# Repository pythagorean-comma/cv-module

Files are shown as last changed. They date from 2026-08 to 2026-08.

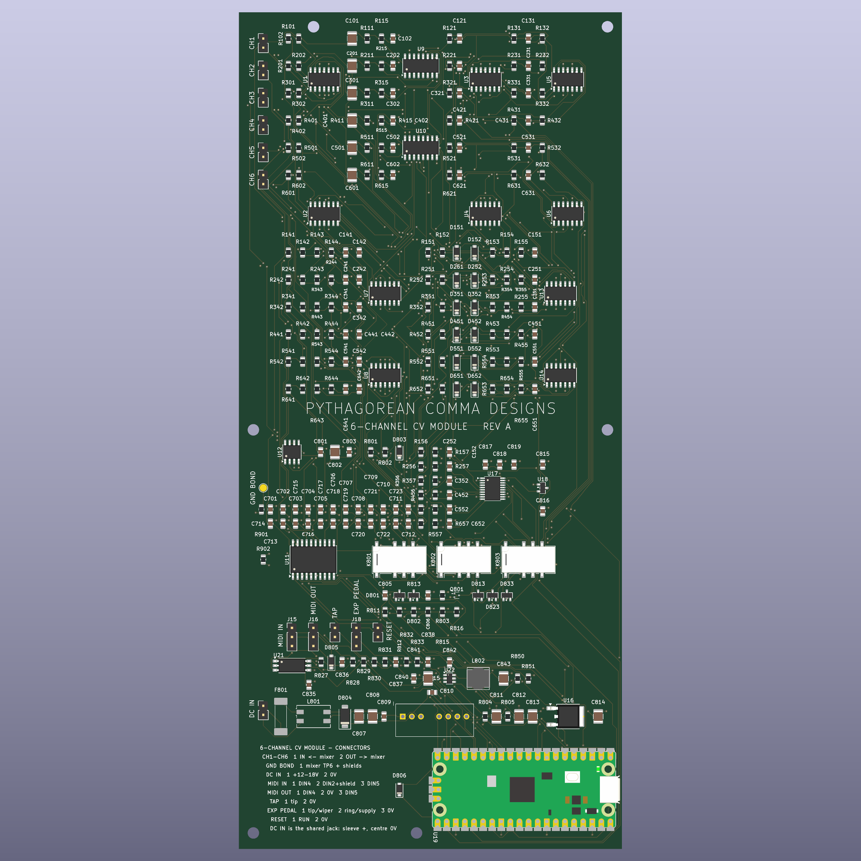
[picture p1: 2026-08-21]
docs/cv-module-top.png

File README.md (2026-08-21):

# cv-module

Per-string CV generation for a six-string guitar effects box: six analogue VCAs
(SSI2164) set per-string levels, and the audio never enters the digital domain.

The module hangs off the six `RV{n}01` level-control positions of
[`summing-mixer`](../summing-mixer), replacing its per-channel trimmers. That
board is **fabricated**, so this repo consumes its interface at a pinned commit
and never writes to it — see [`contract/PINNED.md`](contract/PINNED.md).

```
6 x Nu capsule -> Nexus-GK -> summing-mixer ---- RV{n}01 socket ---- [this]
                                    ^                                  |
                                    +------------ SIN{n} --------------+
```

## Status

Green end to end. `verify.py` passes, `test_verify.py` catches all 112 planted
faults, DRC is at zero, no net is unrouted, and the fabrication package is
written.

| | |
|---|---|
| netlist | 290 parts, 185 nets, 825 pin connections |
| schematic | 0 merges, 0 breaks, 0 stranded pins; ERC clean, `ERC_ALLOWED` empty |
| board | 106.9 × 233.5 mm, 4 layers. 5114 segments, 1142 vias, one track width (0.2 mm), one via size (0.7/0.3), no signal copper on either reference plane |
| routing | every millimetre by KiCadRoutingTools via `krt.py` |
| section 5 constraints | checked mechanically; see `docs/constraints.md` |
| fixings | six, derived from `placement.mounting_deflection()`, each in a plane void |
| silkscreen | title block, connector legend generated from the netlist, 274 designators |
| fabrication package | `fab/` — 9 gerbers, drill, job file, CPL, `ORDER.md` |
| deferred blocks | none. `design.DEFERRED` and `design.UNSPECIFIED` are both empty |

Documents to look at: the [schematic](docs/cv-module-schematic.pdf), the
[layout](docs/cv-module-layout.pdf) one page per copper layer, and a
[render](docs/cv-module-top.png).

**Caveats worth knowing before ordering.** One capacitor is genuinely short on DC
bias — `C840` gives 1.65 µF at 12 V against TI's "2.2 µF or higher" and wants a
higher-voltage part in the same 1210 land. Three Murata lines have no bias curve
here and are reported unchecked. And no check in this repo opens a datasheet: the
netlist comparison is pad number against pin number, so a wrong package passes
everything — see [`footprint-audit.md`](docs/footprint-audit.md), which caught
three.

## Run it

Nothing to install. Stdlib only, following the mixer's own rule that "there is
no `requirements.txt` because there is nothing to install". KiCad 10 is not
optional: `verify.py` runs `kicad-cli` twice, `gen_pcb.py` needs its bundled
Python for `pcbnew`, and `gen_plots.py` plots the schematic, layout and render.

```bash
./build.sh
```

Regenerates the netlist, schematic, project, BOM, generated docs, plots and the
fabrication package, then verifies the board on disk. It never writes the board.
It checks for KiCad first and stops if it is missing; it does not check for
KiCadRoutingTools, because `krt.py` is not one of its stages.

### The three things that do write the board

None of these is in `build.sh`:

```bash
python3 gen_pcb.py --discard-routing   # place, pour and stitch, from nothing
python3 krt.py                         # route it; --commit keeps the result
python3 returns.py                     # add ground stitches; --commit writes
```

`gen_pcb.py` destroys all signal copper. It writes a fresh board with the
footprints placed and the planes poured and nothing else — use it to start again
from nothing, never to make a change. It refuses without `--discard-routing`.

`krt.py` writes a candidate, `out/cv-module-krt.kicad_pcb`; only `--commit`
touches the tracked board. Scope decides what it destroys: `--nets "ENVA*"`
re-lays those six and leaves the rest alone, a bare `python3 krt.py` re-lays
every net.

`returns.py` only adds ground stitches, so it cannot destroy anything. Re-run it
after any re-route. `mounts.py` and `silk.py` are the same shape.

**To move a netlist change onto the routed board**, use KiCad's **Tools → Update
PCB from Schematic** against `out/cv-module.kicad_sch`, which `build.sh`
regenerates. That is the only sync path.

### Toolchain notes

`krt.py` is the one thing here that is not stdlib-only, and it is a subprocess
for that reason — the tool needs numpy, scipy and shapely. Give it an interpreter
of its own, `~/code/KiCadRoutingTools/krt-venv` or `$KRT_PYTHON`; it refuses with
instructions if it cannot find one. See
[`routing-tool.md`](docs/routing-tool.md#installing-the-tools-dependencies).

`gen_pcb.py` re-runs itself under KiCad's bundled interpreter, because `pcbnew`
is a SWIG extension that exists nowhere else, then re-runs `gen_project.py` —
`SaveBoard()` rewrites the project file with KiCad's defaults and takes every
design rule with it.

`contract/socket.py` finds the mixer at `$SUMMING_MIXER`, then
`../summing-mixer`, then `~/code/summing-mixer`. **Keep the two as siblings,
never nested** — and never run `git` from a directory containing both.

## What this repo takes from the mixer, and what it does not

The mixer is a fabricated hardware interface this module references. Referencing
an interface does not mean importing another project's Python:

| | |
|---|---|
| **the interface** — `design.py`, `source.py`, `fab/mechanical-*.json` | read at the pinned commit through `contract/socket.py`, with `git show`. Never copied |
| **the KiCad plumbing** — `sexp` `kisch` `symlib` `kicad` `kisim` | copied into [`toolchain/`](toolchain/PROVENANCE.md). Ours, and modifiable |

The mixer's root is never on `sys.path`. `delta.py` expresses this module's
effect as a delta against the mixer's *own* model, which only works while that
model is the mixer's and not a fork of it.

## What is where

`CLAUDE.md` carries the working rules and the full repo layout. In short:
`design.py` holds the values, derivations and netlist; `verify.py` checks them
against KiCad's own export and `test_verify.py` proves those checks can fail;
`constraints.py` and `delta.py` ask whether the constraints have mechanisms and
what this module costs the existing design; `placement.py`, `krt.py`,
`returns.py`, `mounts.py` and `silk.py` are the board. `docs/` is what a person
reads; `out/` is what another tool reads; `fab/` is what a fabricator is given.

## Open

1. **`MEASURED["noise_floor"]`** — a meter on the mixer's mono output, and the
   only one of the three measurements that can be taken before this board
   exists. It is the most load-bearing unknown here: across its declared range
   the module costs **0.01 dB or 0.79 dB quiescent, 0.08 dB or 3.13 dB while the
   lead feature runs**. It also gates a component value — below 81 µV, `R_IN`
   should move from 12k1 to 7.5 kΩ. [`bench.md`](docs/bench.md).

2. **`MEASURED["mcu_dcdc_efficiency"]` and `["pico_smps_efficiency"]`** — two
   ammeters after fabrication. Confirmations rather than gates: floors of 53 %
   and 45 % against declared ranges starting at 75 and 86. Note that the board
   has no provision for the first — `VA_RAW` has no series element at U22's VIN,
   so that measurement needs a lifted pin or a fitted 0 Ω link. The second is
   free: `D806` is already in series with `VSYS`.

3. **The order form.** `fab/ORDER.md` lists what is not derivable from anything
   here: surface finish, mask and silkscreen colour, electrical test,
   panelisation, IPC class, quantity.

4. **Fiducials and test pads** — not fitted. Three fiducials are derived and
   costed; the test-point case is that no analogue rail and not `MAGND` itself
   has any probe point on the board.

5. **The south-east corner** is 57 mm from its nearest fixing and carries the
   USB socket. Grow the board, move the module, or accept it — all three are
   decisions, so `placement.mounting_reach()` reports the distance rather than
   taking one.

6. **Review the copper.** 844 router vias against an earlier seed's 595 is 33 %
   more perforations of both reference planes for 9.8 % less track. No check
   grades that trade. The recommendation is about scope: re-route a region, not
   the board.

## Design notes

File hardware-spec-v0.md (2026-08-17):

# Hardware spec v0 — per-string CV module

**Purpose:** seed document for a schematic/PCB spike. This is not a design
discussion — the discussion is in the other five files. This is the extracted,
buildable specification, with every value either stated or explicitly marked as
*compute*, and every unknown explicitly marked as *BLOCKED* or *TBD*.

Read `00-current-state.md` for why any of these choices are what they are.

---

## 0. Scope of the spike

**In scope:** the CV generation module — controller, CV chain, envelope sensing,
coarse pad relays, fail-safe. One board.

**Out of scope:** the existing summing mixer (already fabricated), the VCA board
if it ends up separate, the enclosure, the UI panel.

**Deliverable of the spike:** a netlist whose connectivity is machine-checked, all
component values derived rather than guessed, a PCB floorplan with a defensible
ground strategy, and a written list of everything that had to be assumed.

---

## 1. BLOCKED — must be resolved before drawing

Three items. Two of them only Tim can answer.

### 1.1 The module's supply — RESOLVED, see `supply-decision.md`

> **DECIDED.** One shared DC inlet → an **isolated DC-DC at ≥300 kHz** → ±12 V for
> a small audio domain plus +5 V / +3V3 for everything else.
>
> Three reasons, the third decisive:
> 1. **The negative rail only needs ~44 mA**, not ~100 mA — CV and envelopes are
     >    unipolar and run single-supply. Enforce that domain split on the schematic.
> 2. **The mixer already runs a 45 kHz charge pump.** A VCA is a multiplier, so two
     >    supply ripples intermodulate into the audio band. Rule:
     >    **|f_module − 45 kHz| > 20 kHz**, target ≥300 kHz. *Do not use an ICL7660S /
     >    TC1044S with the boost pin — that sets exactly 45 kHz.*
> 3. **Sharing a DC inlet non-isolated creates a second ground bond**, breaking the
     >    "exactly one bond" rule. Isolation preserves it by construction.
>
> Still to look up: the mixer's actual rail voltages and DC input range, from
> `design.py` alongside `NEGATIVE_RAIL_DROP` / `output_swing()` / `clipping_peak()`.

<details>
<summary>Original text, kept for the record</summary>

### 1.1 The module's bipolar supply — genuinely undecided

The SSI2164 needs **±4 V to ±18 V** [S]. The parent doc forbids the module drawing
anything from `VREG`, `V+` or `V−` (*"Every mA on V− costs 65 mV of rail"*). So the
module needs its own bipolar rail, roughly **60–80 mA** with the op-amps — and
nothing in any document decides where it comes from.

| Option | Cost |
|---|---|
| Separate mains inlet, linear ±15 V | Quietest. Second inlet, transformer, board area, heat |
| Single DC inlet + low-noise charge pump for the negative rail | One inlet. A switching aggressor, though at low current |
| Single DC inlet + DC-DC | Smallest. The exact thing the enclosure argument exists to avoid |

**This changes board area, connector count, thermal design and the entire
grounding plan. Decide it before drawing anything.**

</details>

### 1.2 The interface contract with the existing boards

Needed from the existing repo, which I have never seen:

- `RV{n}01` / `CHANNEL_POT_FP = CONN_FP[3]` — connector part, pitch, gender, and
  the exact pin order for `PIN{n}` / `SIN{n}` / `AGND`
- `fab/mechanical-*.json` — board outline, mounting holes, keep-outs
- `DC_BLOCK_VALUE` and the actual `RIN` value, so the 10 kΩ load and the 31.8 Hz
  corner can be checked rather than assumed
- `MEASURED["noise_floor"]` — if it has been measured since

### 1.3 CV architecture — pick one, they are different boards

**Recommendation: PWM.** Fewer parts, no chip-select question, and the filter it
needs is mandatory anyway. But it is a decision, not a default.

| | PWM | DAC |
|---|---|---|
| Parts | 6 MCU PWM pins → 74AHC541 → filter | SPI → DAC → filter |
| CS/framing | none | 8 CS pulses (DAC8568) or one (6× AD5683R chain) |
| Simultaneous update | no (≤33 µs skew, acceptable) | LDAC |
| Extra BOM | 74AHC541 ~£0.30 | DAC ~£10 |

---

### 1.4 The VCA element is no longer settled — but does not block the spike

`element-revisit.md` reopens SSI2164 vs THAT2180 vs **THAT4301**. Summary:

- The control-law argument that originally won it for the SSI2164 is **cancelled by
  the divider ratio** the deep dive later added.
- **Crosstalk is the binding constraint on the lead feature**, and the SSI2164 puts
  four channels on one die. The THAT parts are one channel per package.
- **THAT4301** contains a VCA *and* an RMS detector with a matched 6.5 mV/dB law
  *and* three op-amps — collapsing the analogue compressor (feature 12) and the
  buffer/I–V/servo trio into the same package. Six packages total, against ~7 or
  ~11 for the alternatives.

**This does not block drawing.** All three are current-in/current-out Blackmer-class
parts with identical surrounding topology. Draw with the SSI2164, keep the footprint
choice isolated, and note the variants. Phase 1.5 becomes a three-way bench-off.

**But check the mixer's rail voltages first** — the THAT4301 needs ±7 to ±15 V and
is out below that.

---

## 2. Look up before committing values (does not block topology)

**SSI2164 control-port structure.** Our working figures — *"current-summing node,
nominally 10 kΩ, internal 10:1 divider, −33 mV/dB"* — came from a research pass,
not from a first-hand read. Before fixing any resistor value, confirm from the
datasheet: the actual VC input structure, the recommended summing arrangement, the
input impedance, and the standard **+3300 ppm/°C tempco resistor** practice for the
control divider. Twenty minutes, and it sets half the passive values on the board.

---

## 3. Block diagram

```
  ┌─ from existing mixer, ×6 ────────────────────────────────────────────────┐
  │  PIN{n} ──[ 10k to AGND ]──[ buffer ]──┬──[ pad relays ]──[ SSI2164 ]──► │
  │                                         │                      ▲          │
  │                                         │                   VC{n}         │
  │                        envelope tap ────┘                      │          │
  │  ◄── SIN{n} ──[ DC servo ]──[ I–V ]────────────────────────────┘          │
  └──────────────────────────────────────────────────────────────────────────┘
                    │                                              ▲
              6× rectifier                                  6× CV filter
                    │                                              ▲
              external SPI ADC ──────┐              ┌── 74AHC541 (Vcc = VREF)
                                     ▼              ▲
                                ┌─ RP2040 ─┐   6× PWM
                                │  USB MIDI │
                                │  DIN MIDI │
                                │  tap / exp│
                                └───────────┘
                                     │
                        AC-coupled charge pump ──► bypass relay
```

---

## 4. Block specifications

### 4.1 Channel front end (×6)

| Net / part | Value | Note |
|---|---|---|
| Load to AGND | **10 kΩ** | Replicates the pot. Keeps `DC_BLOCK_VALUE`'s 31.8 Hz corner. **Verify against the real `RIN`** |
| Buffer | JFET or low-noise op-amp, unity gain | Decouples the socket contract from the VCA operating point. Also the envelope tap point |
| Envelope tap | **1 MΩ** series | ≤0.1 dB loading; shifts the corner ~1 % [D] |
| Coarse pad | 0 / −6 / −12 / −18 dB, 2-bit | Latching relays. Keeps the VCA near unity where its noise costs least |
| VCA | **SSI2164**, 2 packages — **but see `element-revisit.md`; this is now a bench decision** | R_IN 30 kΩ after the buffer (datasheet noise condition), R_OUT *compute* |
| I–V + servo | op-amp, servo corner ~1 Hz | `SIN{n}` must be **zero DC by construction** |

### 4.2 CV chain (×6) — the part that most affects the sound

Control noise is **multiplied** into audible AM at **dg/g = −3.48 per volt** [D].
This block matters more than the controller.

| | Spec |
|---|---|
| Filter | **2-pole, 200–400 Hz**, inverting multiple-feedback |
| | The MFB stage does three jobs: anti-AM filter, offset injection (second input resistor from VREF), and buffering the source from the 2164's control node. Use one stage, not three |
| Filter resistors | **≤22 kΩ** so their Johnson noise (19 nV/√Hz) stays ~13 dB under the source |
| Op-amp | OPA1644 (quad JFET, 3.3 nV/√Hz) or OPA4192 |
| Scaling | Source at 0–5 V through **~15 kΩ** into the 10 kΩ control node → ×0.4 → 2 V span and **−8 dB on all source-referred noise** [D]. *Compute exactly once §2 is resolved* |
| Reference | **MAX6126A25 with the 0.1 µF NR cap** (35 nV/√Hz) or ADR4525C/D. Shared by CV source, ADC and the '541 |
| Polarity | Positive CV **attenuates**. Unipolar 0→+V only ever attenuates — no negative rail needed for CV, and code-near-zero is both loudest and quietest |

If PWM: **12-bit, 30.5 kHz carrier** at 125 MHz → 128 µV ripple after the filter =
**0.0039 dB**, step 0.015 dB/LSB [D]. Phase-stagger the six slices so the buffer
transients don't hit the reference together. Local 1 µF + 100 nF at the '541.

### 4.3 Controller

**RP2040.** On-chip LDO, production to 2041, 16 PWM outputs, PIO if the CV
architecture changes to SPI later. Not a module — bare chip plus QSPI flash and a
crystal, so the power architecture is ours.

Control frame rate **8 kHz** (not 32 kHz — the CV filter kills the aggressor
argument; 125 µs grid is 0.12 % of a sixteenth note [D]).

Needs: USB device (MIDI), DIN MIDI in/out, tap footswitch, expression pedal in,
12 GPIO for relay drive, SPI for the ADC.

### 4.4 Envelope sensing

Six precision rectifiers → RC → **external SPI ADC placed in the analogue
section**, so only SCLK/MOSI/MISO/CS cross the analogue–digital boundary rather
than six analogue traces crossing into the digital region.

Parts: **ADS131M08** (8 simultaneous channels, one CS per read) or **MCP3564**
(SCAN mode into a FIFO). 1–2 kHz sampling is sufficient. **Detect pre-gain**, off
the buffer — post-gain makes it a feedback loop that latches shut.

### 4.5 Relay drive and fail-safe

**Coarse pad:** 12 coils (six 2-bit pads). **2× TPIC6B595** shift registers — same
"one SPI burst plus a latch pulse" discipline as everything else.

> **Highest-probability field failure in the design.** These are *level* drivers.
> Dual-coil latching relays need a 3–10 ms pulse and must then be de-energised, and
> a shift register will hold a coil energised until it burns. **Drive the register's
> OE from a one-shot (74LVC1G123)** so maximum coil-on time is set by an RC,
> independent of register contents. One 6-pin part.

**Fail-safe, two stages:**

1. MCU emits ~10 kHz on a GPIO → two-diode charge pump → MOSFET → bypass relay.
   **Any** stuck state — high, low, hi-Z, crashed, halted clock — collapses the pump
   and drops to bypass. Covers the failure a watchdog IC cannot see: firmware alive,
   CV engine wedged.
2. If the CV source is a DAC8568: supervisor reset → **CLR pin, clear-code register
   set to full scale** = maximum attenuation = hardware mute in ~1 µs, long before a
   relay can transfer (~5 ms).

> **Power-on hazard:** a DAC's POR to zero scale = 0 V = **unity gain = fail-loud**.
> The bypass relay must be de-energised (bypassed) at power-up and stay so until
> firmware has written CVs and kicked the watchdog. Same applies to PWM outputs
> idling low. **Design the power-up sequence explicitly.**

---

## 5. Constraints that must not be violated

From the parent doc, and they are load-bearing:

1. **The module draws nothing from `VREG`, `V+` or `V−`.**
2. **Exactly one bond** between module audio ground and board AGND. Six separate
   returns to six pin-3s, **not commoned in the module**.
3. `SIN{n}` carries **zero DC by construction**.
4. `PIN{n}` sees ~5–10 kΩ, or the 31.8 Hz corner moves.
5. Audio as individually-shielded twisted triads, shields grounded at the
   main-board end only.

---

## 6. Do not invent

If a value or part is not in this document and cannot be *derived* from it, stop
and flag it rather than choosing plausibly. Specifically do not invent: the
connector part or pinout (§1.2), the supply topology (§1.1), the SSI2164 control
port structure (§2), `RIN`, or `DC_BLOCK_VALUE`.

---

## 7. Verification expectations

The parent project's culture is that constraints live somewhere a script can see
them. Match it:

- A `verify.py` that checks the netlist against §5 — one AGND bond, no module load
  on `VREG`/`V±`, six separate returns, 10 kΩ presented at each `PIN{n}`
- Every computed value emitted with its derivation, not just its result
- A BOM with a source and a price per line
- An explicit `ASSUMPTIONS.md` listing everything that had to be guessed

---

## 8. Known-unknowns that do NOT block the spike

These affect whether it sounds good, not whether it can be drawn. Note them and
carry on:

- SSI2164 channel-to-channel crosstalk (target ≤−54 dB per pair)
- SSI2164 control-port voltage-noise density (unspecified)
- Whether the 74AHC-powered-from-a-reference topology is sound (no vendor app note)
- Whether a 250 Hz CV filter is fast enough for the gate feel

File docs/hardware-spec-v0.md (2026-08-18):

# Hardware spec v0 — per-string CV module

**Purpose:** seed document for a schematic/PCB spike. This is not a design
discussion. This is the extracted, buildable specification, with every value
either stated or explicitly marked as *compute*, and every unknown explicitly
marked as *BLOCKED* or *TBD*.

Read [`00-current-state.md`](00-current-state.md) for why any of these choices are
what they are.

---

## ⚠ This is v0, and the design has moved past it in places

**Kept unedited on purpose.** It is the baseline the corrections are measured
against, and rewriting a claim in place would destroy the record of what was
specified versus what was derived. So the numbered sections below say what they
said on day one, and **where a claim has been overturned the answer is somewhere
else.** This table is the index; none of it is restated here, because one copy in
one place is the rule the rest of the repo runs on.

| where | what moved | the current answer |
|---|---|---|
| §2, §4.1, §4.2, §4.5, §1.1, §1.4 | seventeen claims, checked against the SSI2164 datasheet read first-hand. Six move a component value or a part count | [`ssi2164-control-port.md` §7](ssi2164-control-port.md#7-corrections-to-hardware-spec-v0md) |
| §5.2 | *"Six separate returns to six pin-3s"* — **struck.** No mechanism: pairwise crosstalk through a single bond is 122 dB below one string against a −54 dB requirement | `CLAUDE.md`, and `design.FRONT_R` for the arithmetic |
| §5.3, §4.1 | *"zero DC by construction"* — restated. A servo is feedback, not construction, and it overstates by three orders of magnitude | `CLAUDE.md` constraint 4 |
| §5.4 | *"or the 31.8 Hz corner moves"* — corrected. 31.8 Hz is the corner at 5 kΩ, one end of the window the sentence quotes | `CLAUDE.md` constraint 3 |
| §5.5 | *"individually-shielded twisted triads"* — demoted from load-bearing to good practice on 59 dB of margin, and a triad here is a pair inside a shield | `CLAUDE.md` constraint 5 |
| §4.2 | *"MAX6126A25 … (35 nV/√Hz)"* — 35 nV/√Hz is the **2.048 V** part. The 2.5 V part is 45 | `design.VREF`, read first-hand |
| §4.1, §4.5 | *"Coarse pad … Keeps the VCA near unity where its noise costs least"* — **struck, and it is the largest deletion in the repo.** The SSI2164's noise rise belongs to R_OUT, which a pad does not move; against the control port, which reaches the same level for no parts, the pad is 0.03–3.9 dB *worse* at the cell and 0.000 dB at the system. 36 parts, 52 % of the courtyard, two thirds of the BOM | `design.pad_benefit()`, `delta.pad_system_delta()` |
| §4.4 | *"**ADS131M08** ... or **MCP3564**"* — decided, and by neither channel count nor price. The ADS131M08's external reference input stops at **1.3 V**, so its full scale at unity gain is 1.20 V against `socket.clipping_peak()`'s 1.233 — it clips 0.24 dB *below* the level it exists to measure, and its minimum gain is 1. The MCP3564 takes VREF up to AVDD, so the board's own 2.5 V reference works and `floorplan.CROSSING_RULE`'s already-written *"the ADC's own reference is VREF"* becomes true | `design.ENV_ADC` |
| §4.4 | *"only SCLK/MOSI/MISO/CS cross"* — **six, not four.** A data-ready line, and a master clock: the MCP3564 multiplexes one modulator across six channels, so its internal RC oscillator — 3.3 to 6.6 MHz, a factor of two — cannot hold 2 kHz per channel at any OSR. That is the multiplexer's bill and it is paid in conductors | `design.envelope_adc_clock()` |
| §4.4 | *"1–2 kHz sampling is sufficient"* — not a range. At 1 kHz the top string's full-wave ripple fundamental is above Nyquist and folds to −29 dB, −33 dB of it near DC. **2 kHz** | `design.envelope_sample_rate()` |
| §4.4 | *"six precision rectifiers → RC"* with no time constant, recorded here as needing a musical target — **it does not, and it is drawn.** A symmetric one-pole has no release bound: 4.7 ms falls 46× faster than the fastest musical decay. Full-wave, on the bow's account, which is 12 op-amp sections against the 6 reserved | `design.envelope_filter()`, `design.envelope()` |
| §4.5 | *"bypass relay"*, singular — **six changeover contacts, not one.** The module replaces six level pots, so bypass is six independent links back. 3 DPDT, and non-latching by mechanism: de-energised must *be* bypass | `design.BYPASS_RELAYS`, `bypass_state()` |
| §4.5 | *"Any stuck state … collapses the pump and drops to bypass"* — true, and it does **not** cover the one fail-loud path. A reference inverter failing to the rail leaves the MCU healthy and the pump up. One Schottky clamp turns +20 dB into +7.4 dB | `design.clamp_gain()`, and the correction at `fail_states()` |
| §4.5 | *"12 coils (six 2-bit pads)"* driven by *"2× TPIC6B595"* — does not close. Dual-coil latching, as §4.1 asks, is 24 coils and 3× registers. **Moot with the pad struck**, and recorded because a spec that does not close arithmetically is worth knowing about | [`ASSUMPTIONS.md`](ASSUMPTIONS.md) |
| §1.1 | *"\|f_module − 45 kHz\| > 20 kHz, target ≥300 kHz"* — **the rule is stated for the pump's fundamental and the mechanism it defends against is not.** The pump's ripple has harmonics at every n × 45 kHz, and the fitted converter's own 522–638 kHz band contains the 12th, 13th and 14th: the nearest beat is **5 kHz**. No switching frequency clears them all. What makes it safe is the isolation and the second-order size of the product | `design.supply_beat()` |
| §1.1 | *"~60–80 mA with the op-amps"*, and `supply-decision.md`'s own *"~44 mA per rail"* — the board draws **110 mA**, and the converter has to deliver **3.87 W** rather than the 3.10 that summing the rail powers gives, because V5 is made linearly from VA+ | `design.supply_requirement()`, `design.supply_fit()` |
| §4.3 | *"Needs: USB device (MIDI), DIN MIDI in/out, tap footswitch, expression pedal in, **12 GPIO for relay drive**, SPI for the ADC"* — five of six, and the sixth went with the coarse pad. What the drawn block actually needs is **19 GPIO of 30**, because the list omits the part's own periphery: two MIDI lines, the tap, the pedal and USB's VBUS sense | `design.CONTROLLER_MAP`, `controller_asks()` |
| §4.3 | *"Not a module — bare chip plus QSPI flash and a crystal, so the power architecture is ours"* — held, and the power architecture is where the block's one open question ended up: the 3.3 V rail is a switcher because two linear rails cannot carry it out of 35.4 mA of +Vout | [`controller.md`](controller.md) |
| §7 | asks `verify.py` to check "six separate returns", which is §5.2 and struck | `verify.check_shield_returns()` holds the half that has a mechanism |

**§6 has not moved and is still binding.** Nothing in the list above was invented
to replace a claim; each is either read from a datasheet or derived, with the
arithmetic in a function.

---

## 0. Scope of the spike

**In scope:** the CV generation module — controller, CV chain, envelope sensing,
coarse pad relays, fail-safe. One board.

**Out of scope:** the existing summing mixer (already fabricated), the VCA board
if it ends up separate, the enclosure, the UI panel.

**Deliverable of the spike:** a netlist whose connectivity is machine-checked, all
component values derived rather than guessed, a PCB floorplan with a defensible
ground strategy, and a written list of everything that had to be assumed.

---

## 1. BLOCKED — must be resolved before drawing

Three items. Two of them only Tim can answer.

### 1.1 The module's supply — RESOLVED, see `supply-decision.md`

> **DECIDED.** One shared DC inlet → an **isolated DC-DC at ≥300 kHz** → ±12 V for
> a small audio domain plus +5 V / +3V3 for everything else.
>
> Three reasons, the third decisive:
> 1. **The negative rail only needs ~44 mA**, not ~100 mA — CV and envelopes are
     >    unipolar and run single-supply. Enforce that domain split on the schematic.
> 2. **The mixer already runs a 45 kHz charge pump.** A VCA is a multiplier, so two
     >    supply ripples intermodulate into the audio band. Rule:
     >    **|f_module − 45 kHz| > 20 kHz**, target ≥300 kHz. *Do not use an ICL7660S /
     >    TC1044S with the boost pin — that sets exactly 45 kHz.*
> 3. **Sharing a DC inlet non-isolated creates a second ground bond**, breaking the
     >    "exactly one bond" rule. Isolation preserves it by construction.
>
> Still to look up: the mixer's actual rail voltages and DC input range, from
> `design.py` alongside `NEGATIVE_RAIL_DROP` / `output_swing()` / `clipping_peak()`.

<details>
<summary>Original text, kept for the record</summary>

### 1.1 The module's bipolar supply — genuinely undecided

The SSI2164 needs **±4 V to ±18 V** [S]. The parent doc forbids the module drawing
anything from `VREG`, `V+` or `V−` (*"Every mA on V− costs 65 mV of rail"*). So the
module needs its own bipolar rail, roughly **60–80 mA** with the op-amps — and
nothing in any document decides where it comes from.

| Option | Cost |
|---|---|
| Separate mains inlet, linear ±15 V | Quietest. Second inlet, transformer, board area, heat |
| Single DC inlet + low-noise charge pump for the negative rail | One inlet. A switching aggressor, though at low current |
| Single DC inlet + DC-DC | Smallest. The exact thing the enclosure argument exists to avoid |

**This changes board area, connector count, thermal design and the entire
grounding plan. Decide it before drawing anything.**

</details>

### 1.2 The interface contract with the existing boards

Needed from the existing repo, which I have never seen:

- `RV{n}01` / `CHANNEL_POT_FP = CONN_FP[3]` — connector part, pitch, gender, and
  the exact pin order for `PIN{n}` / `SIN{n}` / `AGND`
- `fab/mechanical-*.json` — board outline, mounting holes, keep-outs
- `DC_BLOCK_VALUE` and the actual `RIN` value, so the 10 kΩ load and the 31.8 Hz
  corner can be checked rather than assumed
- `MEASURED["noise_floor"]` — if it has been measured since

### 1.3 CV architecture — pick one, they are different boards

**Recommendation: PWM.** Fewer parts, no chip-select question, and the filter it
needs is mandatory anyway. But it is a decision, not a default.

| | PWM | DAC |
|---|---|---|
| Parts | 6 MCU PWM pins → 74AHC541 → filter | SPI → DAC → filter |
| CS/framing | none | 8 CS pulses (DAC8568) or one (6× AD5683R chain) |
| Simultaneous update | no (≤33 µs skew, acceptable) | LDAC |
| Extra BOM | 74AHC541 ~£0.30 | DAC ~£10 |

---

### 1.4 The VCA element is no longer settled — but does not block the spike

`element-revisit.md` reopens SSI2164 vs THAT2180 vs **THAT4301**. Summary:

- The control-law argument that originally won it for the SSI2164 is **cancelled by
  the divider ratio** the deep dive later added.
- **Crosstalk is the binding constraint on the lead feature**, and the SSI2164 puts
  four channels on one die. The THAT parts are one channel per package.
- **THAT4301** contains a VCA *and* an RMS detector with a matched 6.5 mV/dB law
  *and* three op-amps — collapsing the analogue compressor (feature 12) and the
  buffer/I–V/servo trio into the same package. Six packages total, against ~7 or
  ~11 for the alternatives.

**This does not block drawing.** All three are current-in/current-out Blackmer-class
parts with identical surrounding topology. Draw with the SSI2164, keep the footprint
choice isolated, and note the variants. Phase 1.5 becomes a three-way bench-off.

**But check the mixer's rail voltages first** — the THAT4301 needs ±7 to ±15 V and
is out below that.

---

## 2. Look up before committing values (does not block topology)

**SSI2164 control-port structure.** Our working figures — *"current-summing node,
nominally 10 kΩ, internal 10:1 divider, −33 mV/dB"* — came from a research pass,
not from a first-hand read. Before fixing any resistor value, confirm from the
datasheet: the actual VC input structure, the recommended summing arrangement, the
input impedance, and the standard **+3300 ppm/°C tempco resistor** practice for the
control divider. Twenty minutes, and it sets half the passive values on the board.

---

## 3. Block diagram

```
  ┌─ from existing mixer, ×6 ────────────────────────────────────────────────┐
  │  PIN{n} ──[ 10k to AGND ]──[ buffer ]──┬──[ pad relays ]──[ SSI2164 ]──► │
  │                                         │                      ▲          │
  │                                         │                   VC{n}         │
  │                        envelope tap ────┘                      │          │
  │  ◄── SIN{n} ──[ DC servo ]──[ I–V ]────────────────────────────┘          │
  └──────────────────────────────────────────────────────────────────────────┘
                    │                                              ▲
              6× rectifier                                  6× CV filter
                    │                                              ▲
              external SPI ADC ──────┐              ┌── 74AHC541 (Vcc = VREF)
                                     ▼              ▲
                                ┌─ RP2040 ─┐   6× PWM
                                │  USB MIDI │
                                │  DIN MIDI │
                                │  tap / exp│
                                └───────────┘
                                     │
                        AC-coupled charge pump ──► bypass relay
```

---

## 4. Block specifications

### 4.1 Channel front end (×6)

| Net / part | Value | Note |
|---|---|---|
| Load to AGND | **10 kΩ** | Replicates the pot. Keeps `DC_BLOCK_VALUE`'s 31.8 Hz corner. **Verify against the real `RIN`** |
| Buffer | JFET or low-noise op-amp, unity gain | Decouples the socket contract from the VCA operating point. Also the envelope tap point |
| Envelope tap | **1 MΩ** series | ≤0.1 dB loading; shifts the corner ~1 % [D] |
| Coarse pad | 0 / −6 / −12 / −18 dB, 2-bit | Latching relays. Keeps the VCA near unity where its noise costs least |
| VCA | **SSI2164**, 2 packages — **but see `element-revisit.md`; this is now a bench decision** | R_IN 30 kΩ after the buffer (datasheet noise condition), R_OUT *compute* |
| I–V + servo | op-amp, servo corner ~1 Hz | `SIN{n}` must be **zero DC by construction** |

### 4.2 CV chain (×6) — the part that most affects the sound

Control noise is **multiplied** into audible AM at **dg/g = −3.48 per volt** [D].
This block matters more than the controller.

| | Spec |
|---|---|
| Filter | **2-pole, 200–400 Hz**, inverting multiple-feedback |
| | The MFB stage does three jobs: anti-AM filter, offset injection (second input resistor from VREF), and buffering the source from the 2164's control node. Use one stage, not three |
| Filter resistors | **≤22 kΩ** so their Johnson noise (19 nV/√Hz) stays ~13 dB under the source |
| Op-amp | OPA1644 (quad JFET, 3.3 nV/√Hz) or OPA4192 |
| Scaling | Source at 0–5 V through **~15 kΩ** into the 10 kΩ control node → ×0.4 → 2 V span and **−8 dB on all source-referred noise** [D]. *Compute exactly once §2 is resolved* |
| Reference | **MAX6126A25 with the 0.1 µF NR cap** (35 nV/√Hz) or ADR4525C/D. Shared by CV source, ADC and the '541 |
| Polarity | Positive CV **attenuates**. Unipolar 0→+V only ever attenuates — no negative rail needed for CV, and code-near-zero is both loudest and quietest |

If PWM: **12-bit, 30.5 kHz carrier** at 125 MHz → 128 µV ripple after the filter =
**0.0039 dB**, step 0.015 dB/LSB [D]. Phase-stagger the six slices so the buffer
transients don't hit the reference together. Local 1 µF + 100 nF at the '541.

### 4.3 Controller

**RP2040.** On-chip LDO, production to 2041, 16 PWM outputs, PIO if the CV
architecture changes to SPI later. Not a module — bare chip plus QSPI flash and a
crystal, so the power architecture is ours.

Control frame rate **8 kHz** (not 32 kHz — the CV filter kills the aggressor
argument; 125 µs grid is 0.12 % of a sixteenth note [D]).

Needs: USB device (MIDI), DIN MIDI in/out, tap footswitch, expression pedal in,
12 GPIO for relay drive, SPI for the ADC.

### 4.4 Envelope sensing

Six precision rectifiers → RC → **external SPI ADC placed in the analogue
section**, so only SCLK/MOSI/MISO/CS cross the analogue–digital boundary rather
than six analogue traces crossing into the digital region.

Parts: **ADS131M08** (8 simultaneous channels, one CS per read) or **MCP3564**
(SCAN mode into a FIFO). 1–2 kHz sampling is sufficient. **Detect pre-gain**, off
the buffer — post-gain makes it a feedback loop that latches shut.

### 4.5 Relay drive and fail-safe

**Coarse pad:** 12 coils (six 2-bit pads). **2× TPIC6B595** shift registers — same
"one SPI burst plus a latch pulse" discipline as everything else.

> **Highest-probability field failure in the design.** These are *level* drivers.
> Dual-coil latching relays need a 3–10 ms pulse and must then be de-energised, and
> a shift register will hold a coil energised until it burns. **Drive the register's
> OE from a one-shot (74LVC1G123)** so maximum coil-on time is set by an RC,
> independent of register contents. One 6-pin part.

**Fail-safe, two stages:**

1. MCU emits ~10 kHz on a GPIO → two-diode charge pump → MOSFET → bypass relay.
   **Any** stuck state — high, low, hi-Z, crashed, halted clock — collapses the pump
   and drops to bypass. Covers the failure a watchdog IC cannot see: firmware alive,
   CV engine wedged.
2. If the CV source is a DAC8568: supervisor reset → **CLR pin, clear-code register
   set to full scale** = maximum attenuation = hardware mute in ~1 µs, long before a
   relay can transfer (~5 ms).

> **Power-on hazard:** a DAC's POR to zero scale = 0 V = **unity gain = fail-loud**.
> The bypass relay must be de-energised (bypassed) at power-up and stay so until
> firmware has written CVs and kicked the watchdog. Same applies to PWM outputs
> idling low. **Design the power-up sequence explicitly.**

---

## 5. Constraints that must not be violated

> **Four of these five have moved. See the table at the top.** One was struck for
> having no mechanism, two were restated because they overstate what is
> achievable, and one was demoted to good practice on 59 dB of margin. The
> wording below is v0's.

From the parent doc, and they are load-bearing:

1. **The module draws nothing from `VREG`, `V+` or `V−`.**
2. **Exactly one bond** between module audio ground and board AGND. Six separate
   returns to six pin-3s, **not commoned in the module**.
3. `SIN{n}` carries **zero DC by construction**.
4. `PIN{n}` sees ~5–10 kΩ, or the 31.8 Hz corner moves.
5. Audio as individually-shielded twisted triads, shields grounded at the
   main-board end only.

---

## 6. Do not invent

If a value or part is not in this document and cannot be *derived* from it, stop
and flag it rather than choosing plausibly. Specifically do not invent: the
connector part or pinout (§1.2), the supply topology (§1.1), the SSI2164 control
port structure (§2), `RIN`, or `DC_BLOCK_VALUE`.

---

## 7. Verification expectations

The parent project's culture is that constraints live somewhere a script can see
them. Match it:

- A `verify.py` that checks the netlist against §5 — one AGND bond, no module load
  on `VREG`/`V±`, six separate returns, 10 kΩ presented at each `PIN{n}`
- Every computed value emitted with its derivation, not just its result
- A BOM with a source and a price per line
- An explicit `ASSUMPTIONS.md` listing everything that had to be guessed

---

## 8. Known-unknowns that do NOT block the spike

These affect whether it sounds good, not whether it can be drawn. Note them and
carry on:

- SSI2164 channel-to-channel crosstalk (target ≤−54 dB per pair)
- SSI2164 control-port voltage-noise density (unspecified)
- Whether the 74AHC-powered-from-a-reference topology is sound (no vendor app note)
- Whether a 250 Hz CV filter is fast enough for the gate feel

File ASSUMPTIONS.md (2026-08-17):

# ASSUMPTIONS.md

Everything in this repo that had to be guessed, and what each guess costs if it is wrong.

Generated by `gen_assumptions.py`. The numeric entries are pulled from the code — `design.MEASURED`, `design.UNSPECIFIED`, `design.DEFERRED`, `contract.socket.ADAPTED` and `gen_bom.PRICES` — so a guess cannot be resolved in one place and left standing here. The rest are declared in that file, because a reading of a sentence does not fit in a dict of floats.

The discipline is the mixer's. Its `Assumption` class says it plainly: **the range matters more than the value.** The value is a guess; the range is a claim about what the design survives, and `check_assumptions()` fails the build if a value ever falls outside the range it was written around.

## The short version

Two of these would change the board, and the rest would change a number:

1. **`MEASURED['noise_floor']`** — the mixer's own unmeasured figure, which decides whether this module costs 0.11 dB or 0.85 dB with everything open, and 0.56 dB or 3.17 dB while the lead feature is running.
2. **The pad relay** — not chosen, 49 % of the board area and about a third of its cost.
3. **The MAX6126's noise figures**, read from a text mirror rather than Analog Devices' own PDF. They are what overturn the "free 8 dB".

One entry that *was* on this list is now settled rather than open: constraint 2's "six separate returns" has been struck, with the arithmetic, in [Readings of the spec](#readings-of-the-spec).

## Numbers with declared ranges

From `design.MEASURED`, which is the mixer's `Assumption` class reused rather than reimplemented.

### `cv_corner` = 254.7 Hz, 2-pole

**Range:** 200.0 .. 400.0

**Question:** Is a 250 Hz CV filter fast enough for the gate feel? Open question 5 in 00-current-state.md, and it is a judgement by ear rather than a measurement.

**Sets:** the anti-AM filtering, the de-click, and how the gate feels

**When wrong:** Two capacitors per channel. The corner scales as 1/C with the resistors fixed at the <=22k the noise budget wants, so 400 Hz is C1 = 36n / C2 = 15n and nothing else moves. Note the direction of the trade: faster is a worse anti-AM filter and a sharper click, and 00-current-state puts this block at 15-20 dB of the whole noise argument.

### `logic_law_error` = 0.0023 fractional, '541 output-impedance asymmetry

**Range:** 0.0005 .. 0.01

**Question:** How different are the 74AHC541's output resistances high and low, at Vcc = 2.5 V? The asymmetry is a duty-dependent non-linearity in the control law, and the datasheet characterises VOH/VOL at 3.3 V and 4.5 V only.

**Sets:** the linearity of dB against code, and nothing else

**When wrong:** Nothing. It is common to all six channels -- same part, matched -- so it is a law error and not a matching error, and 0.23 % over a 61 dB span is 0.14 dB. Calibratable in firmware from a single measured curve if it ever matters.

### `noise_floor` = 0.000144V rms

**Range:** 5e-05 .. 0.0004

**Question:** What is the residual noise at the mono output with the strings damped and LEVEL at maximum, unweighted over 20 kHz?

**Sets:** whether any further noise work on this box is worth doing

**When wrong:** Near the predicted figure means the source model in source.py is right and the summer is already 29 dB below the thing feeding it. Much lower means the assumed coil resistance and rbb' are pessimistic. Much higher means something is wrong that this model does not describe.

### `servo_vos` = 0.0005 V, servo amplifier input offset

**Range:** 5e-05 .. 0.003

**Question:** What input offset voltage does the servo amplifier actually have? The residual DC on SIN{n} is this figure and almost nothing else -- the loop drives its own offset to the output.

**Sets:** the DC this module leaves on SIN{n}, and therefore whether constraint 3 holds

**When wrong:** See servo_residual(). What the constraint actually protects is DC *current* through the mixer's master wiper, and C703 turns 3 mV at SUM_OUT into 3 nA there -- the same order as the 0.2-1.0 nA the mixer already accepts from its own op-amp. Even the top of this range is comfortable. If it were not, the answer is a zero-drift part in the servo and not a series capacitor: a capacitor would put a second high-pass within a decade of the mixer's own 15.9 Hz, which is what its DC_BLOCK_VALUE comment warns against.

### `vca_rin` = 12100.0 ohm R_IN/R_OUT at the 0 dB pad step

**Range:** 7500.0 .. 20000.0

**Question:** How low can R_IN go before distortion costs more than the noise it buys? The datasheet gives a range and a direction -- 7.5k to 100k, 'lower values will produce the best noise performance at some cost in distortion' -- and no number.

**Sets:** the VCA's output noise, and with it whether this module is audible against the six Nu capsules at all

**When wrong:** Nothing structural: four resistors per channel and R_OUT. How much it matters is decided entirely by the mixer's own noise_floor assumption -- at the predicted 144 uV the whole choice is worth 0.3 dB, and at the optimistic end of its declared range it is worth 0.8 dB. Measure that first; this is downstream of it.

## Inherited from the mixer

Facts this repo takes from `../summing-mixer` at `4bc7ddb`. Their truth is upstream's problem; what is assumed here is only that they still apply.

| | value | upstream | quoted |
|---|---|---|---|
| `AMBIENT_C` | `(0.0, 50.0)` | `design.DIELECTRICS (comment)` | "X5R and X7R differ only in temperature range and both are class II, so both are accepted; a pedal never leaves 0-50 C." |
| `GROUND_STAR` | `R901` | `design._GROUND_RULE` | "AGND and PGND meet at exactly one component, R901, and nowhere else." |
| `WIPER_WORST_OHMS` | `2500.0` | `design.summing_stage_noise` | "It peaks at pot/4 = 2500 ohms at half rotation and is zero at both ends." |
| `MOUNTING_IS_ISOLATED` | `True` | `design.mounting` | "Four plated holes would therefore be four more bridges between AGND and PGND running in parallel with R901." |

`AMBIENT_C` is the one that does work here: 0–50 °C is what decides that the SSI2164's −3300 ppm/°C drift is not worth compensating, and it comes from a comment in the mixer about ceramic dielectrics — *"a pedal never leaves 0-50 C"* — rather than from anything about this module.

## Parts not chosen

- **None** — dual-coil latching DPDT: not named in the spec (section 4.5 names the driver and the one-shot only), and section 6 says not to invent one. Its *pins* are now known -- see RELAY_PINS -- because IEC 60947 contact numbering is a standard and not a part. What the schematic commits to is that whatever relay is fitted follows it.

## Blocks deferred

Not assumptions so much as absences, listed because a section 5 check against a partial board proves less than it appears to.

- **bypass relay and fail-safe** — the AC-coupled charge pump, section 4.5.
- **controller** — RP2040 and its QSPI flash, crystal, USB and MIDI: shared block, and the scope statement puts shared blocks after one channel is complete.
- **envelope ADC** — ADS131M08 or MCP3564, undecided in spec section 4.4.
- **envelope rectifier** — the smoothing time constant is not derivable -- spec section 4.4 gives a sampling rate and no attack/release target. The tap net BUF{n} exists and is driven; the rectifier hangs off it.
- **relay drive** — 2 x TPIC6B595 plus the 74LVC1G123 one-shot, section 4.5.
- **supply** — isolated DC-DC at >=300 kHz per section 1.1; the topology is decided and the part is not.

### Pins waiting on a deferred block

- **relay drive** — 48 pins, `K101.A1` … `K602.B2`. They carry a no-connect flag on the schematic because KiCad has no other way to write "connected by a block that is not drawn yet", and `verify.check_open_pins()` is what stops the flag from being read as final. **The board must not be fabricated while this list is non-empty.**

The relay coils are also a **spec correction**, recorded and not acted on. Section 4.5 says "12 coils (six 2-bit pads)" driven by "2 × TPIC6B595" — 16 outputs. Twelve coils is twelve *single*-coil relays, and a single-coil latching relay latches by reversing its coil polarity, which needs a bridge; the TPIC6B595 is an open-drain sink and cannot reverse anything. With the dual-coil latching part section 4.1 asks for, six 2-bit pads are 12 relays and **24 coils, which is 3 × TPIC6B595 exactly**. Not acted on because the relay is in `design.UNSPECIFIED`, the coil supply voltage is a property of the relay, and section 6 says not to invent one. See `design.DEFERRED_PINS`.

## Readings not taken

### The `MAX6126A25` pin map.

**Basis:** Not read. The part is chosen on its noise figure and its voltage, both of which came from the datasheet's electrical table via a text mirror rather than from the PDF itself.

**Affects:** U12's four connections are pin *roles* in the netlist -- `<VIN>`, `<VOUT>`, `<GND>`, `<NR>` -- and design.check_pin_numbers() refuses to let a number be invented for them.

**If wrong:** Nothing silently. The netlist is not loadable by KiCad until they resolve, which is the intended state.

**To settle:** Open the MAX6126 datasheet and fill in design.UNSPECIFIED's entry.

### The MAX6126's noise figures per output voltage.

**Basis:** Read from a text mirror of the datasheet (pdf.datasheet.live), not from Analog Devices' own PDF, which timed out three times. The figures are internally coherent -- noise scales almost exactly with output voltage -- and one of them (35 nV/rtHz at 2.048 V) is corroborated by an independent search result.

**Affects:** The whole of correction 5: whether the '0-5 V through 15k' scaling buys 8 dB or nothing. The answer turns on 45 nV/rtHz at 2.5 V against 95 at 5 V.

**If wrong:** If the scaling really is proportional to voltage, nothing changes. If the 2.5 V part is quieter than 45 nV/rtHz relative to the 5 V part, the 5 V option becomes worth something again -- and it is still blocked by the '541's input threshold, so the conclusion is robust even if the numbers move.

**To settle:** Fetch the ADI PDF when it is reachable and check the two rows.

### The OPA1644's input offset voltage.

**Basis:** Not read. `MEASURED['servo_vos']` assumes 0.5 mV with a declared range of 0.05 to 3 mV, which is wide enough to cover any JFET quad.

**Affects:** The residual DC on SIN{n}, which is constraint 3.

**If wrong:** Nothing, across the whole declared range: servo_residual() shows the worst case still lands at nanoamps through the mixer's master wiper, against the 0.2-1.0 nA it already accepts.

**To settle:** One line of the OPA1644 datasheet. Worth doing when the BOM is finalised anyway.

### The 74AHC541's output impedance at Vcc = 2.5 V.

**Basis:** The datasheet characterises VOH/VOL at 3.3 V and 4.5 V only. `MEASURED['logic_law_error']` extrapolates.

**Affects:** The linearity of dB against code -- a duty-dependent bend in the control law.

**If wrong:** Nothing structural. It is common to all six channels, so it is a law error rather than a matching error, and 0.23 % over a 61 dB span is 0.14 dB. Calibratable in firmware from one measured curve.

**To settle:** Measure V_C against duty on one channel, once.

## Modelling assumptions

### The SSI2164's output noise is flat across the band.

**Basis:** The datasheet publishes four points in dBu over 20 Hz to 20 kHz unweighted, and no spectrum at all. vca_noise() converts a total to a density by assuming it is flat.

**Affects:** Every noise figure this repo quotes for the VCA, and therefore the whole of delta.py's system arithmetic.

**If wrong:** If the part has significant 1/f, the density at low frequency is higher than modelled and the figures are optimistic where the instrument's fundamentals are.

**To settle:** A spectrum analyser on one channel at Phase 1. This is worth adding to the phase-1 bench list, which currently only has feedthrough, noise and law drift on it.

### The datasheet's noise figures apply at pad steps other than 0 dB.

**Basis:** The table's stated condition is R_IN = R_OUT, which is true only at the 0 dB step. The other three raise R_IN and leave R_OUT alone, and vca_noise() is called with the base value throughout.

**Affects:** The noise figures at -6, -12 and -18 dB, which are not computed anywhere.

**If wrong:** The pad steps are noisier than modelled -- but they are used when the source is hot, so the signal is larger by the same amount. This is what any pad costs and it is not specific to this arrangement.

**To settle:** Measure, or accept. It does not change a component value.

### The SSI2164 noise table already includes an I-V amplifier.

**Basis:** The specification conditions say 'using Figure 1 circuit without diode', and Figure 1 contains a 1/2 TL072 and both resistors. So channel_noise() adds no separate I-V term.

**Affects:** Whether delta.py double-counts the largest contributor.

**If wrong:** If the figure is somehow the cell alone, this repo *under*-counts by an op-amp and a resistor -- about 15 nV/rtHz, which would raise the gating penalty by roughly 0.1 dB.

**To settle:** It is a reading of the conditions line and it is a confident one. Left as an assumption because it is load-bearing, not because it is doubtful.

### X7R is acceptable for the CV filter's 56 nF and 22 nF.

**Basis:** Assumed, not computed. At 2 V on a 50 V part the bias derating is a few per cent and f0 goes as 1/sqrt(C1 C2), so the corner moves a per cent or two.

**Affects:** The CV filter's corner and Q, and therefore the anti-AM figure.

**If wrong:** Nothing audible: a 2 % shift on a 255 Hz corner. The reason it is recorded is that this design names C0G explicitly everywhere it matters, and these two are the only signal-adjacent parts that are not C0G -- because C0G at 56 nF is a much larger package.

**To settle:** Compute the bias curve for the specific part, or fit film and take the area.

### Courtyard areas and a packing factor of 2.5.

**Basis:** The areas are from the footprint names; the relay is a 14 x 9 mm envelope for a part that is not chosen; the packing factor is a judgement.

**Affects:** floorplan.area(), and the finding that the module is 1466 mm2 larger than the mixer's whole outline.

**If wrong:** The area conclusion survives a wide error, because the shortfall is 24 %. It stops being interesting now the enclosure is bespoke.

**To settle:** Nothing to settle. Superseded by the enclosure decision.

## Firmware assumptions

### Firmware emits the complement of the level.

**Basis:** Required by 'code 0 = loudest' with the datasheet's Figure 10 topology: V_C is the *difference* between V_REF and the '541's output, so the loud end is 100 % duty.

**Affects:** Nothing in hardware -- the board is identical either way. Only which direction a firmware variable counts.

**If wrong:** The control law runs backwards. Obvious in a second at the bench.

**To settle:** One line, and it is written down here because it is the kind of thing that gets lost between a schematic and a firmware repo.

### The six PWM slices can be phase-staggered.

**Basis:** Spec section 4.2 asks for it and the RP2040's PWM slices have independent counters, so it should be available. Not verified against the datasheet or the SDK.

**Affects:** The reference's transient load: staggering divides the peak by six.

**If wrong:** Little. The arithmetic in REFERENCE_PLACEMENT shows the transient is 19 uA against the MAX6126's 10 mA, so the stagger is a free improvement rather than a requirement.

**To settle:** Check the RP2040 datasheet when the controller block is drawn.

### A 3-10 ms coil pulse is what the latching relays need.

**Basis:** From spec section 4.5, which states it without a part. Used in floorplan.py's current argument and nowhere else.

**Affects:** The one-shot's RC, which is not designed yet.

**If wrong:** Nothing here. It is the relay's specification and arrives with the relay.

**To settle:** Choose the relay.

## Readings of the spec

### Constraint 2's "six separate returns to six pin-3s" has been **struck**, not interpreted.

**Basis:** It was generated in an earlier session answering a question about power, not derived from a measurement or a datasheet, and was then written into CLAUDE.md under "load-bearing constraints" -- which is what made it unquestionable. Per-channel returns exist to prevent shared-impedance crosstalk; computed for this module with a single bond carrying all six channels, pairwise crosstalk is 122 dB below one string on a 100 mm bond and 103 dB on a deliberately bad one, against a -54 dB requirement.

**Affects:** The front-end topology. It was a four-resistor difference amplifier to satisfy the clause literally; it is now a two-resistor inverting stage, and the loom is a shielded pair rather than a triad.

**If wrong:** Nothing measurable either way -- the two topologies differ by 0.008 dB of system noise, because the VCA's 62 nV/rtHz swamps the front end. What was at stake was twelve resistors and a matched-set requirement, spent to satisfy a sentence with no mechanism behind it.

**To settle:** **Settled.** The half of the constraint that has a mechanism -- exactly one bond, which is the mixer's own _GROUND_RULE applied across the connector -- is kept and checked. The half that does not is gone, and design.FRONT_R carries the arithmetic. Constraint 5's "triad" becomes "twisted pair inside an individual shield".

### The ground bond lands on the mixer's TP6.

**Basis:** TP6 is the mixer's own AGND test pad and its comment calls it 'the *only* correct one, given the ground rule'. Nothing in the mixer designates a bond point, because nothing was expected to bond to it.

**Affects:** Where one wire is soldered, and the loom's geometry.

**If wrong:** Any AGND point works electrically. TP6 is chosen because it is the one the mixer itself designates.

**To settle:** Its coordinates are not in fab/mechanical-summing-mixer.json -- test pads are not tall parts -- so they have to be read off the board or the .kicad_pcb before the loom is made.

### The six triad shields land at the bond point too.

**Basis:** Constraint 5 says shields are grounded at the main-board end only and does not say where. Grounding them at the bond keeps every shield at the same potential as the module's own reference.

**Affects:** The loom's construction.

**If wrong:** Grounding them at six separate pin-3s would work too, and would put six shield currents into six different points of the mixer's AGND pour. The single point is the more conservative choice.

**To settle:** A loom decision, not a board one.

### 3 + 3 across the two SSI2164 packages, not 4 + 2.

**Basis:** Crosstalk is a within-die property and is the binding constraint on the lead feature. 3 + 3 gives every string two die-mates; 4 + 2 gives four strings three and two strings one.

**Affects:** Which channel is which cell, and the floorplan.

**If wrong:** Nothing measurable until Phase 1.5 measures crosstalk. If it comes back far better than -54 dB the arrangement stops mattering.

**To settle:** Phase 1.5, which is already on the staging list for exactly this.

### Op-amp sections are grouped by block, not by channel.

**Basis:** Four sections per channel would put one quad per channel, which is tidy and puts a 30.5 kHz CV filter on the same die as an audio front end. Grouping by block keeps them apart at the cost of eight packages with one spare section.

**Affects:** design.SECTIONS, and the floorplan's zone layout.

**If wrong:** Provisional. This is the one table in design.py the floorplan may move, and moving it changes no values.

**To settle:** Settled when the board is laid out.

## Supply

### The module's audio rails are +/-12 V.

**Basis:** Spec section 1.1 decides the topology -- isolated DC-DC at >=300 kHz, +/-12 V for a small audio domain -- and the DC-DC part is not chosen.

**Affects:** die_rise(), which is 118 C/W x 24 V x 6 mA = 17 C, and therefore the tempco span. Also the CV filter op-amp's ability to output exactly 0 V, which needs a negative rail.

**If wrong:** A lower rail lowers the die temperature and narrows the tempco span, which is the direction that helps. A single supply would break the 0 V requirement outright.

**To settle:** Choose the DC-DC. Note the SSI2164 spans +/-4 to +/-18 V, so the rail is not tightly constrained by the VCA.

### The offset reference is stable enough.

**Basis:** Rossum's Note 3 wants the negative reference 'temperature stable to 100 ppm/degC'. This design inverts the +2.5 V reference through one op-amp section and two 0.1 % resistors, and the resulting drift has not been computed.

**Affects:** The zero point of the control law -- what V_C is at the loud end, and therefore whether unity gain is really unity.

**If wrong:** A common-mode gain error, not a matching error, because all six channels share the one inverted reference. Probably invisible; unverified.

**To settle:** Compute the inverter's drift from the resistors' tempco and the op-amp's, against the 100 ppm/degC Note 3 asks for.

## Prices

Of 34 BOM lines, **1 carries a price read from a page fetched in this session**. 2 come from search results quoting a distributor without the page being opened, and 31 are typical bands for the class — estimates, labelled as such in the `basis` column of `out/cv-module-bom.csv`.

The totals in `docs/SHOPPING.md` are therefore a range, and the range is honest rather than decorative. They are also a floor: none of the deferred blocks is costed.

## What is not assumed

For contrast, because a document of guesses can make a design look less settled than it is. These were derived or read, and each has its arithmetic in the repo:

- The **control law** — −33 mV/dB, the 9k:1k divider, the 9/10/11 kΩ tolerance and dg/g = −3.488 per volt, all from the datasheet, with the constant re-derived from q/kT to 2.4 %.
- **Class AB** — pin 1 open, from three separate statements in the datasheet, worth 12 dB and better control feedthrough.
- **V_REF ≤ 4.71 V** — from the '541's VIH against a 3.3 V GPIO. This is what rules out the 5 V reference and it is arithmetic, not preference.
- **R_OFF = R1** — the exact-cancellation condition, not a value.
- **The CV chain is fail-silent** — every fault drives the '541 output toward 0 V, which is full attenuation, because the offset current comes from neither the MCU nor the reference that feeds it.
- **The MAGND star is at the SSI2164 ground pins** — because the control port is ground-referenced, so 1 mV in the wrong place is AM 51 dB below the signal.
- **The five section 5 constraints** — checked mechanically by `verify.py`, and `test_verify.py` plants fourteen faults to prove the checks can fail.
- **Every pin map in the netlist except the MAX6126's** — SSI2164, OPA1644 and SN74AHC541 were each read off their own pin-configuration tables in this session.

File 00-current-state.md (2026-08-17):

# Per-string level control — current state

**Read this first.** Five documents have accumulated, each correcting the last, so
several confident-sounding passages in the earlier files are now wrong. This page
is the single authoritative statement of what we currently believe. Where a
document contradicts this page, this page wins.

Last revised: after the DAC8568 SYNC correction.

---

## Reading order

| # | Document | Status |
|---|---|---|
| 0 | `dynamic-string-levels.md` | **Parent doc, unmodified.** Forks Layer 1 into motorised faders (A) vs electronic attenuator (B) |
| 1 | `option-b-programmable-attenuator.md` | Element choice. **Element analysis stands; control-architecture numbers superseded** |
| 2 | `option-b-controller-and-pattern-engine.md` | Pattern engine + controller. **Engine stands; hardware half superseded** |
| 3 | `option-b-sequenced-gating.md` | The lead feature. **Current** |
| 4 | `phase-0.75-vcv-rack-patch.md` | Live patch for the real-time test. **Current** |
| 5 | `option-b-controller-deep-dive.md` | Controller/CV architecture, done rigorously. **Current — supersedes 1 and 2 on hardware** |

Code: `hexsim/hexsim.py` (offline simulator), `hexsim/hexengine.c` (portable
engine core), `hexsim/demos/` and `hexsim/demos-arp/` (rendered audio).

---

## The state of every live decision

### Musical

| | Current position |
|---|---|
| **Lead feature** | **Sequenced per-string gating.** Reads as a sequence of *timbres at constant level*, not a chopped rhythm — the arpeggio pattern opens exactly one string per step, so summed gain is constant (measured 1.0500 min and max) |
| Drone bed | Depth is really a "how much chord stays present" knob. Useful range **15–35 dB**; below ~14 dB the pattern vanishes into the chord |
| Polymeter | Six rows on their own loop lengths {5,7,4,3,8,6} → 840 steps, 105 s at 8 steps/s vs 2 s for a fixed 16-step row. One modulo per string |
| Rhythm → timbre boundary | Where step period approaches pitch period: ~41 steps/s for low E. Features 4 and 9 are the same feature at different rates |
| Tremolo phase spread | Weaker than first claimed. The 60°/120° null needs the strings **level with each other**, not steady in time — 9.85 dB residual with a realistic source, and *no null at all* on an ebow-like source |
| Sustain | The texture needs it. A plucked chord is 16 dB down within a few bars |
| Prior art | Moog Guitar did per-string sustain and muting; Vo-96 per-string harmonics; hex distortion exists. **Sequenced per-string amplitude as the primary effect** looks genuinely uncommon |

### The two arithmetic laws that govern gating

Both were wrong in the earlier docs, which used +14 dB for each:

- **Intentional attenuation** — five shut strings are *uncorrelated*, so they power-sum: **+10·log₁₀(5) = +7 dB**
- **Channel crosstalk** — five *copies of one source*, so they voltage-sum: **+20·log₁₀(5) = +14 dB**

For 40 dB of musical gate depth: per-channel depth **≥47 dB**, per-pair isolation
**≤−54 dB**. Crosstalk remains the binding constraint and the thing to measure.

### Hardware

| | Current position | Was |
|---|---|---|
| **Element** | **SSI2164** quad VCA, −33 mV/dB. Unchanged | — |
| **Controller** | **RP2040** (on-chip LDO, production to 2041) or STM32G474. Top three within 4 points — the choice barely matters | Teensy 4.1 / RP2350B — *both fail the switching-regulator gate* |
| **CV generation** | **PWM + 74AHC541 from a precision reference** → 6× AD5683R daisy-chained → DAC8568 with 8 CS pulses | DAC8568 in a single-SYNC burst — *not possible, `t4` min SYNC HIGH = 80 ns* |
| **Control frame rate** | **8 kHz** | 32 kHz — the aggressor argument dies once the CV filter exists |
| **CV filter** | **2-pole, 200–400 Hz, per channel. Mandatory.** Worth 15–20 dB of AM noise and doubles as the de-click | 2 kHz single-pole, treated as cosmetic |
| **Resolution** | **Non-issue.** 10-bit = 0.074 dB/LSB on a dB-linear port | 12 vs 16 bit analysed at length |
| **Dominant noise mechanism** | **Multiplicative** — control noise × 3.48/V, breathing with the signal | Additive, from the VCA |
| **Envelope ADC** | **External SPI ADC** in the analogue section (ADS131M08 / MCP3564) | On-chip; drove the wrong "must be RP2350B" conclusion |
| **Reference** | 35–41 nV/√Hz (MAX6126 + NR cap, or ADR4525C/D), shared by DAC and ADC. Reference noise is **correlated across strings**, so it is the most perceptible kind | Not considered |
| **Feature 12, compression** | **Analogue sidechain.** dB-out RMS detector (6.1 mV/dB) into the dB-in port ⇒ ratio is one resistor ratio | Software, in the sensing layer |
| **Fail-safe** | **AC-coupled charge pump** driving the bypass relay (any stuck state drops it) + DAC CLR-to-full-scale = hardware mute in ~1 µs | Watchdog + latching relay |
| **Gain staging** | Coarse switched passive pad (latching relays) + VCA near unity. Unchanged | — |
| **Buy vs build** | **Build bespoke.** Nothing off-the-shelf survives the no-switcher rule | Not examined |

### The three things that most affect how it sounds

None is the controller, and none is DAC resolution:

1. **A 2-pole 200–400 Hz low-pass on every CV**, as an inverting MFB stage that also
   injects the offset and buffers the DAC from the 2164's 10 kΩ divider. ~15–20 dB.
2. **Summing-resistor scaling** — DAC at 0–5 V through ~15 kΩ into the 10 kΩ node
   rather than 0–2 V direct. **Free 8 dB for one resistor value.**
3. **A 35–41 nV/√Hz reference**, because its noise is common to all six strings.

---

## Staging

| Phase | What | Cost |
|---|---|---|
| **0.5** | Record hex stems, run `hexsim.py --stems`. Musical go/no-go | £0 |
| **0.75** | Same rig live, in VCV Rack. *Would I actually play this?* | £0 |
| 1 | One SSI2164 channel. **Feedthrough test first**, then noise, then law drift | ~£15 |
| 1.5 | Second channel on the same die. **Measure crosstalk** — caps the whole gating feature set | ~£5 |
| 2 | Six channels + controller + sensing layer + editor | |
| 3–6 | Fader decision, loom, enclosure, failure modes | |

---

## Open questions, ranked

1. **SSI2164 channel-to-channel crosstalk.** Not on the datasheet; binding on
   features 4, 5, 6 and 11. Target ≤−54 dB per pair.
2. **SSI2164 control-port voltage-noise density.** Not specified. Every AM-noise
   figure assumes the external source dominates.
3. **Does the 60° spread null survive per-string level normalisation?** If feature
   12 is running, the strings *are* level, so the null may return.
4. **Whether the 74AHC-powered-from-a-reference topology is sound.** No vendor app
   note exists; the reasoning is sound but unpublished.
5. **Whether a 250 Hz CV filter is fast enough** for the gate feel you want.
6. Whether 1–2 kHz envelope sampling is enough for the swell to feel responsive.

---

## Corrections log

Every claim overturned so far, so the pattern is visible.

| # | Claim | Verdict | Found by |
|---|---|---|---|
| 1 | THAT2180 at 55 nV/√Hz | 89 nV/√Hz from the datasheet | self-check |
| 2 | Phase 1 answers the musical question | It answers the *engineering* question; Phase 2 answers the musical one | self-check |
| 3 | Option B deletes the supply problem | It still needs a bipolar analogue supply | self-check |
| 4 | Control frame rate is audibly binding | 2 kHz to 32 kHz indistinguishable | measurement |
| 5 | Edge slew is the feedthrough mitigation | Buys ~6 dB. Constant-sum patterns buy 25.6 dB | measurement |
| 6 | Five shut strings sum at +14 dB | +7 dB (power sum). +14 dB is crosstalk only | measurement |
| 7 | Spread-60° null gives 4.2 dB | 9.85 dB with a realistic source | **user's ear** |
| 8 | The synthesised source decayed like a guitar | No pick transient at all; it swelled into the note | **user's ear** |
| 9 | Teensy 4.1 / RP2350B for the controller | Both have mandatory buck converters | deep dive |
| 10 | The MCU is the load-bearing choice | The DAC is; and then neither, really | deep dive |
| 11 | DAC8568 can stream frames under one SYNC | It cannot — `t4` min SYNC HIGH = 80 ns | **user reading the datasheet** |
| 12 | PWM loses on cost and accuracy | Leading option once the CV filter is mandatory anyway | consequence of 11 |

Three of the twelve came from Tim rather than from me, and two of those three
(7, 8) came from listening rather than from analysis. Worth noting as a working
pattern: **the renders are the most reliable error detector in this project.**

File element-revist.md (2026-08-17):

# The element choice, revisited

Short answer: **no, we are not certain — and the SSI2164 recommendation is weaker
now than when it was made, because the lead feature changed afterwards.**

The original case (`option-b-programmable-attenuator.md`) rested on four arguments.
Two have since been eroded, one was never weighted, and a third part has appeared
that was not in the comparison at all.

---

## 1. My headline argument was largely wrong

The original recommendation led with the control law: −33 mV/dB against 6.1 mV/dB
is 5.41×, *"14.7 dB of extra immunity in the control domain"*, and I weighted it
first.

**That advantage is mostly cancelled by the divider ratio** [D]:

| | mV/dB | CV span for 66 dB of range |
|---|---|---|
| SSI2164 | 33.0 | **2.178 V** |
| THAT2180 | 6.1 | **0.403 V** |
| THAT4301 | 6.5 | 0.429 V |

A 2180 needs **5.41× less CV span**, so you divide the source down 5.41× harder —
and that attenuates source-referred noise by exactly the same factor. The law
advantage and the divider ratio cancel.

What actually survives is only what is added **after** the divider: the CV filter
op-amp's own output noise, pickup on the short run to the VC pin, offset drift and
thermal EMF. With a low-impedance MFB output, that is small.

I made this argument before the CV chain had a divider in it. Once the deep dive
added the summing-resistor scaling, it stopped being true.

---

## 2. The argument I never weighted, which now matters most

**Crosstalk is the binding constraint on the lead feature.** Sequenced gating
became the headline *after* the element was chosen, and gate depth is capped at
per-pair isolation + 14 dB:

| Musical gate depth | Per-pair isolation needed |
|---|---|
| 30 dB | ≤ −44 dB |
| 40 dB | ≤ −54 dB |
| 45 dB | ≤ −59 dB |

| | Channels per die | Crosstalk exposure |
|---|---|---|
| **SSI2164** | **4** | **On-die. Not on the datasheet. Unmeasured** |
| THAT2180 | 1 | Board-level only |
| THAT4301 | 1 | Board-level only |

Board-level isolation at audio frequencies is a layout problem you control. On-die
isolation is whatever the die gives you, and no amount of good layout fixes it.

**A quad VCA is structurally the wrong shape for a design whose headline feature is
per-string gating.** That is an uncomfortable sentence to write about a part I
recommended, but it follows directly.

### The honest counter-argument

Same-die channels **match better**, and matching is what sets the residual for the
constant-sum feedthrough cancellation — ±30 % gives 25.6 dB of rejection, ±10 %
gives 9.6 dB more. Six separate packages will match worse than four channels off
one die.

So it is a genuine trade: **on-die buys matching (a bonus), separate packages buy
isolation (a ceiling).** Ceilings beat bonuses — a bonus you lose is 10 dB of
feedthrough rejection you can trim back at build; a ceiling you hit means the
gating features never sound absolute.

---

## 3. Noise and distortion, on a common basis

| | Noise | vs 2180 | THD |
|---|---|---|---|
| THAT2180 | **89.1 nV/√Hz** (−98 dBV @ 0 dB, R_OUT 20 k) | — | **0.005 %** (A grade) |
| THAT4301 | 112.1 nV/√Hz (−96 dBV @ 0 dB, 20 k load) | +2.0 dB | **0.003 %** |
| SSI2164 | 122.7 nV/√Hz (−93 dBu, R 30 k) | **+2.8 dB** | **0.050 %** (class AB) |

Two things I under-weighted:

- **2.8 dB of noise**, in a design where we have been fighting for 8 dB from a
  single resistor value.
- **10× the distortion.** The SSI2164 can reach 0.025 % in class A, but that costs
  **12 dB of noise** (−93 → −81 dBu) [S] — a bad trade here. The THAT parts get
  0.003–0.005 % with no such penalty. The parent doc's whole character is a box
  that is "0.55 dB from theoretical"; 0.05 % is out of keeping with it.

*(Note: none of these conditions are like-for-like on resistor values. Directional,
not decisive.)*

---

## 4. The part that was not in the comparison: THAT4301

The **THAT4301 "Analog Engine"** contains, in one package [S]:

- a Blackmer VCA at **6.5 mV/dB**
- an **RMS-level detector whose output scale factor is also 6.5 mV/dB**
- **three general-purpose op-amps**

Look at what that collapses. The bipolar domain in the current spec is *six
buffers, six I–V converters, six servos and two VCA packages*. One 4301 per string
provides the VCA **and** the three op-amps that do exactly those three jobs:

| | Packages for six channels |
|---|---|
| SSI2164 + discrete op-amps | 2 VCA + ~5 quad op-amp = **~7** |
| THAT2180 + discrete op-amps | 6 VCA + ~5 quad op-amp = **~11** |
| **THAT4301** | **6** |

And the detector is the decisive part. The deep dive concluded that **feature 12
(per-string compression) should be analogue**, because a dB-out detector feeding a
dB-in control port makes the compression ratio a single resistor ratio. The 4301's
detector law is **deliberately matched to its own VCA law** — 6.5 mV/dB into
6.5 mV/dB. It is the exact architecture we arrived at independently, sold as one
part.

Feature 12 is load-bearing three separate ways by now (sustain, thermal drift, and
the spread-null needing level-matched strings). A part that provides it for free is
worth a lot.

**Caveat: the 4301 needs ±7 to ±15 V** [S], narrower than the SSI2164's ±4 to ±18.
If the mixer's rails turn out lower than ±7, the 4301 is out — another reason the
mixer's actual rail voltages are the first thing to check.

---

## 5. Cost, which is not decisive

| | Six channels |
|---|---|
| SSI2164 | 2 × £3.80 = **£7.60** (Thonk, in stock) |
| THAT2180 | 6 × £7.87 = **£47.22** (Farnell UK, 435 in stock) |
| THAT4301 | not checked — **look this up** |

£40 on a one-off build you intend to keep. The 4301 additionally deletes perhaps
£15–25 of op-amps, narrowing it further. This is not the axis to decide on.

---

## The recommendation

**Do not switch on this analysis. Make it a bench decision, and change what Phase
1.5 measures.**

The DAC8568 episode is the relevant precedent: a confident paper conclusion, built
on a plausible reading, overturned by one number in a datasheet. The number that
decides this one is **SSI2164 channel-to-channel crosstalk**, and it is not
published.

- If it comes in at **≤ −60 dB per pair**, the 2164 is fine, its density and price
  advantages hold, and nothing changes.
- If it is nearer **−45 dB**, musical gate depth is capped around −31 dB, the lead
  feature is compromised, and the part is wrong for this design.

### Changes to the plan

1. **Phase 1.5 becomes a three-way bench-off**, not a single-part crosstalk check:
   one channel each of SSI2164, THAT2180 and THAT4301. Measure crosstalk, noise,
   control feedthrough, and channel matching on all three. Budget ~£70 rather than
   £5. That is cheap against committing a PCB to the wrong element.
2. **The spike is not blocked.** All three are current-in/current-out Blackmer-class
   parts with the same surrounding topology — local I–V, CV divider, servo. The
   schematic is architecturally identical; only the footprint and two resistor
   values change. **Draw it with the SSI2164 and note the variants**, exactly as the
   original doc intended when it said the element choice should live behind one
   resistor.
3. **Check the mixer's rail voltages early.** If they are below ±7 V the 4301 is
   out before the bench-off starts.
4. **Look up the THAT4301 price and availability**, the one input missing here.

### If I had to guess the outcome

The 4301 wins, on the strength of collapsing feature 12 into the same package and
removing on-die crosstalk in one move. But that is a guess, it contradicts a
recommendation I made confidently three documents ago, and the last two times a
guess of mine met a datasheet the datasheet won. **Measure it.**

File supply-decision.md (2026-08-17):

# The module's supply — decision

Resolves `hardware-spec-v0.md` §1.1, the last genuine blocker before the schematic
spike.

**Recommendation: one shared DC inlet, an isolated DC-DC for the module, and split
the module into a small bipolar audio domain and a larger single-supply digital/CV
domain.**

Three findings drive it, and the third is decisive.

---

## 1. The negative rail is half the size you'd assume

A naive op-amp count gives ~100 mA per rail, which would have ruled out anything
quiet and simple. But **most of the module doesn't need a negative rail at all.**

Positive CV attenuates, so the CV chain is unipolar. Envelope detector outputs are
unipolar. Both can run single-supply.

| Domain | Contents | Current |
|---|---|---|
| **Bipolar** (audio path only) | 6 front-end buffers, 6 I–V converters, 6 DC servos, 2× SSI2164 | **~44 mA per rail** [D] |
| **Single +5 V** | 6 CV filter MFB stages, 12 rectifier op-amps | ~32 mA |
| **+3V3 / +5 V** | MCU, ADC, reference, 74AHC541 | ~60 mA |

*(op-amps at 1.8 mA/ch, OPA1644 class; SSI2164 at ±6 mA typ, class AB [S])*

**Sizing the negative rail for 44 mA rather than 100 mA is what makes a quiet
solution easy.** At 100 mA a charge pump would have been out; at 44 mA it is
comfortable — a 10 Ω-class part droops 0.44 V, against 2.44 V for the 55 Ω pump
the mixer already uses [D].

Design consequence: **draw the domain boundary explicitly on the schematic.** The
temptation will be to run everything bipolar because it's simpler to think about.
Resist it — the split is what keeps the negative rail small.

---

## 2. There is already a 45 kHz charge pump in the box, and it sets a hard rule

The parent doc gives V−'s source impedance as *"55 Ω pump + 10 Ω filter"* and warns
that 20–25 kHz motor PWM *"beats with the 45 kHz pump"*. So the mixer generates its
negative rail with a switched-capacitor inverter running at ~45 kHz.

This matters more than a purist "no switchers" rule, because **a VCA is a
multiplier.** Two ripple components reaching the control port do not merely add —
they intermodulate, and the difference frequency lands in the audio band:

| Module supply frequency | Beat with 45 kHz | |
|---|---|---|
| 45 kHz | 0 Hz | **fatal** |
| 50 kHz | 5 kHz | **fatal — worst possible** |
| 65 kHz | 20 kHz | marginal |
| ≥300 kHz | ≥255 kHz | fine, and easy to filter |

**Rule: |f_module − 45 kHz| > 20 kHz, so f_module > 65 kHz; target ≥300 kHz.**

> **Specific trap:** the obvious cheap inverters — ICL7660S, TC1044S, MAX1044 — have
> a "boost" pin that sets the frequency to **45 kHz**. Choosing the obvious part and
> the obvious option lands you exactly on the mixer's pump frequency. If a charge
> pump is used at all, clock it externally from the MCU at a chosen frequency, or
> pick a part running ≥300 kHz.

---

## 3. Sharing a DC inlet creates a second ground bond — this decides it

The parent doc's rule is absolute: *"Exactly one bond between module audio ground
and board AGND. Six separate returns to six pin-3s, not commoned in the module."*

Six audio returns via the pin-3s is **one** bond. If the module also shares a DC
inlet non-isolated, the power ground is a **second** bond — and the two together
enclose a loop whose area is set by how the looms happen to run.

The parent doc takes this seriously with its own arithmetic: a 200 × 20 mm loop
(40 cm²) 50 mm from 1 A of switched current picks up **~160 mV** against a
35 nV/√Hz node. That figure is why the whole one-enclosure argument exists.

**An isolated DC-DC keeps the module's ground referenced only through the audio
connection, so the one-bond rule survives intact.**

The cost is honest: an isolated converter's barrier capacitance (typically
10–50 pF) passes common-mode switching current. But that is a small, bounded,
locatable problem you can attack with a Y-capacitor and placement — as opposed to
a ground loop, whose area depends on how the wiring was dressed on the day.

---

## The decision

```
   DC inlet (one, shared)
        │
        ├──────────────► mixer, unchanged (its own regulator, its own 45 kHz pump)
        │
        └──► isolated DC-DC (≥300 kHz) ──┬──► ±12 V   audio domain, ~44 mA/rail
                                          ├──► +5 V    CV + sensing
                                          └──► +3V3    MCU, ADC, reference
                     ▲
              isolation barrier: the module's ground touches the mixer
              ONLY through the six pin-3 audio returns
```

- **One inlet.** It stays a one-cable product; no mains transformer inside a box
  with a 35 nV/√Hz node (a 50 Hz magnetic field is a far worse neighbour than a
  300 kHz switcher).
- **Isolated**, so the one-bond rule holds by construction rather than by
  discipline.
- **≥300 kHz**, so it cannot beat with the mixer's pump.
- **LDOs after the DC-DC** on the ±12 V rails — an LT3042-class part on the
  positive rail feeding the reference and the CV chain is cheap insurance, since
  supply noise there becomes gain modulation.
- **Domain split enforced on the schematic**, so the negative rail stays at ~44 mA.

### Rejected

| | Why |
|---|---|
| Separate mains inlet, linear ±15 | A mains transformer's 50 Hz magnetic field is a worse aggressor in a small enclosure than any switcher, and two inlets is poor product design |
| Non-isolated shared rail | Second ground bond. Defensible if the loop is deliberately controlled, but it trades a structural guarantee for a discipline you have to maintain |
| Charge pump from the shared rail | Would work at 44 mA, but doesn't solve the ground bond, and the obvious parts land on 45 kHz |
| Drawing from `VREG` / `V+` / `V−` | Forbidden. Every mA on V− costs 65 mV through the 55 Ω pump and moves `NEGATIVE_RAIL_DROP`, `output_swing()`, `clipping_peak()` |

---

## Look this up before finalising

**The mixer's actual rail voltages and DC input specification.** I have inferred a
charge-pump-derived V− from *"55 Ω pump"*, and inferred a single-DC-inlet product
from that — but the actual input voltage range, the rail voltages, and the headroom
the summing stage assumes all come from the mixer repo, and they set the DC-DC's
output voltage and the audio-path headroom.

It is in `design.py` alongside `NEGATIVE_RAIL_DROP`, `output_swing()` and
`clipping_peak()`. First thing to check when the session mounts that repo.

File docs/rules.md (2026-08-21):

# Design rules, and the fabrication class behind them

Generated by `rules.py`. Every number is read from PCBWay's published capabilities page or derived from the two that are fitted; the quotations and the date read are in that file's docstring.

**This sentence said JLCPCB for four passes after the board moved to PCBWay** — in a generated document whose own body quotes PCBWay's figures three lines below it. A header is prose and the table is data, and only the data was ever regenerated against the constant that changed. It reads `FABRICATOR` now.

## The stackup

PCBWay's own 4-layer 1.61 mm construction at 1 oz outer copper, which is this board's class. It had never been chosen: the board carried no `(stackup ...)` block at all, so KiCad's defaults were in force and the dielectric height — the number every impedance and coupling figure depends on — was whatever KiCad assumed. `verify.check_stackup()` is what holds it now.

| layer | kind | thickness mm | Dk |
|---|---|---|---|
| F.Cu | copper | 0.035 | — |
| PP1 | prepreg | 0.1855 | 4.74 |
| In1.Cu | copper | 0.035 | — |
| Core | core | 1.03 | 4.6 |
| In2.Cu | copper | 0.035 | — |
| PP2 | prepreg | 0.1855 | 4.74 |
| B.Cu | copper | 0.035 | — |

The layers sum to 1.541 mm against a published finished 1.61 mm; the difference is solder mask. Quoted as published rather than reconciled, because a number adjusted to make an arithmetic check pass is no longer the fabricator's number. An outer layer references 0.1855 mm of prepreg at Dk 4.74.

```
rules: 0.2 mm track, 0.2 mm clearance, 0.7/0.3 mm via, 1 oz outer
  routing pitch 0.45 mm = track + clearance + 0.05 mm margin; adjacent tracks 0.25 mm apart against 0.2 mm
  holes: 0.406 mm hole to hole and 0.250 mm hole to copper, each the stricter of PCBWay's published figure and KiCad's default
      PCBWay publishes 0.406 / 0.279 / 0.178 mm (component hole, via, hole to copper) against KiCad's 0.25 / 0.25 -- so the fabricator is stricter on one and looser on the other, and the open question that asked which of two numbers to take had the wrong page's number in it
      and neither binds: a via needs 0.650 / 0.900 / 0.550 mm to a track, a via and a pad, and copper sets all three at this class
  a via clears a track by 0.000 mm orthogonally (blocks) and 0.186 mm diagonally (blocks)
  a TSSOP leaves 0.25 mm and its window is -0.35 mm -- -0.02 at the finest class -- so no track centre exists between two of its pins and every pin escapes outward
  and no cell inside one either: a pad holds a cell at every phase only above 0.65 mm of pitch, and a TSSOP is 0 um under it -- see rules.pad_reach(); route.Grid.escape() was what did something about it
  what closes it is the fan-out, and it is a ladder with three rungs rather than a threshold:
      SOIC    1.27 mm pitch on 0.60 mm pads, 0.970 mm to the next edge, offset limit +0.670 against a 0.225 mm worst phase -- a track starts inside the pad at every phase
      TSSOP   0.65 mm pitch on 0.40 mm pads, 0.450 mm to the next edge, offset limit +0.150 against a 0.225 mm worst phase -- an escape reaches it
      QFN-56  0.40 mm pitch on 0.20 mm pads, 0.300 mm to the next edge, offset limit +0.000 against a 0.225 mm worst phase -- unreachable -- two pins per grid line; the jog comes 0.175 mm to a neighbour against 0.40
  and the coil nets are not the objection to a finer class -- A/mm2 was the wrong instrument:
      0.20 mm at 1 oz    13.2 A/mm2, and 0.088 C of rise at 92.7 mA (745 mA would be 10 C; 1.1 C if the borrowed constant is 3x out)
      0.15 mm at 2 oz     8.8 A/mm2, and 0.045 C of rise at 92.7 mA (999 mA would be 10 C; 0.5 C if the borrowed constant is 3x out)
      0.09 mm at 1 oz    29.4 A/mm2, and 0.327 C of rise at 92.7 mA (417 mA would be 10 C; 4.0 C if the borrowed constant is 3x out)
  a 0.40 mm pitch needs 0.12/0.12 mm or finer -- a 0.30 mm grid, 2.2x the cells -- which is below the 2 oz floor of 0.15, so the copper weight is the price and no listed class avoids it
  a SOIC leaves 0.67 mm between pads:
      fitted        0.20/0.20 mm, either weight    window +0.070 mm against a 0.40 mm floor -- no cell fits, at any pitch
      2 oz minimum  0.15/0.15 mm, 2 oz outer       window +0.220 mm against a 0.30 mm floor -- no cell fits, at any pitch
      1 oz minimum  0.09/0.09 mm, 1 oz outer only  window +0.400 mm against a 0.18 mm floor -- a cell fits
```

## Does a routing cell fit between two SOIC pins?

The question the routing pass was left with, and the reason the answer turned out not to be a finer grid. A SOIC pad is 0.6 mm across on a 1.27 mm pitch, so there is 0.67 mm of copper-free space between two pins. A cell reliably falls in it only when the legal window is at least one grid pitch wide, and the finest legal pitch is `track + clearance` — so the test reduces to `gap >= 3 x clearance + 2 x track`, which does not mention the pitch at all.

| class | track / clearance | copper | window | pitch floor | a cell fits |
|---|---|---|---|---|---|
| fitted | 0.20 / 0.20 | either weight | +0.070 mm | 0.40 mm | **no**, at any pitch |
| 2 oz minimum | 0.15 / 0.15 | 2 oz outer | +0.220 mm | 0.30 mm | **no**, at any pitch |
| 1 oz minimum | 0.09 / 0.09 | 1 oz outer only | +0.400 mm | 0.18 mm | yes |

**So the corridor opens only at JLCPCB's finest multilayer class, which is available at 1 oz outer copper and not at 2 oz.** That is not a routing decision, it is a decision to give up 2 oz as an option -- and both are history. route.py is deleted; KiCadRoutingTools closed this board at the fitted class without a finer grid, by ripping up and re-routing the nets in the way, so it is ordered at that class.

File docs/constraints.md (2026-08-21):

# The five constraints, tested for a mechanism

Generated by `constraints.py`. The question is not whether each constraint is satisfied — `verify.py` answers that — but whether it has a mechanism, what the arithmetic says its threshold should be, and how much margin the design has.

```
Testing the five constraints for a mechanism
requirement for isolation: -54 dB per pair (docs/00-current-state.md)
numbered as hardware-spec-v0.md section 5 numbers them, which is also
what verify.py prints and what every 'constraint N' in design.py means

1. the module draws nothing from VREG, V+ or V-
   mechanism   65 mV of negative rail per mA (55 ohm pump + 10 ohm filter)
   headroom    7.84 dB now, against the 6 dB check_headroom() demands
   threshold   21.8 mA could be drawn before that check fails
   but         212 uA IS drawn indirectly -- the mixer's summer sources our
               signal current from its own rails, so 'nothing' is unachievable (13.8 uV of sag)
   verdict     KEEP, reword

2. exactly one AGND bond, and six separate returns
   2a is binary and has no margin to compute: verify.py holds it
   2b is struck for having no mechanism -- see design.FRONT_R and the table

3. SIN{n} carries zero DC by construction
   mechanism   DC through the master pot wiper, via C703 and R706's 1M
   ours        0.50 mV residual -> 3.0 nA at the wiper
   worst case  18.0 nA at the top of servo_vos's declared range
   theirs      0.2 to 1.0 nA from U1B's own offset
   so          3x the mixer's own worst case, and the absolute threshold is unsourced
   verdict     KEEP, restate as a current

4. PIN{n} sees ~5-10 kohm, or the 31.8 Hz DC-block corner moves
   load      corner     at 5 Hz    at 55 Hz
     5000   31.83 Hz   -16.18 dB    -1.25 dB
    10000   15.92 Hz   -10.47 dB    -0.35 dB
   the sentence names 31.8 Hz, which is the 5k end; we are at 15.9 Hz
   so it is unsatisfiable anywhere in 5-10k except at exactly 5k
   choosing the top gives back +5.72 dB of subsonic rejection
   and recovers +0.91 dB at 55 Hz
   verdict     KEEP, fix the number

5. individually-shielded twisted triads, shields at one end
   PIN(n) impedance at 20 kHz  8 ohm  -- NOT 10k: see pin_impedance()
   channel-to-channel           -112.9 dB   (59 dB inside the requirement)
   the same, computed at 10k     -51.0 dB   <- the near miss: this FAILS -54 dB
   input-to-output in one pair  -102.5 dB   positive feedback, and nothing mentions it
   mixer charge pump             -94.3 dB   at 45 kHz
   module DC-DC                  -91.8 dB   at 300 kHz
   verdict     KEEP as practice, demote from the list

5b. the same coupling, between two traces on the board
    constraint 5 asks this of the loom; nothing asked it of the copper
   IVOUT3/PIN5       226.0 mm at 0.40 mm pitch, into 8 ohm
   BUF5/CVX1          20.6 mm at 0.93 mm pitch, into 142 ohm
   capacitive, at h = 0.1855 mm  -112.5 dB   (58 dB inside the requirement)
   the same across the sweep    -109.0 dB   the height is worth 3.5 dB, and rules.FAB_STACKUP is what settled it

5c. audio copper that is not over its own ground plane
    CROSSING_RULE says nothing audio-carrying crosses; check_crossings() reads the netlist and cannot see a track's path
   PIN6               32.2 mm past y = 156.44
   IVOUT4             22.2 mm past y = 156.44
   SIN4               20.3 mm past y = 156.44
   PIN2               11.6 mm past y = 156.44
   SIN2                7.6 mm past y = 156.44
   PIN4                7.1 mm past y = 156.44
   IVOUT2              6.3 mm past y = 156.44
   SIN6                6.1 mm past y = 156.44
   IVOUT6              5.0 mm past y = 156.44
   total  118.1 mm against 118.1 declared -- a ratchet, and every millimetre of it reaches a relay contact at y = 161.4
   was   211.9 mm before the copper review and 144.1 after it: PIN5 and SIN3 had every pad in the analogue half and were routed through the digital one anyway
   then SIN2 came back as a detour rather than a necessity -- 33.5 mm to reach a relay pad 5 mm past the pour edge, re-laid by krt.py --nets at 7.6

5d. where an audio signal changes reference plane
    In1 and In2 carry the same nets in the same places, so every via changes plane as well as layer and the return current has to transfer
   audio vias         222   against 294 ground vias
   worst gap         4.90 mm  median 1.50, 194 of 222 within 2 mm
   loop area        370.7 mm2 against 370.7 declared -- a ratchet, at 1.03 mm of plane separation
   was            1990.6 mm2 before returns.py, at a median of 7.39 mm and a worst of 22.76
   not an impedance: 4.90 mm of In1/In2 pair is tens of nH, and tens of nV at 20 kHz
   as a pickup loop it reaches the mixer's 144 uV floor at 106.6 nT of 580 kHz field
   the field is the term nothing here derives -- board_coupling() solves trace against trace, and an aggressor inside a potted brick has no drawing

5e. the domain crossings, as aggressors and as return paths
    every measurement above this line filters to the audio nets; check_crossings() reads the netlist and knows which signals cross and nothing about where
   MCLK/SIN6          30.2 mm at 0.428 mm pitch on F.Cu
   SCLK/SIN6          24.4 mm at 0.850 mm pitch on F.Cu
   IRQ/IVOUT6         22.3 mm at 0.800 mm pitch on F.Cu
   MISO/SIN5          16.2 mm at 1.018 mm pitch on F.Cu
   total  244.2 mm against 244.2 declared -- a ratchet, and MCLK/SIN6 is the one aggressor that runs continuously
   priced as board_coupling() prices the others it is ~50 dB inside the requirement; what that model does not carry is the return path below
   bridges between the planes: R902 at x=6.0
   CS               crosses at x =   81.6,  75.6 mm from R902
   SCLK             crosses at x =   81.0,  75.0 mm from R902
   MCLK             crosses at x =   80.4,  74.4 mm from R902
   IRQ              crosses at x =   80.2,  74.2 mm from R902
   worst   75.6 mm against 75.6 declared -- so the return loop is about twice it, and PWM1-6 are absent because U11 straddles the split by design

   inductive, the same         -125.7 dB   computed, not dismissed: a stiff node still takes a series emf
   would fail at                 6700 ohm  <- the impedance decides it; the loom node is 8
   verdict     good practice, not load-bearing
```

| # | constraint | mechanism | margin | verdict |
|---|---|---|---|---|
| 1 | draws nothing from VREG/V+/V- | real: 65 mV of rail per mA | ~100x | **keep, reword** -- "nothing" is unachievable, since the mixer's summer sources this module's signal current from its own rails. What is meant, and what is checked, is no *supply* current. |
| 2a | exactly one AGND bond | real: a loop enclosing the mixer's pour and the loom | n/a, binary | **keep** -- the mixer's own `_GROUND_RULE` across the connector. |
| 2b | six separate returns, not commoned | **none** | 49 dB | **struck.** See `design.FRONT_R`. |
| 3 | SIN{n} zero DC by construction | real: DC through the master wiper | ~3x the mixer's own | **keep, restate as a current.** "Zero" overstates by three orders of magnitude and "by construction" is unachievable -- a servo is feedback, and the capacitor that would be construction puts a second pole beside the mixer's own. |
| 4 | PIN{n} sees 5-10 kohm | real, and computed by `coupling_burden()` upstream | n/a | **keep, fix the number.** 31.8 Hz is the corner at 5 kohm, so the sentence is unsatisfiable anywhere else in its own window. |
| 5 | individually-shielded triads, one end | real in kind | 59 dB | **keep as practice, demote from the list.** Both loom nodes are low impedance, so the coupling the shields prevent is 59 dB inside the requirement. |

**One of five had no mechanism. Two more have the mechanism and the wrong
number. One is unsatisfiable as written. One is sound.**

That is not an argument against having the list. It is an argument for the list
being derived rather than drafted -- and for the distinction the exercise turns
on: a constraint with thin margin is load-bearing, a constraint with 59 dB of
margin is good practice, and the two do not want the same treatment. Both were
in the same list, checked with the same rigour, and only one of them was worth
it.

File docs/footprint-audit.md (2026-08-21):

# The footprint audit — a land pattern against the part's own drawing

**Not generated.** A decision-and-measurement record, in the shape
`fabrication-class.md` and `routing-tool.md` have: what was checked, against
which document, and what it found.

Started 2026-08-21, before ordering. **Three parts failed and one of them could
not be fitted at all. All three are fixed in `design.py`; the board needs one
sync in KiCad before a package can be written again.**

| | was | is | costs |
|---|---|---|---|
| `BYPASS_RELAY` | `G6S-2 DC5` | **`G6S-2F DC5`** | nothing — same land, same pin map, same ratings |
| `ENV_DIODE`'s MPN | `1N4148WS-7-F` | **`1N4148W-7-F`** | nothing — the value string already said `1N4148W` |
| the five BAT54s | `Diode_SMD:D_SOD-123` | **`Package_TO_SOT_SMD:SOT-23`** | a symbol, a pin map, and a re-route of five nets |

**The board is synced and the loop is closed.** KiCad's Update PCB from
Schematic put the new lands on it; `krt.py` re-routed the affected scope;
`verify.py` passes and `gen_fab.py` has written the package again. What that
took, in order, is worth keeping because none of it was on the list:

| | |
|---|---|
| **the scope was wider than the five diodes** | the moved pads landed under other nets' copper. `MISO`, `IRQ`, `MOSI` and `PWM5` were shorting to them, so the scope was **derived from the DRC report** rather than guessed: `FSAC FSG FSD VMOD MISO IRQ MOSI PWM5` |
| **`--nets` takes patterns, not a comma list** | `--nets "A,B,C"` is one pattern that matches nothing, and `route.py` says so and exits 2 rather than routing nothing quietly |
| **`MDGND` was excluded and had to be, so one pad stayed open** | `D801`'s anode is the only ground pad among the five. Its old stitch went east from a pad that has moved, and KiCad re-netted that via to `FSAC` when the new cathode pad landed on it — so it read 0.00 mm against the `MDGND` pour. One via and one stub, placed at (42.35, 168.0775), 0.76 mm from the pad and clear of the body |
| **the router's gate refused the first run and was right** | `disconnected_pads_before: 10, after: 1` — and the 1 was that stitch. It committed on the second run |

Nothing else in the design moved: no value, no net, no other footprint. The
board is **5116 segments and 992 vias**, one width, one via size, no signal
copper on either plane, 0 DRC and 0 unconnected.

**And the last twelve violations were silkscreen, from a rule reading a proxy.**
`gen_pcb.py` puts a designator on `F.Fab` rather than on silk when the part has
two pads, because 128 of this board's parts are smaller than their own
reference text. A SOT-23 has **three** pads — the middle one is not connected —
so the rule stopped applying, five designators were promoted onto silk, and DRC
found them colliding with neighbours that had not moved a micron. The test
counts the terminals the *design connects* now, which is what "two-terminal
part" means; `Q801`'s SOT-523 has three and keeps its designator on silk, which
is right, because a transistor is oriented by hand.

---

## Why nothing in this repository could have caught these

Every instrument here reads an artefact this project wrote. `verify.py`
compares KiCad's own netlist to `design.py` by name *and pin*, which catches a
wire that missed its endpoint and a polarised part drawn backwards.
`Design.check_order_codes()` decodes a ceramic's part number and compares its
case, dielectric, voltage and capacitance against the value string and the
land. `gen_pcb.check_courtyards()` holds `placement.SIZE` to KiCad's own
courtyard.

**None of them opens a datasheet.** The question "is this KiCad land pattern
the pattern this manufacturer draws for this part number" is answered by a
document outside the repository, and until now nobody had asked it. The
netlist comparison is specifically unable to help: it compares pad number to
pin number, and a pad numbered 1 on the wrong package is still pad 1.

That is this project's oldest shape once more — **a claim about a part,
checked against a model of the part** — and here the model is KiCad's library
and the part is what arrives in a bag.

---

## The method, three questions per part

1. **Does the part number name the package the land pattern is for?** Read off
   the manufacturer's own datasheet or part page, not a distributor's summary.
2. **Does the pin *numbering* the netlist uses match the datasheet's terminal
   arrangement** — and for a part with more than one variant, the *right
   column* of it?
3. **For the one hand-drawn footprint, do the coordinates match the drawing?**
   Computed from the generated `.kicad_mod`, not read off a screen.

---

## Results

| part | fitted land | verdict |
|---|---|---|
| **TMR 6-2422WI** | `cv:TRACO_TMR-6-xxxxWI_Dual_THT` (ours) | ✅ **passes on every measurement** — see below |
| **G6S-2 DC5** | `Relay_SMD:Relay_DPDT_Omron_G6S-2F` | ❌ **the part number is the through-hole model** |
| **BAT54-7-F** ×5 | `Diode_SMD:D_SOD-123` | ❌ **SOT-23 part on a two-pad land** |
| **1N4148WS-7-F** ×13 | `Diode_SMD:D_SOD-123` | ❌ **SOD-323 part on a SOD-123 land** |
| **TLP2761(TP,E)** | `Package_SO:SO-6L_10x3.84mm_P1.27mm` | ✅ package designation is SO6L |
| **PMEG2010AEH,115** | `Diode_SMD:D_SOD-123F` | ✅ SOD-123F, and `SOD123F_FP`'s comment already reasons about the difference |
| **3403.0168.11** | `Fuse:Fuse_Schurter_UMT250` | ✅ name and series match; dimensions not yet checked |
| **SRN6045TA-150M**, **744222**, **SC0915** | vendor-named KiCad footprints | ✅ series matches; dimensions not yet checked |

---
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

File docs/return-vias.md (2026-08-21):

# The return-via stitching — where a signal changes reference plane

**Not generated.** A decision-and-measurement record, in the shape
`fabrication-class.md`, `routing-tool.md` and `footprint-audit.md` have: what
was measured, against which mechanism, and what was decided.

Done 2026-08-21, after the copper review and before ordering.

| | before | after |
|---|---|---|
| audio vias | 217 | 219 — SIN2 was re-routed in between |
| ground vias | 151 | **290** |
| worst separation to a ground via | 22.76 mm | **4.90 mm** |
| median separation | 7.39 mm | **1.50 mm** |
| within 2 mm | 6 of 217 | **190 of 219** |
| total plane-transfer loop area | 1990.6 mm² | **367.8 mm²** |

`constraints.return_loops()` is the measurement, `returns.py` is what moved it,
and `constraints.AUDIO_RETURN_AREA_MM2` is the ratchet — down as copper is
laid, up only with the vias named in the failure message, which is
`AUDIO_OFF_MAGND_MM`'s rule one artefact along.

---

## What the question is

`In1.Cu` and `In2.Cu` carry the same two nets in the same places: MAGND north
of y = 156.44, MDGND south of y = 158.44. So **every via on this board changes
reference plane as well as signal layer**, and the return current has to
transfer from one plane to the other. The only conductor that does that is a
ground via, and the loop the current makes on the way is
`rules.plane_separation()` — 1.03 mm of core — times the distance to the
nearest one.

`gen_pcb.stitch_grounds()` is why the number was what it was, and it is not a
fault in that function. It places a via **beside every ground pad**, because
what a ground pad needs is a hole to the plane underneath it. Nothing in this
repository had ever tried to put a stitch near a *signal* via, so nothing ever
measured how far the nearest one was.
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

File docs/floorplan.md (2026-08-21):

# Floorplan

Zones, ground domains and boundary crossings for the per-string CV module, against summing-mixer @ `4bc7ddb`.

Generated by `floorplan.py`. 290 parts, 185 nets.

## Ground strategy
Three stars, and only the first is a rule this module inherits.

**R901: MAGND to the mixer's AGND. Exactly one, and it is constraint 2.**
A dedicated conductor from the module's audio ground to the mixer's own
designated AGND pad, TP6 -- whose comment upstream calls it "the *only* correct
one, given the ground rule". The six shields land at the same node and at no
other, which is the whole of what makes the bond count one: a shield is
terminated at the main-board end and cut back here, so nothing in the loom
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

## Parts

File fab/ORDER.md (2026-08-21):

# Ordering this board

**Generated by `gen_fab.py`. Every number here is owned by the file named
beside it** — edit that file, not this one.

Upload `cv-module-pcbway.zip`. It is **not** tracked — the loose files beside it are, and
the archive is built from exactly them, so `python3 gen_fab.py` is what puts it
back in a fresh checkout. Uploading the loose files instead is the same set.

## The board

| | |
|---|---|
| fabricator this is dimensioned for | **PCBWay** — `rules.FABRICATOR` |
| size | **106.9 × 233.1 mm** |
| layers | **4 copper** |
| outer copper | **1 oz** — `rules.COPPER_OZ` |
| track / clearance | **0.20 / 0.20 mm** — `rules.TRACK_MM`, `rules.CLEARANCE_MM` |
| smallest via | **0.7 / 0.3 mm** — `rules.VIA_DIAMETER_MM` |
| hole to hole / hole to copper | **0.406 / 0.250 mm** — `rules.hole_rules()` |
| finished thickness | **1.61 mm** — `rules.FAB_FINISHED_MM` |

**The thickness is settled and the package agrees with it.** `cv-module-job.gbrjob` carries `BoardThickness: 1.61`, which is KiCad's `(general (thickness ...))` field and is now `rules.FAB_FINISHED_MM` -- what PCBWay publishes for this construction. It sat at KiCad's own default of 1.6 for the life of the design, because the stackup pass made the layer table real and left the summary field behind; `rules.apply_thickness()` writes it and `verify.check_stackup()` holds it, which matters because Board Setup recomputes that field from the stackup and would put 1.541 mm there -- the same construction without solder mask.
**Order to 1.61 mm.**

## The stackup

`rules.FAB_STACKUP`, and `verify.check_stackup()` holds the board to it.

| layer | kind | thickness mm | Dk |
|---|---|---|---|
| F.Cu | copper | 0.0350 | — |
| PP1 | prepreg | 0.1855 | 4.74 |
| In1.Cu | copper | 0.0350 | — |
| Core | core | 1.0300 | 4.60 |
| In2.Cu | copper | 0.0350 | — |
| PP2 | prepreg | 0.1855 | 4.74 |
| B.Cu | copper | 0.0350 | — |

## What is in the package

| file | what it is |
|---|---|
| `cv-module-F_Cu.gtl` | top copper |
| `cv-module-In1_Cu.g1` | inner layer 1 — MAGND/MDGND plane |
| `cv-module-In2_Cu.g2` | inner layer 2 — MAGND/MDGND plane |
| `cv-module-B_Cu.gbl` | bottom copper |
| `cv-module-F_Mask.gts` | top solder mask |
| `cv-module-B_Mask.gbs` | bottom solder mask |
| `cv-module-F_Paste.gtp` | top stencil |
| `cv-module-F_Silkscreen.gto` | top legend |
| `cv-module-Edge_Cuts.gm1` | board outline — **the only outline in the package** |
| `cv-module.drl` | drill, plated and unplated combined |
| `cv-module-job.gbrjob` | job file — KiCad's own summary of the set |

### Left out because the board draws nothing on them

* **B.Paste** — the board draws nothing on it, and an empty layer in a package is a question for a CAM operator
* **B.SilkS** — the board draws nothing on it, and an empty layer in a package is a question for a CAM operator

### Left out on principle

* **B.CrtYd** — as F.CrtYd
* **B.Fab** — as F.Fab
* **F.CrtYd** — courtyards are a placement check, not a manufacturing layer
* **F.Fab** — carries a second closed board outline -- CAM picking it up instead of Edge.Cuts returns the wrong board shape
* **User.2** — krt.py's keep-out geometry lives here between runs
* **User.Comments** — notes to ourselves
* **User.Drawings** — gen_pcb.py draws reserved courtyards here; there are none left, and it is not a manufacturing layer either

## The drilling

One combined file, plated and unplated together, each tool carrying its own
`TA.AperFunction` attribute. `gen_fab.check_holes()` counts these against the
board: 1186 hits against 1142 vias, 34 plated and 10 unplated through-hole pads.

| tool | diameter mm | plating | hits |
|---|---|---|---|
| T1 | 0.300 | plated | 1142 |
| T2 | 1.000 | plated | 34 |
| T3 | 1.850 | **unplated** | 2 |
| T4 | 2.200 | **unplated** | 2 |
| T5 | 3.200 | **unplated** | 6 |

## Assembly, if it is ordered

**296 of 296 parts on the top**, and 34 plated through-hole pads are hand work whoever does
them.

* bill of materials: `out/cv-module-bom.csv` — `gen_bom.py`, with MPNs
* placements: `fab/cv-module-pos.csv` — `kicad-cli pcb export pos`, `--exclude-dnp`,
  which excludes **0** parts on this board: counted, not assumed, so the
  CPL and the BOM agree for a reason
* what to buy and from where: `docs/SHOPPING.md`

## What this repository has **not** decided

None of these is derivable from anything in this project, so none of them is
filled in. They are order-form fields and they are a person's to choose:

* **surface finish** — the job file says `Finish: None`, which is KiCad
  reporting that nobody set one, not a specification of bare copper;
* **solder mask colour** and **silkscreen colour**;
* **electrical test** — worth pricing at 1186 holes
  and 185 nets;
* **panelisation or single boards**, and whether the fabricator may add rails;
* **IPC class**, and any impedance control — there is none on this board:
  `constraints.board_coupling()` is the only figure that reads the stackup and
  it has 60 dB of margin;
* **quantity, lead time and shipping**.

## Before ordering

`verify.py` must pass on the board this package was made from. It is the only
thing that says the copper is legal, the netlist is the design's, the ground
split is intact and both isolation barriers hold. `gen_fab.py --verify` says
the package is a package of *that* board and not of an older one.

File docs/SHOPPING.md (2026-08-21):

# cv-module: what to buy, and from where

Generated by `gen_bom.py`. Quantities are for **one board**.

The convention is the mixer's, inherited rather than invented: **Mouser UK catalogue searches keyed on the manufacturer's part number**, not product-page deep links, because "a search survives a part being re-listed, which a deep link does not". **These links have not been opened.** A guessed Digi-Key product URL tried while writing this file resolved to a HIWIN linear rail, which is the failure that warning describes.

The `order` column carries spares on the mixer's rule: 4 spare of each chip passive, 1 of everything else, and none of the parts in `gen_bom.NO_SPARE`.

**Which parts are "chip passives" is decided by the land, and it used to be decided by a substring.** The test was `"SO" in footprint` -- meaning to catch SOIC, SOT and SOD -- so every part whose land pattern does not contain those two letters was bought four spares: the Traco converter at GBP 18.16 each, ordered five for a board that fits one, which is GBP 72.64 of spare converter against a GBP 60.67 board. The Pico, three relays, both inductors, the inlet fuse, an SMA diode and every pin header were in the same class. It reads `design.R_FP`, `design.C_FP` and `design.C_FILM_FP` now.

## The basis column, and why the totals are a range

| basis | meaning |
|---|---|
| `read` | a page was fetched in this session and states this figure |
| `snippet` | a search result quoted a distributor's figure; the page itself was not opened |
| `band` | a typical band for the class at the stated quantity. **Not read from anything.** |
| `none` | the part is not chosen, so it has no price by construction |

Only one line on this board is `read`. That is worth stating plainly rather than letting a tidy table imply otherwise.

## Lines

| Ref | Value | MPN | Fitted | Order | Unit | Basis | Mouser UK |
|---|---|---|---|---|---|---|---|
| C101–C814 | 10u/16V X7R | `CGA6M3X7R1C106K200AB` | 8 | 12 | GBP 0.08–0.25 | band | [search](https://www.mouser.co.uk/c/?q=CGA6M3X7R1C106K200AB) |
| C102–C652 | 1200p/50V C0G | `GRM2165C1H122JA01D` | 12 | 16 | GBP 0.02–0.08 | band | [search](https://www.mouser.co.uk/c/?q=GRM2165C1H122JA01D) |
| C121–C621 | 100p/50V C0G | `GRM2165C1H101JA01D` | 6 | 10 | GBP 0.02–0.08 | band | [search](https://www.mouser.co.uk/c/?q=GRM2165C1H101JA01D) |
| C131–C631 | 150n/50V X7R | `CGA4J2X7R1H154K125AA` | 6 | 10 | GBP 0.02–0.08 | band | [search](https://www.mouser.co.uk/c/?q=CGA4J2X7R1H154K125AA) |
| C141–C641 | 56n/50V X7R | `CC0805KRX7R9BB563` | 6 | 10 | GBP 0.02–0.08 | band | [search](https://www.mouser.co.uk/c/?q=CC0805KRX7R9BB563) |
| C142–C642 | 22n/50V X7R | `CEU4J2X7R1H223K125AE` | 6 | 10 | GBP 0.02–0.08 | band | [search](https://www.mouser.co.uk/c/?q=CEU4J2X7R1H223K125AE) |
| C151–C810 | 470n/50V X7R | `GRM21BR71H474KA88L` | 7 | 11 | GBP 0.02–0.08 | band | [search](https://www.mouser.co.uk/c/?q=GRM21BR71H474KA88L) |
| C701–C842 | 100n/50V X7R | `CGA4J2X7R1H104K125AE` | 36 | 40 | GBP 0.01–0.05 | band | [search](https://www.mouser.co.uk/c/?q=CGA4J2X7R1H104K125AE) |
| C805 | 2n2/50V C0G | `GRM2165C1H222JA01D` | 1 | 5 | GBP 0.02–0.08 | band | [search](https://www.mouser.co.uk/c/?q=GRM2165C1H222JA01D) |
| C806–C816 | 1u/16V X7R | `GRM21BR71C105KA01L` | 3 | 7 | GBP 0.02–0.08 | band | [search](https://www.mouser.co.uk/c/?q=GRM21BR71C105KA01L) |
| C807–C813 | 10u/50V X7R | `CNA6P1X7R1H106K250AE` | 5 | 9 | GBP 0.30–0.80 | band | [search](https://www.mouser.co.uk/c/?q=CNA6P1X7R1H106K250AE) |
| C840 | 4u7/50V X7R | `CGA6P3X7R1H475K250AB` | 1 | 5 | GBP 0.08–0.30 | band | [search](https://www.mouser.co.uk/c/?q=CGA6P3X7R1H475K250AB) |
| C843 | 22u/16V X5R | `C3225X5R1C226M250AA` | 1 | 5 | GBP 0.08–0.30 | band | [search](https://www.mouser.co.uk/c/?q=C3225X5R1C226M250AA) |
| D151–D805 | 1N4148W | `1N4148W-7-F` | 13 | 14 | GBP 0.02–0.08 | band | [search](https://www.mouser.co.uk/c/?q=1N4148W-7-F) |
| D801–D833 | BAT54 | `BAT54-7-F` | 5 | 6 | GBP 0.05–0.15 | band | [search](https://www.mouser.co.uk/c/?q=BAT54-7-F) |
| D803, D806 | PMEG2010AEH | `PMEG2010AEH,115` | 2 | 3 | GBP 0.10–0.30 | band | [search](https://www.mouser.co.uk/c/?q=PMEG2010AEH,115) |
| D804 | B340A | `B340A-13-F` | 1 | 2 | GBP 0.20–0.60 | band | [search](https://www.mouser.co.uk/c/?q=B340A-13-F) |
| F801 | 1.6A T 250V | `3403.0168.11` | 1 | 2 | USD 1.80 | read | [search](https://www.mouser.co.uk/c/?q=3403.0168.11) |
| J1 | CH1 | `61300211121` | 1 | 2 | GBP 0.25–0.60 | band | [search](https://www.mouser.co.uk/c/?q=61300211121) |
| J2 | CH2 | `61300211121` | 1 | 2 | GBP 0.25–0.60 | band | [search](https://www.mouser.co.uk/c/?q=61300211121) |
| J3 | CH3 | `61300211121` | 1 | 2 | GBP 0.25–0.60 | band | [search](https://www.mouser.co.uk/c/?q=61300211121) |
| J4 | CH4 | `61300211121` | 1 | 2 | GBP 0.25–0.60 | band | [search](https://www.mouser.co.uk/c/?q=61300211121) |
| J5 | CH5 | `61300211121` | 1 | 2 | GBP 0.25–0.60 | band | [search](https://www.mouser.co.uk/c/?q=61300211121) |
| J6 | CH6 | `61300211121` | 1 | 2 | GBP 0.25–0.60 | band | [search](https://www.mouser.co.uk/c/?q=61300211121) |
| J8 | PWR | `61300211121` | 1 | 2 | GBP 0.25–0.60 | band | [search](https://www.mouser.co.uk/c/?q=61300211121) |
| J15 | MIDIIN | `61300311121` | 1 | 2 | GBP 0.30–0.75 | band | [search](https://www.mouser.co.uk/c/?q=61300311121) |
| J16 | MIDIOUT | `61300311121` | 1 | 2 | GBP 0.30–0.75 | band | [search](https://www.mouser.co.uk/c/?q=61300311121) |
| J17 | TAP | `61300211121` | 1 | 2 | GBP 0.25–0.60 | band | [search](https://www.mouser.co.uk/c/?q=61300211121) |
| J18 | EXPR | `61300311121` | 1 | 2 | GBP 0.30–0.75 | band | [search](https://www.mouser.co.uk/c/?q=61300311121) |
| J19 | RESET | `61300211121` | 1 | 2 | GBP 0.25–0.60 | band | [search](https://www.mouser.co.uk/c/?q=61300211121) |
| K801–K803 | G6S-2F DC5 | `G6S-2F DC5` | 3 | 4 | GBP 3.00–5.50 | band | [search](https://www.mouser.co.uk/c/?q=G6S-2F DC5) |
| L801 | 744222 | `744222` | 1 | 2 | GBP 1.97 | read | [search](https://www.mouser.co.uk/c/?q=744222) |
| L802 | 15u 20% | `SRN6045TA-150M` | 1 | 2 | GBP 0.30–0.90 | band | [search](https://www.mouser.co.uk/c/?q=SRN6045TA-150M) |
| Q801 | DMG1012T | `DMG1012T-7` | 1 | 2 | GBP 0.06–0.20 | band | [search](https://www.mouser.co.uk/c/?q=DMG1012T-7) |
| R101–R802 | 10k 0.1% | `ERA6AEB103V` | 14 | 18 | GBP 0.10–0.30 | band | [search](https://www.mouser.co.uk/c/?q=ERA6AEB103V) |
| R111–R621 | 12k1 0.1% | `ERA6AEB1212V` | 12 | 16 | GBP 0.10–0.30 | band | [search](https://www.mouser.co.uk/c/?q=ERA6AEB1212V) |
| R115–R615 | 220R 1% | `RC0805FR-07220RL` | 6 | 10 | GBP 0.01–0.03 | band | [search](https://www.mouser.co.uk/c/?q=RC0805FR-07220RL) |
| R131–R632 | 1M 1% | `RC0805FR-071ML` | 12 | 16 | GBP 0.01–0.03 | band | [search](https://www.mouser.co.uk/c/?q=RC0805FR-071ML) |
| R141–R656 | 22k 1% | `RC0805FR-0722KL` | 18 | 22 | GBP 0.01–0.03 | band | [search](https://www.mouser.co.uk/c/?q=RC0805FR-0722KL) |
| R142–R643 | 17k8 1% | `RC0805FR-0717K8L` | 12 | 16 | GBP 0.01–0.03 | band | [search](https://www.mouser.co.uk/c/?q=RC0805FR-0717K8L) |
| R151–R830 | 10k 1% | `RC0805FR-0710KL` | 25 | 29 | GBP 0.01–0.03 | band | [search](https://www.mouser.co.uk/c/?q=RC0805FR-0710KL) |
| R154–R657 | 4k99 1% | `RC0805FR-074K99L` | 12 | 16 | GBP 0.01–0.03 | band | [search](https://www.mouser.co.uk/c/?q=RC0805FR-074K99L) |
| R803–R816 | 100k 1% | `RC0805FR-07100KL` | 7 | 11 | GBP 0.01–0.03 | band | [search](https://www.mouser.co.uk/c/?q=RC0805FR-07100KL) |
| R804, R805 | 4R7 1% | `RC0805FR-074R7L` | 2 | 6 | GBP 0.01–0.03 | band | [search](https://www.mouser.co.uk/c/?q=RC0805FR-074R7L) |
| R827 | 390R 1% | `RC0805FR-07390RL` | 1 | 5 | GBP 0.01–0.05 | band | [search](https://www.mouser.co.uk/c/?q=RC0805FR-07390RL) |
| R828 | 33R 5% | `RC0805JR-0733RL` | 1 | 5 | GBP 0.01–0.05 | band | [search](https://www.mouser.co.uk/c/?q=RC0805JR-0733RL) |
| R829 | 10R 5% | `RC0805JR-0710RL` | 1 | 5 | GBP 0.01–0.05 | band | [search](https://www.mouser.co.uk/c/?q=RC0805JR-0710RL) |
| R831–R833 | 1k 1% | `RC0805FR-071KL` | 3 | 7 | GBP 0.01–0.05 | band | [search](https://www.mouser.co.uk/c/?q=RC0805FR-071KL) |
| R850 | 88k7 1% | `RC0805FR-0788K7L` | 1 | 5 | GBP 0.01–0.05 | band | [search](https://www.mouser.co.uk/c/?q=RC0805FR-0788K7L) |
| R851 | 22k1 1% | `RC0805FR-0722K1L` | 1 | 5 | GBP 0.01–0.05 | band | [search](https://www.mouser.co.uk/c/?q=RC0805FR-0722K1L) |
| R901, R902 | 0R | `RC0805JR-070RL` | 2 | 6 | GBP 0.01–0.03 | band | [search](https://www.mouser.co.uk/c/?q=RC0805JR-070RL) |
| U1–U8 | OPA1644 | `OPA1644AID` | 8 | 9 | USD 2.40–4.98 | snippet | [search](https://www.mouser.co.uk/c/?q=OPA1644AID) |
| U9, U10 | SSI2164 | `SSI2164S-RT` | 2 | 3 | GBP 3.80 | read | [search](https://www.mouser.co.uk/c/?q=SSI2164S-RT) |
| U11 | 74AHC541 | `SN74AHC541DWR` | 1 | 2 | GBP 0.40–0.90 | band | [search](https://www.mouser.co.uk/c/?q=SN74AHC541DWR) |
| U12 | MAX6126A25 | `MAX6126AASA25+` | 1 | 2 | USD 8.76–9.96 | snippet | [search](https://www.mouser.co.uk/c/?q=MAX6126AASA25+) |
| U13, U14 | TL074 | `TL074CDR` | 2 | 3 | GBP 0.25–0.70 | band | [search](https://www.mouser.co.uk/c/?q=TL074CDR) |
| U15 | TMR6-2422WI | `TMR 6-2422WI` | 1 | 1 | GBP 18.16 | read | [search](https://www.mouser.co.uk/c/?q=TMR 6-2422WI) |
| U16 | NCP1117-5.0 | `NCP1117DT50RKG` | 1 | 2 | GBP 0.35–0.90 | band | [search](https://www.mouser.co.uk/c/?q=NCP1117DT50RKG) |
| U17 | MCP3564 | `MCP3564-E/ST` | 1 | 2 | GBP 5.35 | read | [search](https://www.mouser.co.uk/c/?q=MCP3564-E/ST) |
| U18 | MCP1700-3.3 | `MCP1700T-3302E/TT` | 1 | 2 | GBP 0.38 | read | [search](https://www.mouser.co.uk/c/?q=MCP1700T-3302E/TT) |
| U19 | RaspberryPi_Pico | `SC0915` | 1 | 1 | GBP 3.60–5.00 | band | [search](https://www.mouser.co.uk/c/?q=SC0915) |
| U21 | TLP2761 | `TLP2761(TP,E)` | 1 | 2 | GBP 1.00–2.20 | band | [search](https://www.mouser.co.uk/c/?q=TLP2761(TP,E)) |
| U22 | TPS560430XF | `TPS560430XFDBVR` | 1 | 2 | GBP 0.70–1.60 | band | [search](https://www.mouser.co.uk/c/?q=TPS560430XFDBVR) |

## The order list, one line per part number

**Part number, quantity — one line each, for a distributor's paste box.** Quantities include the spares rule above, added **once per part number**.

That last clause is the whole reason this is generated rather than copied out of the table. A row above is a *value on a footprint* and an order line is a *part number*, and the two do not correspond: nine rows carry the same two-pin header, because `CH1` through `CH6`, `PWR`, `TAP` and `RESET` each have their own value string. Adding the `order` column down those rows buys 9 x (1 + 4) = 45 headers for a board that uses nine. The three-pin header repeats three times for the same reason. Nothing else on this board does, counted rather than assumed: **63 rows, 53 part numbers.**

```
1N4148W-7-F,14
3403.0168.11,5
61300211121,13
61300311121,7
744222,5
B340A-13-F,5
BAT54-7-F,6
C3225X5R1C226M250AA,5
CC0805KRX7R9BB563,10
CEU4J2X7R1H223K125AE,10
CGA4J2X7R1H104K125AE,40
CGA4J2X7R1H154K125AA,10
CGA6M3X7R1C106K200AB,12
CGA6P3X7R1H475K250AB,5
CNA6P1X7R1H106K250AE,9
DMG1012T-7,2
ERA6AEB103V,18
ERA6AEB1212V,16
G6S-2F DC5,7
GRM2165C1H101JA01D,10
GRM2165C1H122JA01D,16
GRM2165C1H222JA01D,5
GRM21BR71C105KA01L,7
GRM21BR71H474KA88L,11
MAX6126AASA25+,2
MCP1700T-3302E/TT,2
MCP3564-E/ST,2
NCP1117DT50RKG,2
OPA1644AID,9
"PMEG2010AEH,115",3
RC0805FR-07100KL,11
RC0805FR-0710KL,29
RC0805FR-0717K8L,16
RC0805FR-071KL,7
RC0805FR-071ML,16
RC0805FR-07220RL,10
RC0805FR-0722K1L,5
RC0805FR-0722KL,22
RC0805FR-07390RL,5
RC0805FR-074K99L,16
RC0805FR-074R7L,6
RC0805FR-0788K7L,5
RC0805JR-070RL,6
RC0805JR-0710RL,5
RC0805JR-0733RL,5
SC0915,5
SN74AHC541DWR,2
SRN6045TA-150M,5
SSI2164S-RT,3
TL074CDR,3
"TLP2761(TP,E)",2
TMR 6-2422WI,5
TPS560430XFDBVR,2
```

**459 components across 53 part numbers**, against 289 placements on the board.

**2 of those part numbers contain a comma of their own** — `PMEG2010AEH,115`, `TLP2761(TP,E)` — so the lines are written by `csv.writer` and those two arrive quoted. A comma-separated list whose own fields carry commas is a format that works until the parts that break it, and here that is a packaging suffix and a taping code. If a paste box rejects the quotes, split those lines by hand: the quantity is the number after the **last** comma.

Two things this list is not. It is **not rounded to anybody's reel, MOQ or packaging multiple** — that arithmetic belongs in the basket where its numbers are visible. And a part number here is a claim this repository can only half check: `Design.check_order_codes()` decodes a ceramic's case, dielectric, voltage and capacitance and compares all four to the value string and the land, and it says plainly that whether a code names a part that **exists** is a question only a distributor answers.

## Totals, per currency

| | fitted | spares | basket |
|---|---|---|---|
| **GBP** | 60.67 – 96.94 | 25.32 – 47.22 | **85.99 – 144.16** |
| **USD** | 29.76 – 51.60 | 12.96 – 16.74 | **42.72 – 68.34** |

**7 lines carry more than 2.00 of spares and nobody has decided about them.** Reported rather than raised: a spare is a money decision, and a check that fails every build until somebody edits a dict is a check that gets switched off. Put a part in `gen_bom.NO_SPARE` with a reason to settle it.

| part | spares | cost |
|---|---|---|
| `MAX6126AASA25+` | 1 | USD 8.76 – 9.96 |
| `G6S-2F DC5` | 1 | GBP 3.00 – 5.50 |
| `MCP3564-E/ST` | 1 | GBP 5.35 – 5.35 |
| `OPA1644AID` | 1 | USD 2.40 – 4.98 |
| `SSI2164S-RT` | 1 | GBP 3.80 – 3.80 |
| `CNA6P1X7R1H106K250AE` | 4 | GBP 1.20 – 3.20 |
| `TLP2761(TP,E)` | 1 | GBP 1.00 – 2.20 |

Kept per currency rather than converted: two lines were priced in dollars because that is the currency the figures were found in, and folding them into a sterling total at a rate nobody looked up would turn two honest figures into one invented one.

## Notes per line

**C101–C814** — 1210 X7R

**C102–C652** — 0805 C0G

**C121–C621** — 0805 C0G

**C131–C631** — 0805 X7R

**C141–C641** — 0805 X7R

**C142–C642** — 0805 X7R

**C151–C810** — 0805 X7R

**C701–C842** — 0805 X7R

**C805** — 0805 C0G

**C806–C816** — 0805 X7R

**C807–C813** — 1210 X7R at 50 V, which is 4x derating on the +/-12 V rails and 2.5x on the 20 V primary. A 25 V part would be cheaper and would have lost most of its capacitance at the top of the inlet range -- the same argument the mixer makes at its own VIN_P.

**C840** — 1210 X7R at 50 V, 2.5 mm body. It was a 2u2 and the DC bias curve is why -- see design.MCU_DCDC_CIN

**C843** — 1210 X5R

**D151–D805** — 1N4148W-7-F or any 1N4148 in SOD-123 -- the W and not the WS, which is Diodes' SOD-323 part and is what this line asked for until the footprint audit. Inside an op-amp's feedback loop, so the forward drop does not reach the answer.

**D801–D833** — BAT54-7-F, in **SOT-23** -- three terminals, anode 1 and cathode 3, and it sat on a two-pad SOD-123 land until the footprint audit. Five of them do two jobs -- the two-diode pump and three coil flybacks -- and what the pump wants from it is *leakage*, 2 uA max at 25 V, because the same diode has to hold a 1 uF node up between 10 kHz cycles. Its forward drop at the pump's 18 uA is off the bottom of its own table; PUMP_DIODE_VF's 0.32 V sits above the datasheet maximum at ten times that current, deliberately.

**D803, D806** — PMEG2010AEH in SOD123F, and it is the one diode on this board chosen by a number rather than a class. It is a 1 A part carrying 36 mA, which is the whole trick: 259 mV max there against the BAT54's 545 mV, and design.clamp_vf_ceiling() says the mixer's headroom will take 320 mV. The BAT54 that used to be fitted here missed by 5.5 dB. Higher leakage is the price and it is free on a node inside an op-amp's feedback loop. **Buy 40 -- the minimum order, not a mistake.** Nexperia lists it as Production and RS UK stocks tens of thousands, but in a 40-piece minimum, and several distributors quote no stock before 2027. Three substitutes were measured against clamp_vf_ceiling() rather than guessed at: Toshiba's CRS06 lands on this exact footprint and publishes no forward-voltage maximum below 1 A, so the best bound it supports at 36 mA is 360 mV against a 320 mV ceiling; onsemi's NRVB120VLSF clears it at 275 mV and wants a SOD-123FL land KiCad does not ship; Diotec's SKL12 gives one figure, 550 mV at 1 A. Forty of these is GBP 4-12, which is cheaper than any of that. See docs/footprint-audit.md.

**D804** — B340A-13-F, SMA. The mixer's own reverse-protection part, chosen there for a forward drop that falls as the diode is run below its rating -- see design.INLET_DIODE.

**F801** — page fetched: $1.80 at 1, $1.38 at 10, $1.145 at 50, $1.056 at 100, $0.807 at 1000, 16,067 in stock. The listing's 1.6 A, 250 VAC, 125 VDC, Slow Blow and 10.10 x 3.00 x 3.00 mm all agree with the datasheet read for design.INLET_FUSE -- and the 3.00 mm height is what put it in GAP_MM's passive class rather than the tall one. **Its "Breaking Capacity: 200 A AC, 35 A DC" is the datasheet's worst row and not this application's**: note 2) on page 5 gives 35 A only at 250 VDC, against 200 A at 63 VAC/DC, and this inlet is 24 V. A distributor's summary field flattens a table, and the row it keeps is the one that sells the part conservatively.

**J1** — Wurth WR-PHD 1x02 vertical, gold-plated: CONN_MPN[2]. Two ways because the loom is a shielded pair -- the shield lands at the mixer end only, so it has no pin here. See design.FRONT_R.

**J2** — Wurth WR-PHD 1x02 vertical, gold-plated: CONN_MPN[2]. Two ways because the loom is a shielded pair -- the shield lands at the mixer end only, so it has no pin here. See design.FRONT_R.

**J3** — Wurth WR-PHD 1x02 vertical, gold-plated: CONN_MPN[2]. Two ways because the loom is a shielded pair -- the shield lands at the mixer end only, so it has no pin here. See design.FRONT_R.

**J4** — Wurth WR-PHD 1x02 vertical, gold-plated: CONN_MPN[2]. Two ways because the loom is a shielded pair -- the shield lands at the mixer end only, so it has no pin here. See design.FRONT_R.

**J5** — Wurth WR-PHD 1x02 vertical, gold-plated: CONN_MPN[2]. Two ways because the loom is a shielded pair -- the shield lands at the mixer end only, so it has no pin here. See design.FRONT_R.

**J6** — Wurth WR-PHD 1x02 vertical, gold-plated: CONN_MPN[2]. Two ways because the loom is a shielded pair -- the shield lands at the mixer end only, so it has no pin here. See design.FRONT_R.

**J8** — Wurth WR-PHD 1x02 vertical, gold-plated: CONN_MPN[2]. Two ways because the loom is a shielded pair -- the shield lands at the mixer end only, so it has no pin here. See design.FRONT_R.

**J15** — Wurth WR-PHD 1x03 vertical, gold-plated: CONN_MPN[3]. Five on this board, all of them the controller's: MIDI in and out, the expression pedal, boot/reset and SWD. Three conductors is what a TRS jack and a DIN's two used pins both want.

**J16** — Wurth WR-PHD 1x03 vertical, gold-plated: CONN_MPN[3]. Five on this board, all of them the controller's: MIDI in and out, the expression pedal, boot/reset and SWD. Three conductors is what a TRS jack and a DIN's two used pins both want.

**J17** — Wurth WR-PHD 1x02 vertical, gold-plated: CONN_MPN[2]. Two ways because the loom is a shielded pair -- the shield lands at the mixer end only, so it has no pin here. See design.FRONT_R.

**J18** — Wurth WR-PHD 1x03 vertical, gold-plated: CONN_MPN[3]. Five on this board, all of them the controller's: MIDI in and out, the expression pedal, boot/reset and SWD. Three conductors is what a TRS jack and a DIN's two used pins both want.

**J19** — Wurth WR-PHD 1x02 vertical, gold-plated: CONN_MPN[2]. Two ways because the loom is a shielded pair -- the shield lands at the mixer end only, so it has no pin here. See design.FRONT_R.

**K801–K803** — Omron G6S-2F DC5 -- the F is load-bearing: the plain G6S-2 is the through-hole model, eight 1 mm holes per relay, and this board fits the surface-mount land. Single-side stable, which is Omron's name for non-latching and is the property the whole fail-safe turns on. The line worth reading twice is the contact material -- bifurcated crossbar, Ag(Au-Alloy) -- because a plain silver contact needs a wetting current a guitar string will never supply, and fails intermittently in a way that looks like a dry joint.

**L801** — page fetched: £1.97 at 1, £1.94 at 10, £1.75 at 50, £1.69 at 100, £1.37 at 1000 T&R, net of VAT, 12,641 in stock. The listing's own "1 mH @ 100 kHz", 800 mA and 207 mOhm agree with the datasheet read for design.INLET_CHOKE, and its "6 kOhms @ 4 MHz" is the frequency the datasheet's Zmax row omits -- which is what puts 580 kHz on the inductive slope rather than over the peak. The datasheet is at https://www.we-online.com/components/products/datasheet/744222.pdf -- fetched and read.

**L802** — Bourns SRN6045TA-150M, 15 uH, 6.0 x 6.0 mm shielded. Table 1 of the switcher's datasheet asks for 18 uH at 5 V and this series does not make one; 15 is inside the +/-20 % the table's own column heading gives and 22 is 0.4 uH outside it. What the part is chosen against is its Isat of 3.8 A against a 1.4 A peak current limit, which is section 9.2.2.4's rule and 2.7x of it.

**Q801** — Diodes DMG1012T in SOT-523. Chosen for one row of its table: R_DS(on) 0.7 ohm max at V_GS = 1.8 V, which is the gate voltage pump_timing() computes and the only voltage this circuit can produce. Vgs(th) 1.0 V max is the stated filter; being characterised at 1.8 V is what made this part rather than another that meets it.

**R101–R802** — Panasonic ERA-6A thin film, 0.1 %, 25 ppm. Thin film is the specification and not the tolerance -- see FRONT_R.

**R111–R621** — ERA-6A thin film

**R115–R615** — 0805 thick film

**R131–R632** — 0805 thick film

**R141–R656** — 0805 thick film

**R142–R643** — 0805 thick film, E96

**R151–R830** — 0805 thick film. The envelope rectifier's ratios are 1 %, not the 0.1 % the audio path uses: a 2 % ratio error is 0.17 dB on a *reported level*, which is inside what envelope_balance() already allows for the E96 half-value.

**R154–R657** — 0805 thick film, E96

**R803–R816** — 0805 thick film

**R804, R805** — 0805 thick film. Two of them, and they are the rail filter: rail_filter() is why this is a resistor and not an inductor.

**R827** — 0805 1%

**R828** — 0805 5%

**R829** — 0805 5%

**R831–R833** — 0805 1%

**R850** — 0805 1%

**R851** — 0805 1%

**R901, R902** — 0805 jumper

**U1–U8** — **OPA1644AID, the tube, and the suffix is a stock question rather than an obsolescence one.** TI lists AID (SOIC-14, 50 per tube) and AIDR (the same part, 2500 per reel) both ACTIVE; distributors have the tube and quote no in-stock date for the reel. Nine pieces is a tube's business either way. Eight fitted is the largest line on the board, so the stock position matters more than the price.

**U9, U10** — page fetched; states "£3.80 (Excl. VAT)". A UK synth-DIY distributor rather than a catalogue house, which is where this part actually lives.

**U11** — SN74AHC541DWR, SOIC-20W. An ordinary logic part from any of the four UK catalogue houses.

**U12** — The exact A-grade 2.5 V part (MAX6126AASA25+) was not priced directly; this brackets it with the B grade at the same voltage and the A grade at a different one. ADR4525C/D is the second source spec section 4.2 names and is not priced here at all.

**U13, U14** — TL074CDR, SOIC-14. About a tenth of the OPA1644 and stocked everywhere; the SSI2164's own datasheet uses its dual in the same position.

**U15** — page fetched: £18.16 at 1+, £16.89 at 5+, £16.77 at 10+, net of VAT, 87 in stock. The same page states the switching frequency as 580 kHz and the body as 21.8 x 11.2 x 9.1 mm, which agrees with the datasheet read for design.SUPPLY_KHZ_TYP. The datasheet itself is at https://cdn-reichelt.de/documents/datenblatt/C700/TMR6-2411WI_DB.pdf -- fetched and read to the end. tracopower.com's own copy of the same document refuses an automated fetch, and a link nobody could follow is the thing STYLE.md rule 10 is about.

**U16** — NCP1117DT50RKG, DPAK -- the DT50G is obsolete and this is onsemi's own active carrier for the same die. **The DT suffix and not ST**, which is the whole of v5_regulator(): the SOT-223 part is the same die, the same price and 160 C/W against 0.77 W.

**U17** — page fetched: £5.35 at 1, £4.46 at 25, £4.05 at 100, net of VAT, 599 in stock, "20-TSSOP (0.173", 4.40mm Width)". The tube part; MCP3564T-E/ST is the same die on tape. Datasheet DS20006181C at https://download.mikroe.com/documents/datasheets/MCP3564_datasheet.pdf -- fetched and read. Microchip's own ww1 URL 301s to a filehandler that refuses an automated fetch, which is the same obstacle the converter's own datasheet had, and STYLE.md rule 10 says a link nobody can follow is not a citation.

**U18** — page fetched: £0.38 at 1, £0.322 at 25, £0.298 at 100, net of VAT, 81,458 in stock, SOT-23-3. Its 4 uA of quiescent current is the whole reason a third linear rail was affordable: an NCP1117 in the same position is 10 mA maximum, which is a third of the converter's remaining headroom spent on a regulator's own biasing. Datasheet DS20001826F at https://ww1.microchip.com/downloads/aemDocuments/documents/APID/ProductDocuments/DataSheets/MCP1700-Data-Sheet-20001826F.pdf -- fetched; the 336 C/W this design uses is from DS21826B, which publishes the minimum-pad figure revision F drops.

**U19** — Raspberry Pi Pico, SC0915. **The one line on this BOM whose price is published rather than banded**: the Pico datasheet's own Table 6 says US$4.00 at 1+, which is the only figure in this file that came from a vendor's ordering table instead of from a class. It is now the most expensive active on the board after the converter, and it replaced four lines that came to about GBP 3 between them -- the RP2040, the flash, the crystal and the USB receptacle -- plus twelve capacitors, four resistors and two headers. So the parts cost is roughly a wash and what it bought is elsewhere: 0.40 mm of pin pitch became 2.54, which re-opened docs/fabrication-class.md, and about 25 lines of assembly became one.

**U21** — Toshiba TLP2761, SO6L. It is dearer than the 6N138 CA-033 names and the reason is the whole of design.MIDI_OPTO: 2.7 V of supply and 1.6 mA of threshold current, which is what makes a receiver possible on a board whose only logic rail is 3.3 V.

**U22** — TPS560430XFDBVR, SOT-23-6. **The F suffix is the price of this line**: the PFM version is the same die and a few pence cheaper, and design.mcu_dcdc_light_load() shows the PFM sibling would fall to 194 kHz in bypass at idle -- under the >= 300 kHz rule spec section 1.1 sets, on a rail the audio domain shares. The state matters: in circuit the relay coils hold this rail continuous, and bypass is where they let go.

## Not on this BOM

The deferred blocks, each with its reason. None of them is costed here, so the totals above are a floor for the module and not its price.

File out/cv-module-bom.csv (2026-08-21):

Reference | Value | Footprint | MPN | Fitted | Order | Unit low | Unit high | Currency | Qty break | Basis | Source
C101,C201,C301,C401,C501,C601,C802,C814 | 10u/16V X7R | Capacitor_SMD:C_1210_3225Metric | CGA6M3X7R1C106K200AB | 8 | 12 | 0.08 | 0.25 | GBP | 25 | band | typical distributor band, not read this session
C102,C152,C202,C252,C302,C352,C402,C452,C502,C552,C602,C652 | 1200p/50V C0G | Capacitor_SMD:C_0805_2012Metric | GRM2165C1H122JA01D | 12 | 16 | 0.02 | 0.08 | GBP | 100 | band | typical distributor band, not read this session
C121,C221,C321,C421,C521,C621 | 100p/50V C0G | Capacitor_SMD:C_0805_2012Metric | GRM2165C1H101JA01D | 6 | 10 | 0.02 | 0.08 | GBP | 100 | band | typical distributor band, not read this session
C131,C231,C331,C431,C531,C631 | 150n/50V X7R | Capacitor_SMD:C_0805_2012Metric | CGA4J2X7R1H154K125AA | 6 | 10 | 0.02 | 0.08 | GBP | 100 | band | typical distributor band, not read this session
C141,C241,C341,C441,C541,C641 | 56n/50V X7R | Capacitor_SMD:C_0805_2012Metric | CC0805KRX7R9BB563 | 6 | 10 | 0.02 | 0.08 | GBP | 100 | band | typical distributor band, not read this session
C142,C242,C342,C442,C542,C642 | 22n/50V X7R | Capacitor_SMD:C_0805_2012Metric | CEU4J2X7R1H223K125AE | 6 | 10 | 0.02 | 0.08 | GBP | 100 | band | typical distributor band, not read this session
C151,C251,C351,C451,C551,C651,C810 | 470n/50V X7R | Capacitor_SMD:C_0805_2012Metric | GRM21BR71H474KA88L | 7 | 11 | 0.02 | 0.08 | GBP | 100 | band | typical distributor band, not read this session
C701,C702,C703,C704,C705,C706,C707,C708,C709,C710,C711,C712,C713,C714,C715,C716,C717,C718,C719,C720,C721,C722,C723,C724,C801,C803,C809,C817,C818,C819,C835,C836,C837,C838,C841,C842 | 100n/50V X7R | Capacitor_SMD:C_0805_2012Metric | CGA4J2X7R1H104K125AE | 36 | 40 | 0.01 | 0.05 | GBP | 100 | band | typical distributor band, not read this session
C805 | 2n2/50V C0G | Capacitor_SMD:C_0805_2012Metric | GRM2165C1H222JA01D | 1 | 5 | 0.02 | 0.08 | GBP | 100 | band | typical distributor band, not read this session
C806,C815,C816 | 1u/16V X7R | Capacitor_SMD:C_0805_2012Metric | GRM21BR71C105KA01L | 3 | 7 | 0.02 | 0.08 | GBP | 100 | band | typical distributor band, not read this session
C807,C808,C811,C812,C813 | 10u/50V X7R | Capacitor_SMD:C_1210_3225Metric | CNA6P1X7R1H106K250AE | 5 | 9 | 0.30 | 0.80 | GBP | 25 | band | typical distributor band, not read this session
C840 | 4u7/50V X7R | Capacitor_SMD:C_1210_3225Metric | CGA6P3X7R1H475K250AB | 1 | 5 | 0.08 | 0.30 | GBP | 25 | band | typical distributor band, not read this session
C843 | 22u/16V X5R | Capacitor_SMD:C_1210_3225Metric | C3225X5R1C226M250AA | 1 | 5 | 0.08 | 0.30 | GBP | 25 | band | typical distributor band, not read this session
D151,D152,D251,D252,D351,D352,D451,D452,D551,D552,D651,D652,D805 | 1N4148W | Diode_SMD:D_SOD-123 | 1N4148W-7-F | 13 | 14 | 0.02 | 0.08 | GBP | 100 | band | typical distributor band, not read this session
D801,D802,D813,D823,D833 | BAT54 | Package_TO_SOT_SMD:SOT-23 | BAT54-7-F | 5 | 6 | 0.05 | 0.15 | GBP | 100 | band | typical distributor band, not read this session
D803,D806 | PMEG2010AEH | Diode_SMD:D_SOD-123F | PMEG2010AEH,115 | 2 | 3 | 0.10 | 0.30 | GBP | 100 | band | typical distributor band, not read this session
D804 | B340A | Diode_SMD:D_SMA | B340A-13-F | 1 | 2 | 0.20 | 0.60 | GBP | 10 | band | typical distributor band, not read this session
F801 | 1.6A T 250V | Fuse:Fuse_Schurter_UMT250 | 3403.0168.11 | 1 | 2 | 1.80 | 1.80 | USD | 1 | read | https://www.digikey.com/en/products/detail/schurter-inc/3403-0168-11/957690
J1 | CH1 | Connector_PinHeader_2.54mm:PinHeader_1x02_P2.54mm_Vertical | 61300211121 | 1 | 2 | 0.25 | 0.60 | GBP | 10 | band | typical distributor band, not read this session
J2 | CH2 | Connector_PinHeader_2.54mm:PinHeader_1x02_P2.54mm_Vertical | 61300211121 | 1 | 2 | 0.25 | 0.60 | GBP | 10 | band | typical distributor band, not read this session
J3 | CH3 | Connector_PinHeader_2.54mm:PinHeader_1x02_P2.54mm_Vertical | 61300211121 | 1 | 2 | 0.25 | 0.60 | GBP | 10 | band | typical distributor band, not read this session
J4 | CH4 | Connector_PinHeader_2.54mm:PinHeader_1x02_P2.54mm_Vertical | 61300211121 | 1 | 2 | 0.25 | 0.60 | GBP | 10 | band | typical distributor band, not read this session
J5 | CH5 | Connector_PinHeader_2.54mm:PinHeader_1x02_P2.54mm_Vertical | 61300211121 | 1 | 2 | 0.25 | 0.60 | GBP | 10 | band | typical distributor band, not read this session
J6 | CH6 | Connector_PinHeader_2.54mm:PinHeader_1x02_P2.54mm_Vertical | 61300211121 | 1 | 2 | 0.25 | 0.60 | GBP | 10 | band | typical distributor band, not read this session
J8 | PWR | Connector_PinHeader_2.54mm:PinHeader_1x02_P2.54mm_Vertical | 61300211121 | 1 | 2 | 0.25 | 0.60 | GBP | 10 | band | typical distributor band, not read this session
J15 | MIDIIN | Connector_PinHeader_2.54mm:PinHeader_1x03_P2.54mm_Vertical | 61300311121 | 1 | 2 | 0.30 | 0.75 | GBP | 10 | band | typical distributor band, not read this session
J16 | MIDIOUT | Connector_PinHeader_2.54mm:PinHeader_1x03_P2.54mm_Vertical | 61300311121 | 1 | 2 | 0.30 | 0.75 | GBP | 10 | band | typical distributor band, not read this session
J17 | TAP | Connector_PinHeader_2.54mm:PinHeader_1x02_P2.54mm_Vertical | 61300211121 | 1 | 2 | 0.25 | 0.60 | GBP | 10 | band | typical distributor band, not read this session
J18 | EXPR | Connector_PinHeader_2.54mm:PinHeader_1x03_P2.54mm_Vertical | 61300311121 | 1 | 2 | 0.30 | 0.75 | GBP | 10 | band | typical distributor band, not read this session
J19 | RESET | Connector_PinHeader_2.54mm:PinHeader_1x02_P2.54mm_Vertical | 61300211121 | 1 | 2 | 0.25 | 0.60 | GBP | 10 | band | typical distributor band, not read this session
K801,K802,K803 | G6S-2F DC5 | Relay_SMD:Relay_DPDT_Omron_G6S-2F | G6S-2F DC5 | 3 | 4 | 3.00 | 5.50 | GBP | 10 | band | typical distributor band, not read this session
L801 | 744222 | Inductor_SMD:L_CommonMode_Wuerth_WE-SL2 | 744222 | 1 | 2 | 1.97 | 1.97 | GBP | 1 | read | https://www.digikey.co.uk/en/products/detail/w%C3%BCrth-elektronik/744222/1638889
L802 | 15u 20% | Inductor_SMD:L_Bourns_SRN6045TA | SRN6045TA-150M | 1 | 2 | 0.30 | 0.90 | GBP | 25 | band | typical distributor band, not read this session
Q801 | DMG1012T | Package_TO_SOT_SMD:SOT-523 | DMG1012T-7 | 1 | 2 | 0.06 | 0.20 | GBP | 100 | band | typical distributor band, not read this session
R101,R102,R201,R202,R301,R302,R401,R402,R501,R502,R601,R602,R801,R802 | 10k 0.1% | Resistor_SMD:R_0805_2012Metric | ERA6AEB103V | 14 | 18 | 0.10 | 0.30 | GBP | 100 | band | typical distributor band, not read this session
R111,R121,R211,R221,R311,R321,R411,R421,R511,R521,R611,R621 | 12k1 0.1% | Resistor_SMD:R_0805_2012Metric | ERA6AEB1212V | 12 | 16 | 0.10 | 0.30 | GBP | 25 | band | typical distributor band, not read this session
R115,R215,R315,R415,R515,R615 | 220R 1% | Resistor_SMD:R_0805_2012Metric | RC0805FR-07220RL | 6 | 10 | 0.01 | 0.03 | GBP | 100 | band | typical distributor band, not read this session
R131,R132,R231,R232,R331,R332,R431,R432,R531,R532,R631,R632 | 1M 1% | Resistor_SMD:R_0805_2012Metric | RC0805FR-071ML | 12 | 16 | 0.01 | 0.03 | GBP | 100 | band | typical distributor band, not read this session
R141,R144,R156,R241,R244,R256,R341,R344,R356,R441,R444,R456,R541,R544,R556,R641,R644,R656 | 22k 1% | Resistor_SMD:R_0805_2012Metric | RC0805FR-0722KL | 18 | 22 | 0.01 | 0.03 | GBP | 100 | band | typical distributor band, not read this session
R142,R143,R242,R243,R342,R343,R442,R443,R542,R543,R642,R643 | 17k8 1% | Resistor_SMD:R_0805_2012Metric | RC0805FR-0717K8L | 12 | 16 | 0.01 | 0.03 | GBP | 100 | band | typical distributor band, not read this session
R151,R152,R153,R155,R251,R252,R253,R255,R351,R352,R353,R355,R451,R452,R453,R455,R551,R552,R553,R555,R651,R652,R653,R655,R830 | 10k 1% | Resistor_SMD:R_0805_2012Metric | RC0805FR-0710KL | 25 | 29 | 0.01 | 0.03 | GBP | 100 | band | typical distributor band, not read this session
R154,R157,R254,R257,R354,R357,R454,R457,R554,R557,R654,R657 | 4k99 1% | Resistor_SMD:R_0805_2012Metric | RC0805FR-074K99L | 12 | 16 | 0.01 | 0.03 | GBP | 100 | band | typical distributor band, not read this session
R803,R811,R812,R813,R814,R815,R816 | 100k 1% | Resistor_SMD:R_0805_2012Metric | RC0805FR-07100KL | 7 | 11 | 0.01 | 0.03 | GBP | 100 | band | typical distributor band, not read this session
R804,R805 | 4R7 1% | Resistor_SMD:R_0805_2012Metric | RC0805FR-074R7L | 2 | 6 | 0.01 | 0.03 | GBP | 100 | band | typical distributor band, not read this session
R827 | 390R 1% | Resistor_SMD:R_0805_2012Metric | RC0805FR-07390RL | 1 | 5 | 0.01 | 0.05 | GBP | 100 | band | typical distributor band, not read this session
R828 | 33R 5% | Resistor_SMD:R_0805_2012Metric | RC0805JR-0733RL | 1 | 5 | 0.01 | 0.05 | GBP | 100 | band | typical distributor band, not read this session
R829 | 10R 5% | Resistor_SMD:R_0805_2012Metric | RC0805JR-0710RL | 1 | 5 | 0.01 | 0.05 | GBP | 100 | band | typical distributor band, not read this session
R831,R832,R833 | 1k 1% | Resistor_SMD:R_0805_2012Metric | RC0805FR-071KL | 3 | 7 | 0.01 | 0.05 | GBP | 100 | band | typical distributor band, not read this session
R850 | 88k7 1% | Resistor_SMD:R_0805_2012Metric | RC0805FR-0788K7L | 1 | 5 | 0.01 | 0.05 | GBP | 100 | band | typical distributor band, not read this session
R851 | 22k1 1% | Resistor_SMD:R_0805_2012Metric | RC0805FR-0722K1L | 1 | 5 | 0.01 | 0.05 | GBP | 100 | band | typical distributor band, not read this session
R901,R902 | 0R | Resistor_SMD:R_0805_2012Metric | RC0805JR-070RL | 2 | 6 | 0.01 | 0.03 | GBP | 100 | band | typical distributor band, not read this session
U1,U2,U3,U4,U5,U6,U7,U8 | OPA1644 | Package_SO:SOIC-14_3.9x8.7mm_P1.27mm | OPA1644AID | 8 | 9 | 2.40 | 4.98 | USD | 1 | snippet | https://octopart.com/opa1644aid-texas+instruments-18186989
U9,U10 | SSI2164 | Package_SO:SOIC-16_3.9x9.9mm_P1.27mm | SSI2164S-RT | 2 | 3 | 3.80 | 3.80 | GBP | 1 | read | https://www.thonk.co.uk/shop/ssi2164/
U11 | 74AHC541 | Package_SO:SOIC-20W_7.5x12.8mm_P1.27mm | SN74AHC541DWR | 1 | 2 | 0.40 | 0.90 | GBP | 10 | band | typical distributor band, not read this session
U12 | MAX6126A25 | Package_SO:SOIC-8_3.9x4.9mm_P1.27mm | MAX6126AASA25+ | 1 | 2 | 8.76 | 9.96 | USD | 1 | snippet | Digi-Key, via search; MAX6126B25+ at $8.76/1 and MAX6126AASA50+ at $9.96/1
U13,U14 | TL074 | Package_SO:SOIC-14_3.9x8.7mm_P1.27mm | TL074CDR | 2 | 3 | 0.25 | 0.70 | GBP | 10 | band | typical distributor band, not read this session
U15 | TMR6-2422WI | cv:TRACO_TMR-6-xxxxWI_Dual_THT | TMR 6-2422WI | 1 | 1 | 18.16 | 18.16 | GBP | 1 | read | https://www.tme.eu/gb/details/tmr6-2422wi/dc-dc-converters/traco-power/tmr-6-2422wi/
U16 | NCP1117-5.0 | Package_TO_SOT_SMD:TO-252-2 | NCP1117DT50RKG | 1 | 2 | 0.35 | 0.90 | GBP | 10 | band | typical distributor band, not read this session
U17 | MCP3564 | Package_SO:TSSOP-20_4.4x6.5mm_P0.65mm | MCP3564-E/ST | 1 | 2 | 5.35 | 5.35 | GBP | 1 | read | https://www.digikey.co.uk/en/products/detail/microchip-technology/MCP3564-E-ST/11618284
U18 | MCP1700-3.3 | Package_TO_SOT_SMD:SOT-23 | MCP1700T-3302E/TT | 1 | 2 | 0.38 | 0.38 | GBP | 1 | read | https://www.digikey.co.uk/en/products/detail/microchip-technology/MCP1700T-3302E-TT/652676
U19 | RaspberryPi_Pico | Module:RaspberryPi_Pico_SMD_HandSolder | SC0915 | 1 | 1 | 3.60 | 5.00 | GBP | 1 | band | typical distributor band, not read this session
U21 | TLP2761 | Package_SO:SO-6L_10x3.84mm_P1.27mm | TLP2761(TP,E) | 1 | 2 | 1.00 | 2.20 | GBP | 10 | band | typical distributor band, not read this session
U22 | TPS560430XF | Package_TO_SOT_SMD:SOT-23-6 | TPS560430XFDBVR | 1 | 2 | 0.70 | 1.60 | GBP | 10 | band | typical distributor band, not read this session

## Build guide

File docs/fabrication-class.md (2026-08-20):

# The fabrication class — decided against PCBWay, at 0.20 / 0.20 on 1 oz

**Fitted: 0.20 / 0.20 mm track and clearance, 1 oz outer copper, 0.7 / 0.3 mm
vias.** `rules.FABRICATOR = "PCBWay"`, and it clears **both** fabricators:

| | track | space | annular ring |
|---|---|---|---|
| PCBWay, 1 oz | 0.127 → **+57 %** | 0.152 → **+32 %** | 0.15 → **+33 %** |
| JLCPCB, 1 oz | 0.09 → +122 % | 0.09 → +122 % | 0.05 → +300 % |

PCBWay is the binding floor in every row and at every copper weight, so
designing to it leaves JLCPCB open as a second source for nothing.

## What actually picked it, and it is not the margin column

Two SOIC pins leave **0.67 mm** of bare laminate between them
(`escape_corridor()`), and a track through that gap needs `track + 2 ×
clearance`:

| class | w + 2c | through a SOIC? | PCBWay 1 oz margin |
|---|---|---|---|
| **0.20 / 0.20** | 0.600 | **yes**, 0.07 mm spare | +57 % / +32 % |
| 0.25 / 0.25 | 0.750 | **no** | +97 % / +64 % |

The coarser class has *more* margin over the process and **cannot pass between
two pins of a SOIC** — on a board carrying a SOIC-20W, two SOIC-16, several
SOIC-14 and a SOIC-8. So the two figures point opposite ways and the corridor
is the one that decides, because margin over a published minimum is
insurance and the corridor is a routing capability you either have or do not.

**It is a 1 oz class and only a 1 oz class.** At 2 oz PCBWay's spacing floor is
0.203 mm, so 0.20 is 1.5 % *under* it — near enough to read as fine, and not.
This project wrote down "0.20/0.20 on 1 oz or 2 oz" once and it was wrong.

## Why not 2 oz

**Nothing on this board has ever wanted it.** `rules.track_current()` puts the
largest current here — 92.7 mA of relay coil — at **0.088 °C of rise** on
0.20 mm of 1 oz, against 0.028 °C at 2 oz. Both are noise. The weight was
carried for five passes as a free option, in this file's own words *"chosen to
be legal at either weight ... keeping the option costs nothing"*, and was never
bought against a requirement; it was then spent by the QFN, which has gone.

**And at 2 oz it would now cost something real.** The floor is 0.178 / 0.203,
so a track through the SOIC corridor needs 0.584 mm of the 0.67 available and
leaves **0.086 mm of total slack** to spend on margin. At 2 oz you choose
between holding margin over the process and routing between two pins of a
SOIC. At 1 oz you get both.

## The annular ring, which nothing was checking

A 0.6 mm via on a 0.3 mm drill is a **0.150 mm** annular ring against PCBWay's
published *"Min Width of Annular Ring: 0.15mm(6mil)"* — exactly on the floor,
on 767 vias, and passing every check in `rules.py` because each of them asked
about the diameter or the drill and none computed the quantity that is a
function of both. **0.7 / 0.3 mm**, a 0.200 mm ring, a third over.
`check_fab_class()` computes it now.

---

> ## The reading that got this wrong, kept
>
> ### ⚠ Everything below this line was decided against JLCPCB
>
> **Every number on this page was read from JLCPCB's capabilities page, and
> the board goes to PCBWay.** The reading was careful, first-hand and quoted;
> what was never asked is whether it was the right page. That is a different
> failure from citing a source without reading it — the repo's own STYLE.md
> rule 10 — and it costs the same, because a check that enforces the right
> number against the wrong process passes for the whole life of the mistake.
> `rules.FABRICATOR` and `rules.FAB_LIMITS` carry both tables now and
> `check_fab_class()` fails.
>
> **PCBWay's published outer-layer minimums**, capabilities page read
> 2026-08-19, converted from mil:
>
> | copper | normal | medium |
> |---|---|---|
> | 35 µm = 1 oz | **0.127 / 0.152 mm** | 0.127 / 0.127 mm |
> | 70 µm = 2 oz | **0.178 / 0.203 mm** | 0.152 / 0.178 mm |
>
> with a headline "Standard PCB" row giving *"0.1mm/4mil"* for both, and no
> copper weight attached to it. **Those two disagree and this page does not
> resolve it** — 0.1 mm is finer than the 1 oz row allows, so one is a
> marketing summary and the other is process engineering, and the document
> does not say which. The by-weight table is what `rules.py` enforces, because
> it is the one that distinguishes what the decision turns on.
>
> **Three things follow, and the first is the expensive one:**
>
> 1. **The fitted 0.09 / 0.09 is not manufacturable at PCBWay at any copper
>    weight** — 29 % under the 1 oz track minimum and 41 % under the spacing.
>    The only 3.5 mil entry on the page is at 18 µm, half an ounce, and is
>    qualified *"or parts 3.5/3.5mil"*. So the 55,854 segments on the board
>    are at a class the target fabricator does not offer, and **the routing has
>    to be redone whatever else is decided.**
> 2. **That removes the argument that put 0.09 / 0.09 back.** The reversal
>    below was justified entirely by preserving the existing copper. The
>    copper cannot be preserved, so the class is a free choice again and the
>    derivation in *The reversal* — 0.205 mm or finer for the finest pitch on
>    the board — is the live one. Against PCBWay's table that is met
>    comfortably by 1 oz normal and by 2 oz normal.
> 3. **It also reopens the controller.** The RP2040's QFN-56 was ruled out
>    because `route.py` could not reach 0.40 mm; `route.py` is deleted, and a
>    person can hand-route it. Against PCBWay's own numbers, a track leaving a
>    QFN pad on its own centre line has 0.211 mm of room against the 0.203 mm
>    that 2 oz normal requires — **4 % of margin** — and 0.237 mm against the
>    0.152 mm that 1 oz normal requires, which is comfortable. So the QFN is
>    buildable at 1 oz and is at the edge of the process at 2 oz, where the
>    Pico's 2.54 mm is not near any edge at either. **That is a decision about
>    how much process margin to hold, and it is not one this file can take.**
>
> Everything below is kept because the arithmetic in it is still correct and
> because it is the record of two mistakes worth not repeating.

---

# The fabrication class — decision, a reversal, and the reversal reversed

**Fitted: 0.09 / 0.09 mm track and clearance, on 1 oz outer copper — unchanged.**
`rules.COPPER_OZ`, `rules.TRACK_MM`, `rules.CLEARANCE_MM`.

> **This section was written as a decision to move to 0.15 / 0.15 on 2 oz, and
> that was wrong.** The derivation below it is correct and it is a fact about
> the *parts*: with the QFN gone, the finest pitch left needs 0.205 mm or
> finer and the 2 oz minimum class clears it. **What it omits is the copper.**
> This board carries 55,854 track segments laid at 0.09 / 0.09 on a 0.23 mm
> routing grid, and they are the starting point for the hand routing rather
> than something to throw away. Two adjacent tracks on that grid are 0.23 mm
> apart: 0.09 mm wide leaves a 0.14 mm gap against a 0.09 mm clearance and is
> legal; 0.15 mm wide leaves 0.08 mm against 0.15 and is not. So the coarser
> class does not merely fail to help — **it condemns every one of those
> segments, and widening them is not available either.**
>
> The shape of the mistake is this repo's oldest, arriving somewhere new: **a
> derivation that asks what the parts need and never asks what the board
> already has.** It is the same omission as `RAIL_FILTER_ESR` and as the
> A/mm² reading below — not a wrong number, a number computed without the term
> that dominates.
>
> **The arithmetic is kept because it is not wasted.** It is the answer for a
> board routed from nothing, so if the existing routing is ever ripped up,
> 0.15 / 0.15 on 2 oz is ready to use. The class is a free choice only when
> there is no copper; while there is, it is a property of the copper.

**This page is kept whole and it is read from the bottom.** Everything between
here and *The reversal* is the argument for 0.09 / 0.09 on 1 oz, which was
fitted, built and DRC-clean, and which was correct for the board it was decided
on. What changed is not a number in it: the RP2040's 0.40 mm QFN-56 became a
2.54 mm Raspberry Pi Pico, and the QFN was the whole of why the class was fine.
Rewriting the argument in place would have destroyed the only record of what a
0.40 mm pitch costs — which is the thing worth knowing if a part like it is ever
wanted again.

---

## The reversal, and it is not simply "put it back"

**Nothing on this board has an opinion about pin pitch any more, so this went
back to being a free choice — and a free choice still has to be taken by
arithmetic.** `rules.coarsest_class_for()` answers it against the *finest pitch
left on the board*, which is the MCP3564's TSSOP-20 at 0.65 mm:

| | needs | |
|---|---|---|
| RP2040 QFN-56, 0.40 mm | **0.12 / 0.12 mm or finer** | below the 2 oz floor, so 1 oz was the price |
| MCP3564 TSSOP-20, 0.65 mm | **0.205 / 0.205 mm or finer** | above the 2 oz floor of 0.15, so either weight works |

So the 2 oz minimum class clears the board by 27 % and the class that was
fitted *before* the QFN — 0.25 / 0.20 — does not. **The reversal is not to the
old value.** That is worth stating plainly, because "put it back" is what
everybody would have written down.

**Between 0.09 and 0.15 the arithmetic is silent and three other things are
not:**

* **it is not bought for current.** `rules.track_current()` puts the largest
  current on this board — 92.7 mA of relay coil — at 0.33 °C of rise on 0.09 mm
  of 1 oz and 0.045 °C on 0.15 mm of 2 oz. Both are nothing. Current capacity
  was never the reason and this section says so rather than letting 2 oz look
  like a current decision;
* **0.09 / 0.09 is the published floor with no margin at all**, which its own
  decision above records as the honest cost. 0.15 / 0.15 is the floor for 2 oz
  and 67 % above the finest class available, so process variation has somewhere
  to go;
* **the board is hand-routed now**, and that is this session's argument rather
  than a rediscovered one. A person laying 0.09 mm track on 0.09 mm clearance is
  working at the fabricator's limit with no room for a judgement call, and
  judgement is the whole of what `gen_pcb.py` giving up the router buys.

## What is no longer measurable, and it is the row this decision used to rest on

The four-row table below is `gen_pcb.py` end to end, and **two of its four
columns have stopped existing.** There is no router, so there is no "time" and
no "unrouted"; what is left is DRC, and DRC on a board with no signal copper on
it is a weak instrument.

That matters most for the third row — 0.25 / 0.20 with corrected via rules, 454
seconds, **10 unrouted (V5)**. It is the row that says a coarse class costs
connections, and it was a measurement of *this router* at a uniform 0.5 mm grid.
A person routing by hand is not on a grid and is not bound by it. So the row is
kept as history and **it is not evidence about the class fitted now**, in either
direction: it does not condemn 0.15 / 0.15, which was never measured, and it
does not excuse it.

**What replaces the measurement is that the fabricator's own floor is a
published number and `rules.check_fab_class()` runs against it on every build.**
That is a weaker guarantee than a routed board and it is the one that is
available, and saying which is which is the point of this section.

---

## What asked the question

Nothing on this board needed a fine class for five passes. `rules.py` said so in
as many words — *"the rules below are chosen to be legal at either weight ...
keeping the option costs nothing"* — and that was true, with the caveat attached
to it: *"it stops costing nothing the moment anything asks for 0.09 mm."*

The controller asked. RP2040 ships in one package, a 7 × 7 QFN-56 at 0.40 mm
pitch on 0.20 mm pads, and `rules.fan_out_class()` puts that off the bottom of
its three-rung ladder at the class that was fitted:

| condition | at 0.25 / 0.20 | why |
|---|---|---|
| a track fits on the pad's centre line | ✗ 0.20 mm allowed against a 0.25 mm track | the neighbour's copper is 0.30 mm from the centre line |
| each pin gets its own grid line | ✗ 0.40 mm pitch on a 0.50 mm grid | an escape moves at most half a pitch, so pins map onto lines in order |
| the turn to the grid clears the neighbour | ✗ 0.225 mm against 0.300 needed | the turn is ordinary track pointing at a pin 0.40 mm away |

`rules.coarsest_class_for()` solves rather than tabulates: **0.12 / 0.12 mm or
finer.** That is below JLCPCB's 0.15 mm floor for 2 oz outer copper and above its
0.09 mm one, so there is no intermediate class and the copper weight is part of
the answer.

## What decided it, and it was not an argument

Four combinations, `gen_pcb.py` end to end on the same machine and board:

| class | via rules | time | unrouted | DRC violations |
|---|---|---|---|---|
| 0.25 / 0.20, 2 oz | ring of four | 89 s | 0 | 0 |
| 0.09 / 0.09, 1 oz | ring of four | 69 s | 0 | 56 |
| 0.25 / 0.20, 2 oz | **corrected** | **454 s** | **10 (V5)** | 0 |
| 0.09 / 0.09, 1 oz | **corrected** | **89 s** | **0** | **0** |

Only the last row is a complete, DRC-clean board.

The middle two rows are the interesting ones. **The board that used to close was
closing on geometry the router had no rule for.** `route.py` carried a via's
clearance as a ring of four cells, with a derivation that is entirely correct at a
0.50 mm grid on 0.25 / 0.20 copper and was written as though it were a fact about
the geometry. `rules.via_exclusion()` asks it properly — three distances, because
a via is near three kinds of thing, each the stricter of a **copper** rule that
shrinks with the class and a **hole** rule that does not. Correcting it cost the
coarse class the 5 V rail and five times the routing time, and cost the fine class
nothing.

DRC had agreed with the old board because its two illegal cases — a via inside the
annulus 0.325 to 0.500 mm from a foreign pad, and two vias on diagonal cells
0.707 mm apart against a 0.800 mm requirement — were never *attempted* at that
grid. Latent, not absent.

## What it costs

**Current capacity, and the answer is a third of a degree.** `rules.track_current()`
puts `design.coil_budget()`'s 92.7 mA — the largest current anywhere on this
board, and the only one that is not microamps — at **0.33 °C of rise** on 0.09 mm
of 1 oz copper. That figure is 4.0 °C even if the borrowed IPC-2221 constant is
three times out, which is why it is quoted at all: the standard is paywalled and
what was read is a set of independent third-party calculators agreeing on the fit.
The conclusion survives the source being wrong by a lot, which is the same shape
as `design.controller_supply()`'s efficiency bound.

**The figure that made this look like a trade was 29 A/mm², and it was the wrong
instrument.** Current density divides by the cross-section, which carries the
current, and omits the surface area, which does the cooling — which is why
IPC-2221's exponent on area is 0.725 and not 1. It is the same failure as the
mixer's `RAIL_FILTER_ESR`: not a wrong number, a number computed without the term
that dominates.

**Margin, and this is the honest debit.** 0.25 / 0.20 was 1.7× and 1.33× the
published floor; 0.09 / 0.09 *is* the floor. What is left protecting the board is
`PITCH_MARGIN_MM` on top of the routing pitch, and DRC running against these
numbers on every build with `verify.check_rules()` holding all three files to
them.

**Not build time, which was predicted the wrong way round.** 4.7× the grid cells
runs 22 % *faster*, because the router's cost is dominated by contention — routes
that fail, probe, rip up and retry — and a finer grid has far less of it.
`rules.grid_cost()` records the measurement and the wrong prediction it replaced.

## What it buys

* **The RP2040 becomes routable**, with no fan-out escape needed anywhere — the
  pads are directly reachable at a 0.23 mm grid. `design.controller_package()`.
* **The fan-out goes dormant.** `route.Grid.escape()` was written to close four
  nets at U17's TSSOP at the old class, and at this one the TSSOP needs no escape
  either. It is not wasted — it is the mechanism the QFN would have needed at any
  class between the two, and it is what closed the board it was written for — but
  nothing on the board exercises it today. Said here rather than left to be
  discovered.
* **The 5 V rail closes**, which the coarse class could not do once the via rules
  were right.

## What reversing it would cost, and it is not the part

Worth stating exactly, because it is easy to overstate. At any coarser class the
RP2040's QFN-56 is unreachable **by this router** — and that qualifier carries the
whole meaning. `rules.route_pitch()` ties the routing grid to the fabrication
class, `grid = track + clearance + margin`, and its derivation holds only because
`route.py` permits tracks on adjacent cells:

> two tracks on adjacent cells are `pitch − track` apart, and that has to clear
> `clearance`

That is a property of this router, not of copper. A router with a grid finer than
`track + clearance`, enforcing spacing as a rule rather than through the pitch,
decouples the two — which is how commercial routers do it, and why 0.40 mm QFNs
go onto 2 oz boards routinely.

So reversing this decision costs router work in one of three forms, and the part
is the price only if all three are refused:

| | |
|---|---|
| **decouple the grid from the class** in `route_pitch()` | the general fix; it would retire the fan-out question at every class |
| **build the spreading fan** | at 0.15/0.15 only *one* of `fan_out_class()`'s three conditions fails — the jog, by 0.075 mm — and this is exactly its mechanism. At 0.25/0.20 all three fail and it is a bigger job |
| **hand-route the escape region** | against this repo's generate-don't-draw principle, and legitimate |

Nothing about the board as it stands is contingent on this: it is complete, clean
and routing in 89 s at the class that is fitted. This section exists because the
first prose written about the decision said reversing it "costs the RP2040",
which reads "this router cannot" as "cannot be done" — the same substitution the
four overturned predictions above were made of.

## ~~What is not decided here~~ — decided, and the question did not survive being asked properly

**It is decided.** DRC now enforces `rules.hole_rules()`, written into the
project as `min_hole_to_hole` and `min_hole_clearance` and held by
`verify.check_rules()` like every other rule. What the question turned out to
be is the interesting part, and the original text is below.

**The open item asked which of two numbers to take — and one of them was
JLCPCB's, on a board that goes to PCBWay.** Same fault as this whole page's
top block, one table along, and it survived the fabricator moving because a
hole rule looks like a fact about drills rather than a fact about a supplier.

PCBWay's own capabilities page, read 2026-08-19, normal-process column,
converted from mil:

| | published | KiCad's default | in force |
|---|---|---|---|
| component hole to hole | **0.406 mm** (16 mil) | 0.25 mm | **0.406**, the fabricator's |
| via to via, ⌀ ≤ 0.45 | 0.279 mm (11 mil) | 0.25 mm | — |
| hole to copper, 4 layers | 0.178 mm (7 mil) | **0.25 mm** | **0.25**, KiCad's |

**So the fabricator is stricter on one and looser on the other, and there was
never a single comparison to make.** The rule stays "the stricter of the
published figure and KiCad's own", which is only worth having now that it
points both ways. The board's 0.7 mm vias are above PCBWay's own `⌀ ≤ 0.45`
qualifier, so they are read as component holes — the reading that cannot be
wrong in the direction that matters, and 0.127 mm on a rule that does not bind.

**Neither number binds at this class**, which is what makes adopting them free.
`rules.via_exclusion()` gives a via 0.650 / 0.900 / 0.550 mm to a track, another
via and a pad's copper, and the *copper* rule sets all three. The trap the
original text names is avoided by construction rather than by refusing to
choose: **nothing here makes a violation disappear**, because the number that
moved moved the wrong way for that — 0.406 is 62 % stricter than what DRC has
been running.

> ### The original, kept
>
> **What DRC enforces for hole clearance is deliberately unchanged.** JLCPCB
> publishes *"Via Hole-to-Hole Spacing: 0.2mm"* and *"Via hole to Track:
> 0.2mm"*; KiCad's own default is 0.25 mm and is what has been in force,
> unowned, the same way `min_track_width` once sat at zero. The published
> figures are recorded in `rules.py` and the router is held to the stricter of
> the two. Declaring 0.20 would have made 49 violations disappear with no
> copper moving, which is indistinguishable from relaxing a check to make it
> pass — so designing to the fabricator's real limit is left as a separate
> decision, to be taken deliberately or not at all.
>
> Every clause of that is right except the page the numbers came from.

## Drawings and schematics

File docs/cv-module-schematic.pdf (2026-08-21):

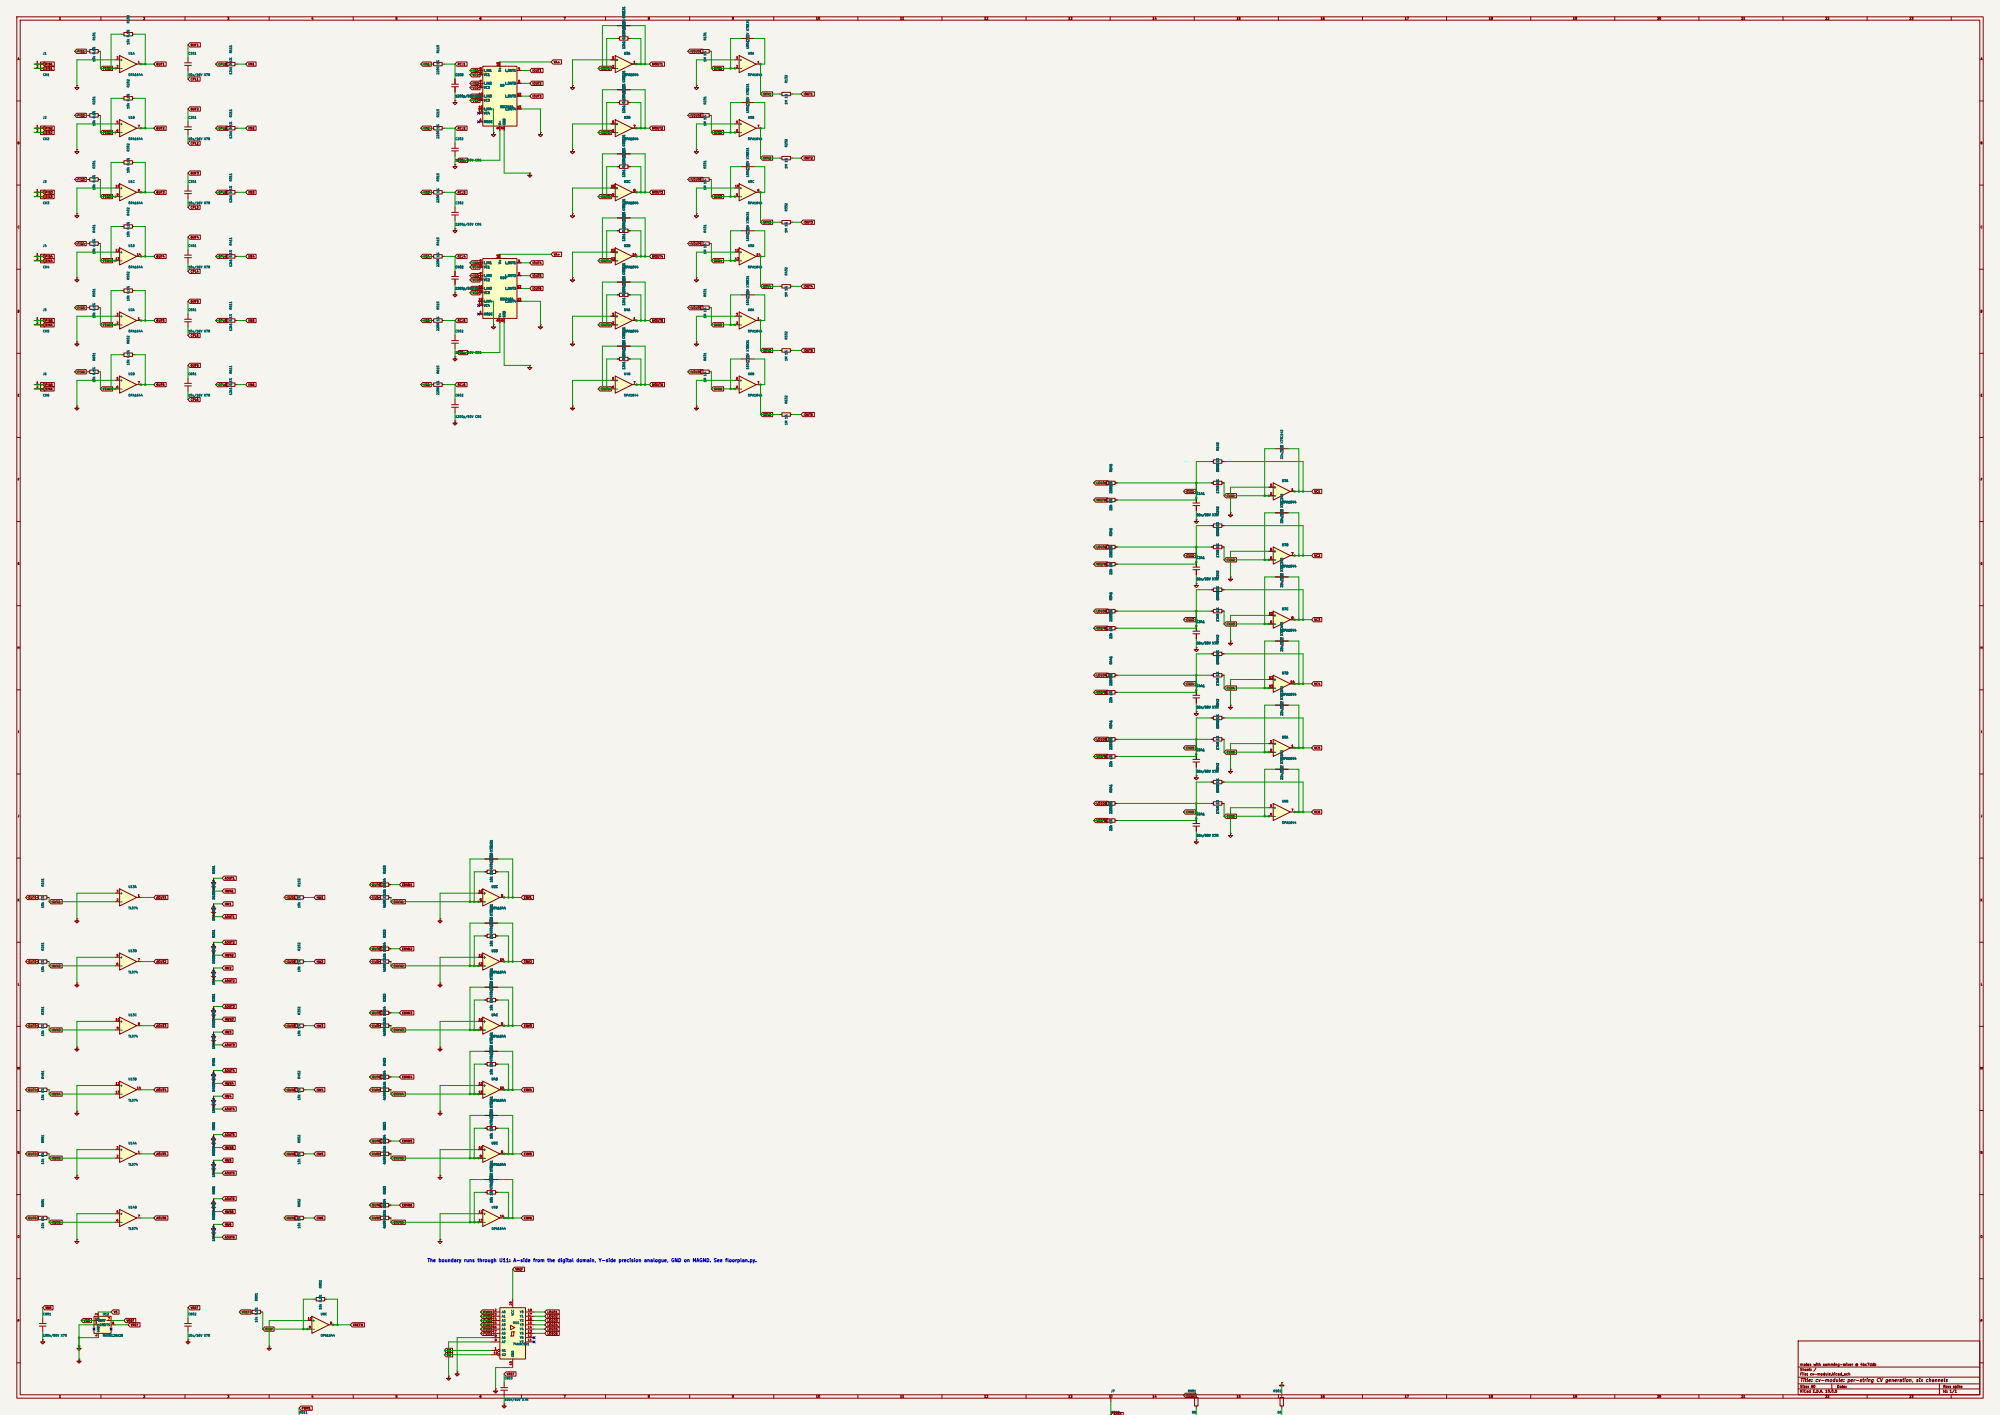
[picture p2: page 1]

The boundary runs through U11: A-side from the digital domain, Y-side precision analogue, GND on MAGND. See floorplan.py.

mates with summing-mixer @ 4bc7ddb
Sheet: /
File: cv-module.kicad_sch
Title: cv-module: per-string CV generation, six channels

Size: A0 | Rev: spike
KiCad E.D.A. 10.0.5 | Id: 1/1

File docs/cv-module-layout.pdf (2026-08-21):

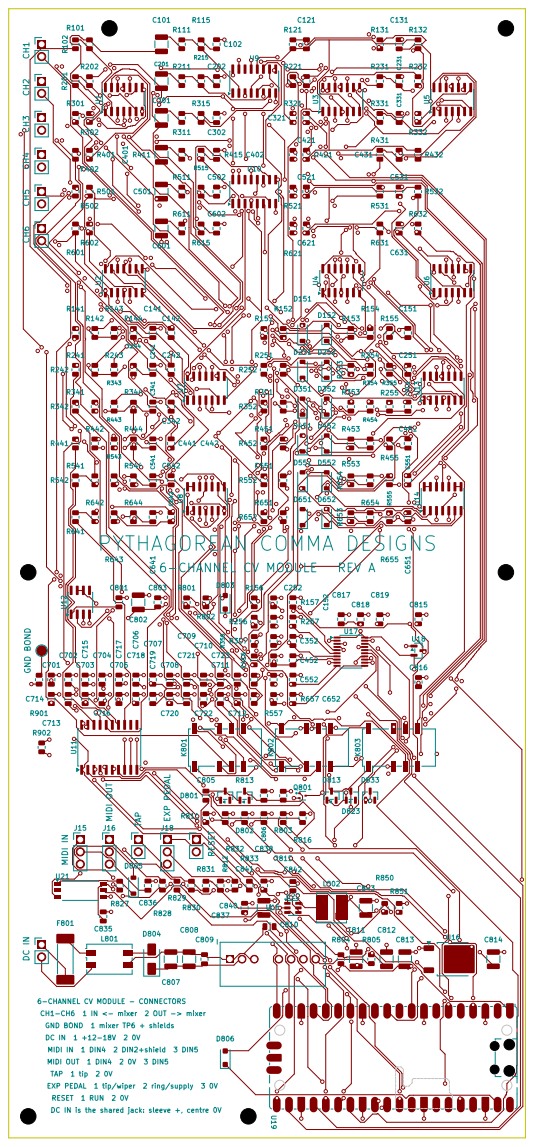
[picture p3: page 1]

TAP 1 tip 2 0V RESET 1 RUN 2 0V DC IN 1 +12-18V 2 0V MIDI OUT 1 DIN4 2 0V 3 DIN5 GND BOND 1 mixer TP6 + shields 6-CHANNEL CV MODULE - CONNECTORS CH1-CH6 1 IN <- mixer 2 OUT -> mixer MIDI IN 1 DIN4 2 DIN2+shield 3 DIN5

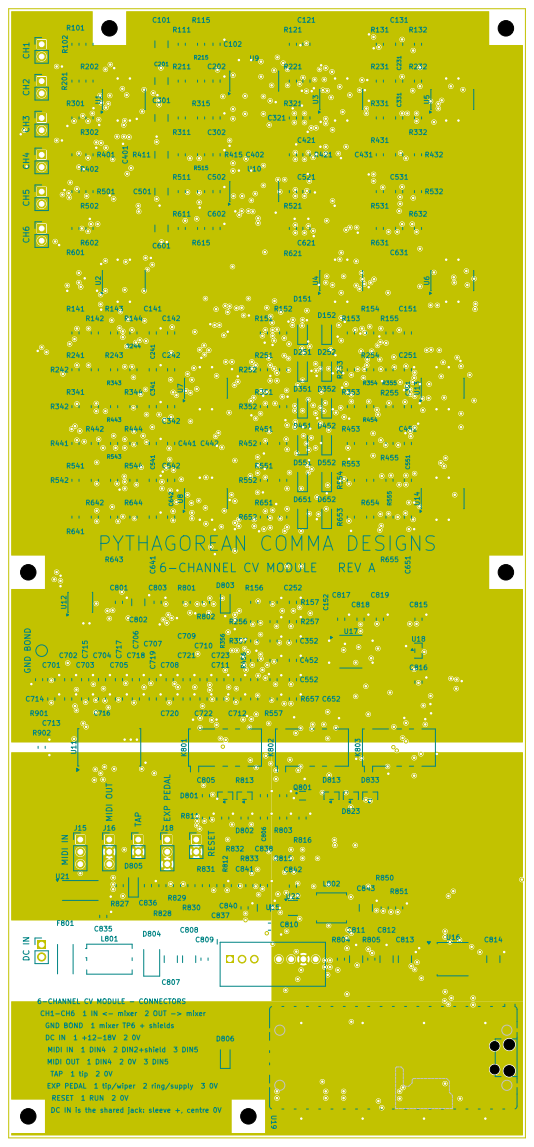
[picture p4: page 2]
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

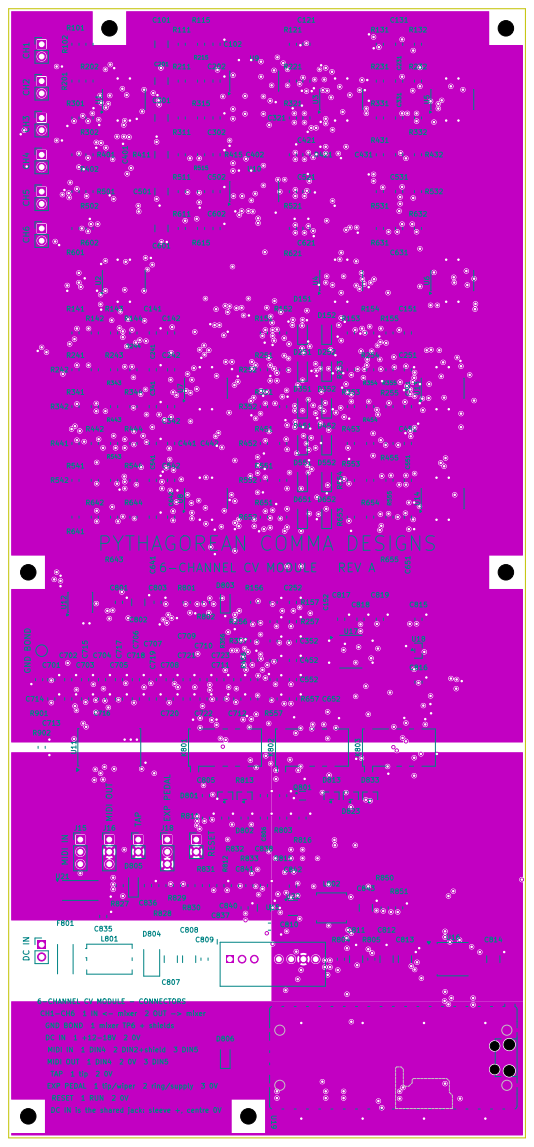
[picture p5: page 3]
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

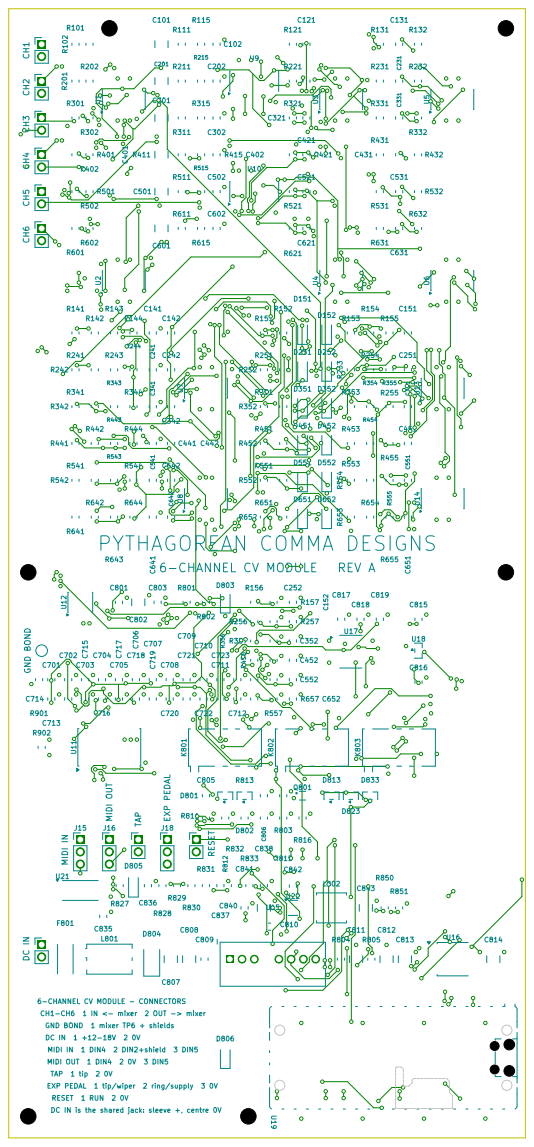
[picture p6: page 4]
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

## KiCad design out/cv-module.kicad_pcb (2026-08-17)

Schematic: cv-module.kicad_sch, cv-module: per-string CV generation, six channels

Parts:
C101, C201, C301, C401, C501, C601, C802: 10u/16V X7R; C_1210_3225Metric
C102, C202, C302, C402, C502, C602: 1200p/50V C0G; C_0805_2012Metric
C121, C221, C321, C421, C521, C621: 100p/50V C0G; C_0805_2012Metric
C131, C231, C331, C431, C531, C631: 150n/50V X7R; C_0805_2012Metric
C141, C241, C341, C441, C541, C641: 56n/50V X7R; C_0805_2012Metric
C142, C242, C342, C442, C542, C642: 22n/50V X7R; C_0805_2012Metric
C151, C251, C351, C451, C551, C651: 470n/50V X7R; C_0805_2012Metric
C701, C702, C703, C704, C705, C706, C707, C708, C709, C710, C711, C712, C713, C714, C715, C716, C717, C718, C719, C720, C721, C722, C723, C724, C803: 100n/50V X7R; C_0805_2012Metric
C801: 100n/50V C0G; C_0805_2012Metric
C805: 2n2/50V C0G; C_0805_2012Metric
C806: 1u/16V X7R; C_0805_2012Metric
D151, D152, D251, D252, D351, D352, D451, D452, D551, D552, D651, D652: 1N4148W; D_SOD-123
D801, D802, D803, D813, D823, D833: BAT54; D_SOD-123
J1: CH1; PinHeader_1x02_P2.54mm_Vertical
J2: CH2; PinHeader_1x02_P2.54mm_Vertical
J3: CH3; PinHeader_1x02_P2.54mm_Vertical
J4: CH4; PinHeader_1x02_P2.54mm_Vertical
J5: CH5; PinHeader_1x02_P2.54mm_Vertical
J6: CH6; PinHeader_1x02_P2.54mm_Vertical
J7: BOND; TestPoint_Pad_D2.0mm
J8: PWR; PinHeader_1x05_P2.54mm_Vertical
J9: CTRL; PinHeader_1x05_P2.54mm_Vertical
J10: CTRL2; PinHeader_1x05_P2.54mm_Vertical
J11: CTRL3; PinHeader_1x05_P2.54mm_Vertical
K801, K802, K803: DPDT
Q801: None; SOT-23
R101, R102, R201, R202, R301, R302, R401, R402, R501, R502, R601, R602, R801, R802: 10k 0.1%; R_0805_2012Metric
R111, R121, R211, R221, R311, R321, R411, R421, R511, R521, R611, R621: 12k1 0.1%; R_0805_2012Metric
R115, R215, R315, R415, R515, R615: 220R 1%; R_0805_2012Metric
R131, R132, R231, R232, R331, R332, R431, R432, R531, R532, R631, R632: 1M 1%; R_0805_2012Metric
R141, R144, R241, R244, R341, R344, R441, R444, R541, R544, R641, R644: 22k 1%; R_0805_2012Metric
R142, R143, R242, R243, R342, R343, R442, R443, R542, R543, R642, R643: 17k8 1%; R_0805_2012Metric
R151, R152, R153, R155, R251, R252, R253, R255, R351, R352, R353, R355, R451, R452, R453, R455, R551, R552, R553, R555, R651, R652, R653, R655: 10k 1%; R_0805_2012Metric
R154, R254, R354, R454, R554, R654: 4k99 1%; R_0805_2012Metric
R803, R811, R812, R813, R814, R815, R816: 100k 1%; R_0805_2012Metric
R901, R902: 0R; R_0805_2012Metric
U1, U2, U3, U4, U5, U6, U7, U8: OPA1644; SOIC-14_3.9x8.7mm_P1.27mm
U9, U10: SSI2164; SOIC-16_3.9x9.9mm_P1.27mm
U11: 74AHC541; SOIC-20W_7.5x12.8mm_P1.27mm
U12: MAX6126A25; SOIC-8_3.9x4.9mm_P1.27mm
U13, U14: TL074; SOIC-14_3.9x8.7mm_P1.27mm

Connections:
AGND: J7.1, R901.2
AOUT1: D151.2 (A), D152.1 (K), U13.1
AOUT2: D251.2 (A), D252.1 (K), U13.7
AOUT3: D351.2 (A), D352.1 (K), U13.8
AOUT4: D451.2 (A), D452.1 (K), U13.14
AOUT5: D551.2 (A), D552.1 (K), U14.1
AOUT6: D651.2 (A), D652.1 (K), U14.7
BUF1: C101.1, R102.2, R151.1, R153.1, U1.1
BUF2: C201.1, R202.2, R251.1, R253.1, U1.7
BUF3: C301.1, R302.2, R351.1, R353.1, U1.8
BUF4: C401.1, R402.2, R451.1, R453.1, U1.14
BUF5: C501.1, R502.2, R551.1, R553.1, U2.1
BUF6: C601.1, R602.2, R651.1, R653.1, U2.7
CPL1: C101.2, R111.1
CPL2: C201.2, R211.1
CPL3: C301.2, R311.1
CPL4: C401.2, R411.1
CPL5: C501.2, R511.1
CPL6: C601.2, R611.1
CVN1: C142.1, R143.2, U7.2 (-)
CVN2: C242.1, R243.2, U7.6 (-)
CVN3: C342.1, R343.2, U7.9 (-)
CVN4: C442.1, R443.2, U7.13 (-)
CVN5: C542.1, R543.2, U8.2 (-)
CVN6: C642.1, R643.2, U8.6 (-)
CVX1: C141.1, R141.2, R142.1, R143.1, R144.2
CVX2: C241.1, R241.2, R242.1, R243.1, R244.2
CVX3: C341.1, R341.2, R342.1, R343.1, R344.2
CVX4: C441.1, R441.2, R442.1, R443.1, R444.2
CVX5: C541.1, R541.2, R542.1, R543.1, R544.2
CVX6: C641.1, R641.2, R642.1, R643.1, R644.2
ENV1: C151.2, R155.2, U2.8
ENV2: C251.2, R255.2, U2.14
ENV3: C351.2, R355.2, U4.8
ENV4: C451.2, R455.2, U4.14
ENV5: C551.2, R555.2, U6.8
ENV6: C651.2, R655.2, U6.14
ENVN1: C151.1, R153.2, R154.2, R155.1, U2.9 (-)
ENVN2: C251.1, R253.2, R254.2, R255.1, U2.13 (-)
ENVN3: C351.1, R353.2, R354.2, R355.1, U4.9 (-)
ENVN4: C451.1, R453.2, R454.2, R455.1, U4.13 (-)
ENVN5: C551.1, R553.2, R554.2, R555.1, U6.9 (-)
ENVN6: C651.1, R653.2, R654.2, R655.1, U6.13 (-)
FEN1: R101.2, R102.1, U1.2 (-)
FEN2: R201.2, R202.1, U1.6 (-)
FEN3: R301.2, R302.1, U1.9 (-)
FEN4: R401.2, R402.1, U1.13 (-)
FEN5: R501.2, R502.1, U2.2 (-)
FEN6: R601.2, R602.1, U2.6 (-)
FSAC: C805.2, D801.1 (K), D802.2 (A)
FSD: D813.2 (A), D823.2 (A), D833.2 (A), K801.A2, K802.A2, K803.A2, Q801.3 (D)
FSDRV: C805.1, J11.5
FSG: C806.1, D802.1 (K), Q801.1 (G), R803.1
HW1: D152.2 (A), R152.2, R154.1
HW2: D252.2 (A), R252.2, R254.1
HW3: D352.2 (A), R352.2, R354.1
HW4: D452.2 (A), R452.2, R454.1
HW5: D552.2 (A), R552.2, R554.1
HW6: D652.2 (A), R652.2, R654.1
HWN1: D151.1 (K), R151.2, R152.1, U13.2 (-)
HWN2: D251.1 (K), R251.2, R252.1, U13.6 (-)
HWN3: D351.1 (K), R351.2, R352.1, U13.9 (-)
HWN4: D451.1 (K), R451.2, R452.1, U13.13 (-)
HWN5: D551.1 (K), R551.2, R552.1, U14.2 (-)
HWN6: D651.1 (K), R651.2, R652.1, U14.6 (-)
IIN1: R111.2, R115.1, U9.2 (I_IN1)
IIN2: R211.2, R215.1, U9.7 (I_IN2)
IIN3: R311.2, R315.1, U9.10 (I_IN3)
IIN4: R411.2, R415.1, U10.2 (I_IN1)
IIN5: R511.2, R515.1, U10.7 (I_IN2)
IIN6: R611.2, R615.1, U10.10 (I_IN3)
IOUT1: C121.1, R121.1, R132.2, U3.2 (-), U9.4 (I_OUT1)
IOUT2: C221.1, R221.1, R232.2, U3.6 (-), U9.5 (I_OUT2)
IOUT3: C321.1, R321.1, R332.2, U3.9 (-), U9.12 (I_OUT3)
IOUT4: C421.1, R421.1, R432.2, U3.13 (-), U10.4 (I_OUT1)
IOUT5: C521.1, R521.1, R532.2, U4.2 (-), U10.5 (I_OUT2)
IOUT6: C621.1, R621.1, R632.2, U4.6 (-), U10.12 (I_OUT3)
IVOUT1: C121.2, K801.14, R121.2, R131.1, U3.1
IVOUT2: C221.2, K801.24, R221.2, R231.1, U3.7
IVOUT3: C321.2, K802.14, R321.2, R331.1, U3.8
IVOUT4: C421.2, K802.24, R421.2, R431.1, U3.14
IVOUT5: C521.2, K803.14, R521.2, R531.1, U4.1
IVOUT6: C621.2, K803.24, R621.2, R631.1, U4.7
LOGO1: R141.1, U11.18 (Y0)
LOGO2: R241.1, U11.17 (Y1)
LOGO3: R341.1, U11.16 (Y2)
LOGO4: R441.1, U11.15 (Y3)
LOGO5: R541.1, U11.14 (Y4)
LOGO6: R641.1, U11.13 (Y5)
MAGND: C102.2, C141.2, C202.2, C241.2, C302.2, C341.2, C402.2, C441.2, C502.2, C541.2, C602.2, C641.2, C701.2, C702.2, C703.2, C704.2, C705.2, C706.2, C707.2, C708.2, C709.2, C710.2, C711.2, C712.2, C713.2, C714.2, C715.2, C716.2, C717.2, C718.2, C719.2, C720.2, C721.2, C722.2, C723.2, C724.2, C801.2, C802.2, C803.2, D803.1 (K), J8.3, R901.1, R902.1, U1.3 (+), U1.5 (+), U1.10 (+), U1.12 (+), U2.3 (+), U2.5 (+), U2.10 (+), U2.12 (+), U3.3 (+), U3.5 (+), U3.10 (+), U3.12 (+), U4.3 (+), U4.5 (+), U4.10 (+), U4.12 (+), U5.3 (+), U5.5 (+), U5.10 (+), U5.12 (+), U6.3 (+), U6.5 (+), U6.10 (+), U6.12 (+), U7.3 (+), U7.5 (+), U7.10 (+), U7.12 (+), U8.3 (+), U8.5 (+), U8.10 (+), U8.12 (+), U9.8 (GND), U9.13 (I_OUT4), U9.15 (I_IN4), U10.8 (GND), U10.13 (I_OUT4), U10.15 (I_IN4), U11.8 (A6), U11.9 (A7), U11.10 (GND), U12.3 (GND), U12.4 (GNDS), U13.3 (+), U13.5 (+), U13.10 (+), U13.12 (+), U14.3 (+), U14.5 (+), U14.10 (+), U14.12 (+)
MDGND: C806.2, D801.2 (A), J8.5, J9.1, J9.3, J9.5, J10.2, J10.4, J11.2, J11.4, Q801.2 (S), R803.2, R811.2, R812.2, R813.2, R814.2, R815.2, R816.2, R902.2
OE: J11.3, U11.1 (G1), U11.19 (G2)
PIN1: J1.1, K801.12, R101.1
PIN2: J2.1, K801.22, R201.1
PIN3: J3.1, K802.12, R301.1
PIN4: J4.1, K802.22, R401.1
PIN5: J5.1, K803.12, R501.1
PIN6: J6.1, K803.22, R601.1
PWM1: J9.2, R811.1, U11.2 (A0)
PWM2: J9.4, R812.1, U11.3 (A1)
PWM3: J10.1, R813.1, U11.4 (A2)
PWM4: J10.3, R814.1, U11.5 (A3)
PWM5: J10.5, R815.1, U11.6 (A4)
PWM6: J11.1, R816.1, U11.7 (A5)
RCJ1: C102.1, R115.2
RCJ2: C202.1, R215.2
RCJ3: C302.1, R315.2
RCJ4: C402.1, R415.2
RCJ5: C502.1, R515.2
RCJ6: C602.1, R615.2
RINV: R801.2, R802.1, U8.9 (-)
SIN1: J1.2, K801.11
SIN2: J2.2, K801.21
SIN3: J3.2, K802.11
SIN4: J4.2, K802.21
SIN5: J5.2, K803.11
SIN6: J6.2, K803.21
SPARE0: U8.13 (-), U8.14
SPARE1: U14.8, U14.9 (-)
SPARE2: U14.13 (-), U14.14
SRV1: C131.2, R132.1, U5.1
SRV2: C231.2, R232.1, U5.7
SRV3: C331.2, R332.1, U5.8
SRV4: C431.2, R432.1, U5.14
SRV5: C531.2, R532.1, U6.1
SRV6: C631.2, R632.1, U6.7
SVN1: C131.1, R131.2, U5.2 (-)
SVN2: C231.1, R231.2, U5.6 (-)
SVN3: C331.1, R331.2, U5.9 (-)
SVN4: C431.1, R431.2, U5.13 (-)
SVN5: C531.1, R531.2, U6.2 (-)
SVN6: C631.1, R631.2, U6.6 (-)
V5: D813.1 (K), D823.1 (K), D833.1 (K), J8.4, K801.A1, K802.A1, K803.A1, U12.2 (IN)
VA+: C701.1, C703.1, C705.1, C707.1, C709.1, C711.1, C713.1, C715.1, C717.1, C719.1, C721.1, C723.1, J8.1, U1.4 (V+), U2.4 (V+), U3.4 (V+), U4.4 (V+), U5.4 (V+), U6.4 (V+), U7.4 (V+), U8.4 (V+), U9.16 (V+), U10.16 (V+), U13.4 (V+), U14.4 (V+)
VA-: C702.1, C704.1, C706.1, C708.1, C710.1, C712.1, C714.1, C716.1, C718.1, C720.1, C722.1, C724.1, J8.2, U1.11 (V-), U2.11 (V-), U3.11 (V-), U4.11 (V-), U5.11 (V-), U6.11 (V-), U7.11 (V-), U8.11 (V-), U9.9 (V-), U10.9 (V-), U13.11 (V-), U14.11 (V-)
VC1: C142.2, R142.2, U7.1, U9.3 (VC1)
VC2: C242.2, R242.2, U7.7, U9.6 (VC2)
VC3: C342.2, R342.2, U7.8, U9.11 (VC3)
VC4: C442.2, R442.2, U7.14, U10.3 (VC1)
VC5: C542.2, R542.2, U8.1, U10.6 (VC2)
VC6: C642.2, R642.2, U8.7, U10.11 (VC3)
VNR: C801.1, U12.1 (NR)
VREF: C802.1, C803.1, R801.1, U11.20 (VCC), U12.6 (OUTS), U12.7 (OUTF)
VREFN: D803.2 (A), R144.1, R244.1, R344.1, R444.1, R544.1, R644.1, R802.2, U8.8

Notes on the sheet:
The boundary runs through U11: A-side from the digital domain, Y-side precision analogue, GND on MAGND. See floorplan.py.
Fail-safe: any stuck MCU state collapses the pump, the FET releases, and de-energised is bypass. D803 covers the one path the pump cannot see. See design.fail_safe().
R901 is THE bond, to the mixer's TP6. R902 is internal. Constraint 2 allows exactly one of the first.

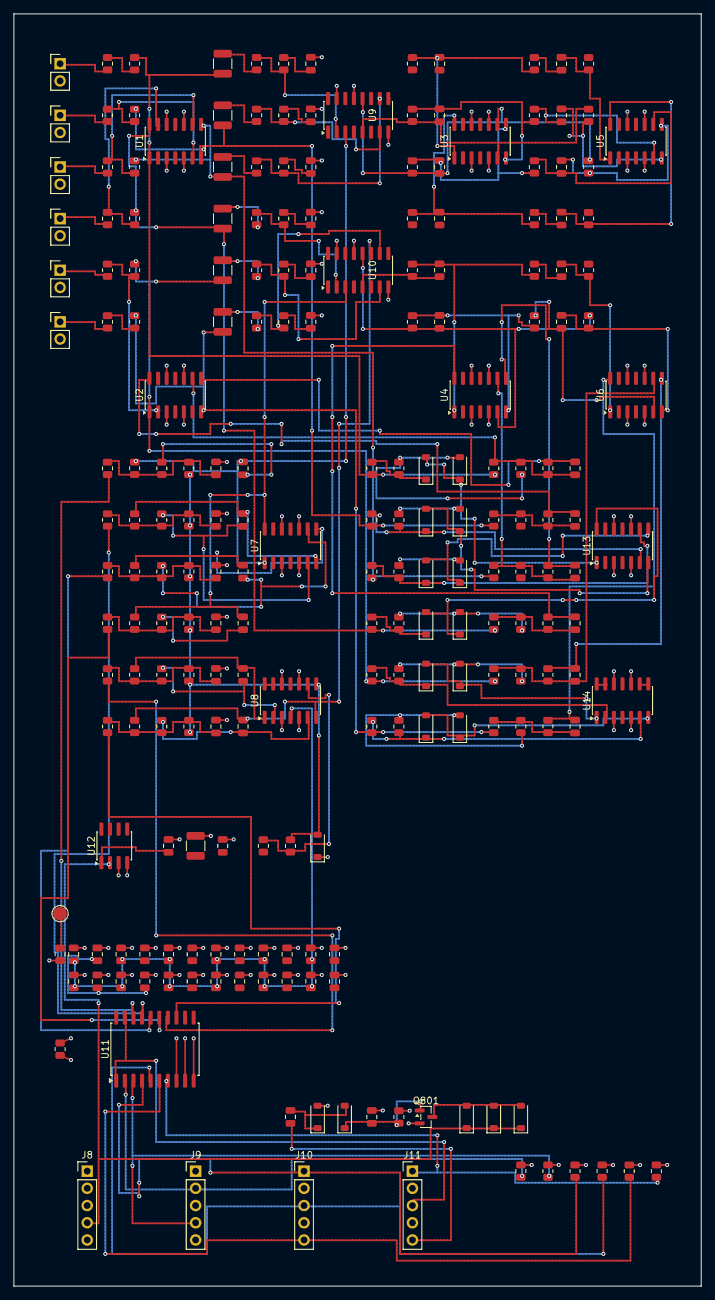
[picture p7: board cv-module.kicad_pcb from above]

Board: 4 copper layers, 101.4 x 187.8 mm, 222 parts (0 on the bottom side), 138 nets.

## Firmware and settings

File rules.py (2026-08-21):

"""The fabrication rules, and the arithmetic that decides them.

Stdlib only and no KiCad, for the reason placement.py and route.py have none:
a rule that can only be read inside the interpreter that enforces it is a rule
nobody can check.

**This file exists because two other files each said the rules lived in the
other one.** gen_pcb.py carried the constants and said "gen_project.py imports
them so the two cannot disagree"; gen_project.py said "No board design rules
... gen_pcb.py, when it exists, is where the rules go", and wrote its own
track width, clearance and via sizes as literals in net_classes(). Neither
imported anything from the other, and neither could: importing gen_pcb.py
relaunches it under KiCad's interpreter, which is what the top of that file
does before anything else runs. So the numbers agreed by coincidence and by
one person having typed them twice.

Worse, gen_pcb.py named `check_rules()` in verify.py as the thing that "stops
the discipline from decaying into a comment", and **there was no check_rules()
in verify.py.** Nothing in this repository has ever been more exactly its own
named failure mode: a check cited and never written, holding together two
files that did not import each other, described in a docstring that read as
though somebody had already done it. There is one now, and it reads the
project and the board off disk rather than reading this module twice.

The mixer keeps its own rules in a rules.py that gen_project.py reads, and
gen_project.py here already cited that file's existence. This is that file.

---

**The fabricator, read first-hand rather than assumed.** JLCPCB's published
capabilities, https://jlcpcb.com/capabilities/pcb-capabilities, read
2026-08-17. The rows that bear on this board, quoted:

  * minimum trace width / spacing, 1 oz outer copper:
    *"Multilayer: 0.09 / 0.09 mm (3.5 / 3.5 mil). 3 mil is acceptable in BGA
    fan-outs."*
  * minimum trace width / spacing, 2 oz outer copper:
    *"Multilayer: 0.15 / 0.15 mm (6 / 6 mil)"*
  * *"Min. Via hole size/diameter: 0.15mm / 0.25mm"*
  * and the only cost note the page attaches to any of it:
    *"0.15mm hole size with any size via diameter, and 0.2mm or 0.25mm hole
    size with via diameter less than 0.45mm, will cost more."*

**What the page does not say is what the fine-line class costs**, and that is
worth being exact about, because the question this file was written to answer
is a cost question. The page prices vias and does not price trace class; the
20 % figure for 3-3.5 mil on 4-8 layer boards that circulates in third-party
guides is not on JLCPCB's own page and is not quoted here as though it were.
What the page *does* price, in capability rather than in money, is the copper
weight: **2 oz outer copper caps the class at 0.15/0.15 mm, and reaching
0.09/0.09 means 1 oz.** That is a trade this repo can state exactly, and it is
the one escape_corridor() below turns out to hinge on.
"""

import math
import pathlib
import re

# ---------------------------------------------------------------------------
# The rules as fitted
# ---------------------------------------------------------------------------

# Outer copper weight. **Decided, and it is 1 oz.** This was a declaration
# rather than a decision for five passes -- "the rules below are chosen to be
# legal at either weight ... keeping the option costs nothing", which was true
# and ended the moment something asked for 0.09 mm. The controller asked.
#
# **The decision was taken on a measurement rather than an argument**, and the
# argument it overturned was this file's own. gen_pcb.py end to end, all four
# combinations of class and via rule:
#
#     class          via rules      time     unrouted   DRC violations
#     0.25/0.20 2oz  ring of four    89 s        0            0
#     0.09/0.09 1oz  ring of four    69 s        0           56
#     0.25/0.20 2oz  corrected      454 s       10 (V5)       0
#     0.09/0.09 1oz  corrected       89 s        0            0
#
# Only the last row is a complete, DRC-clean board. The coarse class cannot
# close the 5 V rail once via_exclusion() is modelled properly and takes five
# times as long to fail; the fine one closes everything, needs no fan-out escape
# anywhere, and runs in the same 89 seconds the coarse class used to.
#
# **What 1 oz costs is current capacity and the answer is 0.33 degrees.**
# track_current(): design.coil_budget()'s 92.7 mA on 0.09 mm of 1 oz is 0.33 C
# of rise, and 4.0 C even if the borrowed IPC-2221 constant is three times out.
# Nothing else on this board is more than microamps. The figure that made this
# look like a trade was 29 A/mm2, and current density omits the surface area
# that does the cooling -- see track_current() for why that is the wrong
# instrument.
#
# **1 oz, and the reason is that nothing on this board has ever wanted 2.**
# The weight was carried as a free option for five passes -- this file's own
# words were *"the rules below are chosen to be legal at either weight ...
# keeping the option costs nothing"* -- and it was never bought against a
# requirement. It was then spent by the RP2040's QFN, which is gone.
#
# **The only number this repo has for it says 1 oz by a factor of nothing that
# matters.** track_current() puts the largest current on the board -- 92.7 mA
# of relay coil -- at **0.088 degC of rise** on 0.20 mm of 1 oz copper, against
# 0.028 degC at 2 oz. Both are noise. There is no thermal case, no current
# case, and no mechanical case anybody here has written down.
#
# **And 2 oz would now cost something real.** PCBWay's 2 oz floor is
# 0.178/0.203 mm, so a track through the 0.67 mm corridor between two SOIC
# pins needs 0.584 mm of it and leaves **0.086 mm of total slack** to spend on
# margin. At 2 oz you choose between holding margin over the process and being
# able to route between two pins of a SOIC. At 1 oz you get both. See
# TRACK_MM.
COPPER_OZ = 1

# **0.20 mm, and the constraint that picked it is the SOIC corridor rather
# than the fabricator's floor.** Two SOIC pins leave 0.67 mm of bare laminate
# between them -- escape_corridor() -- and a track through it needs
# `track + 2 x clearance`. That is the number that separates the candidates,
# and it separates them the opposite way round from the margin figures:
#
#     class        w + 2c   through a SOIC?   over PCBWay's 1 oz floor
#     0.20/0.20    0.600    yes, 0.07 spare   track +57 %, space +32 %
#     0.25/0.25    0.750    **no**            track +97 %, space +64 %
#
# So the coarser class has more margin over the process and cannot pass
# between two pins of a SOIC, on a board with a SOIC-20W, two SOIC-16, several
# SOIC-14 and a SOIC-8 on it. 0.20/0.20 holds a third to a half of margin
# everywhere *and* keeps the corridor, which is why it wins.
#
# **It is a 1 oz class and only a 1 oz class.** At 2 oz PCBWay's spacing floor
# is 0.203 mm, so 0.20 is 1.5 % under it -- close enough to read as fine and
# it is not. Said here because "0.20/0.20 on 1 oz or 2 oz" was written down
# once in this project and was wrong.
#
# The three values this has been are each right about the board they were on:
# 0.25/0.20 while every package was a SOIC and the fabricator was assumed to
# be JLCPCB, 0.09/0.09 while a 0.40 mm QFN-56 had to be reachable by a maze
# router, and 0.20/0.20 now that the controller is a 2.54 mm module, the board
# is hand-laid, and the fabricator has been asked.
TRACK_MM = 0.20

# **POWER_TRACK_MM was here at 0.5 mm for the whole life of the board and it
# is gone, because it was the one constant in this file with no argument
# beside it.** What it had was a procedure -- "this is what a rail is widened
# to when somebody widens one" -- and nobody ever did, so no copper was ever
# 0.5 mm wide. verify.check_rules() asserts the board carries exactly one
# track width, which means the only instrument that mentioned the constant
# asserted its *absence*: a declaration nothing is obliged to use cannot be
# wrong, the same way zone P and RAILS["V3V3"] could not be wrong.
#
# It was forced by a router that reads net classes and would have drawn it.
# design.power_track_verdict() is the derivation that had never been done, and
# every mechanism a wider rail could address is closed by a wide margin:
#
#   heating          0.58 C of rise at VA+'s 213 mA on 0.20 mm
#   static drop      42 mV worst case, on V5, a 5 V rail
#   crosstalk        -148.8 dB against a -54 dB requirement, and -88.8 dB
#                    even if the amplifier had NO power-supply rejection
#
# Widening to 0.5 mm buys 7.96 dB on a figure with 94.8 dB of margin. The
# Power net class survives the constant, because its other field is a colour
# and a hand-routed board is worth having the rails red in the editor.

# 0.20 mm, with the track, and the pair is chosen together -- see TRACK_MM,
# where the corridor arithmetic is `track + 2 x clearance` and so cannot be
# decided one value at a time. 32 % over PCBWay's 1 oz spacing floor and 122 %
# over JLCPCB's, and DRC runs against it on every build with
# verify.check_rules() holding all three files to it.
CLEARANCE_MM = 0.20

# 0.6 mm diameter on a 0.3 mm hole. **Chosen to sit outside every surcharge the
# capabilities page names**, which is the one place that page gives a price:
# a 0.3 mm hole is neither of the two sizes it calls out, and 0.6 mm is above
# the 0.45 mm diameter below which the small holes cost more. The published
# minimum is 0.25 mm on a 0.15 mm hole and this design has no reason to go
# near it.
# **0.7 mm and not 0.6, and the 0.1 mm buys margin on the one via number that
# is a function of two others.** 0.6/0.3 is a 0.150 mm annular ring against
# PCBWay's published 0.150 mm minimum -- exactly at it, on 767 vias, and
# passing every check this file had because none of them computed the ring.
# 0.7/0.3 is 0.200 mm, a third over.
#
# What it costs is a 0.05 mm larger radius of keepout around each via, on a
# board that is 3.8x the area of the one it plugs into and is about to be
# re-placed anyway. If area ever becomes the binding constraint this is a
# cheap 0.1 mm to give back, and it should be given back deliberately rather
# than by drifting.
VIA_DIAMETER_MM = 0.7
VIA_DRILL_MM = 0.3

# Copper to board edge.
EDGE_CLEARANCE_MM = 0.3

# KiCad's own coordinate quantum: it stores board geometry in nanometres, and
# route.py rounds every grid point to 0.1 um before handing it over. Two
# roundings can therefore move a spacing by 0.2 um, which is why PITCH_MARGIN
# below is not allowed to be zero.
COORDINATE_QUANTUM_MM = 1e-4

# ---------------------------------------------------------------------------
# The routing grid
# ---------------------------------------------------------------------------

# **The margin the grid pitch carries above the minimum that clears, and the
# correction it embodies.** gen_pcb.py used to declare the pitch as "the
# tightest pitch these rules allow and therefore the one that routes", at
# 0.5 mm. It is not: two tracks on adjacent cells are PITCH - TRACK apart, so
# the tightest pitch these rules allow is TRACK + CLEARANCE = 0.45 mm, and
# 0.5 mm is 0.05 mm of margin on top of it. The sentence was not a derivation
# with an arithmetic slip in it -- it was a derivation that had never been
# performed, stated in the voice of one that had, which is exactly the shape
# this repo keeps finding.
#
# **Keeping the margin is a decision and it has a measured price.** At 0.45 mm
# the router finishes on the sixth retry pass instead of the ninth, about 17
# seconds of build time, and 12 % more cells. What it gives up is all of the
# margin: two adjacent tracks would land at exactly 0.2 mm, which passes DRC
# only because DRC compares against `<` -- and which depends on the board
# origin landing on the 0.1 um lattice, since route.py's grid points are
# `origin + n * pitch` rounded to 0.1 um and two such roundings can differ by
# 0.2 um in the wrong direction. A rule that holds because the outline
# happened to come out on a round number is not a rule.
#
# 0.05 mm is 500x that quantum and 25 % of the clearance itself.
PITCH_MARGIN_MM = 0.05


def route_pitch(track=TRACK_MM, clearance=CLEARANCE_MM,
                margin=PITCH_MARGIN_MM):
    """The routing grid pitch, derived from the rules rather than chosen.

    Two tracks on adjacent cells are `pitch - track` apart edge to edge, and
    that has to clear `clearance`:

        pitch - track >= clearance
        pitch         >= track + clearance

    `margin` is what is carried above that floor, and PITCH_MARGIN_MM explains
    why it is not zero.
    """
    return track + clearance + margin


def via_neighbours(pitch=None, via=VIA_DIAMETER_MM, track=TRACK_MM,
                   clearance=CLEARANCE_MM):
    """Which cells around a via are inside the clearance, orthogonal and diagonal.

    route.py has to block some ring of cells around every via it places,
    because a via is wider than a track and the uniform grid cannot express
    that on its own. Which ring is arithmetic and it used to be a comment:

        orthogonal: pitch          - via/2 - track/2
        diagonal:   pitch * sqrt 2 - via/2 - track/2

    At the fitted rules that is 0.075 mm orthogonally, a third of the
    clearance, and 0.28 mm diagonally, which clears. Blocking all eight was the
    cautious version and it cost 27 nets, because a SOIC pin's diagonals are
    always somebody's clearance ring and so no via could ever be placed at a
    package pin.
    """
    pitch = route_pitch() if pitch is None else pitch
    reach = via / 2 + track / 2
    orthogonal = pitch - reach
    diagonal = pitch * math.sqrt(2) - reach
    return {
        "orthogonal_mm": orthogonal,
        "diagonal_mm": diagonal,
        "orthogonal_blocks": orthogonal < clearance,
        "diagonal_blocks": diagonal < clearance,
    }


# ---------------------------------------------------------------------------
# The escape corridor: the question the routing pass was left with
# ---------------------------------------------------------------------------

# Read first-hand out of KiCad's own footprint rather than off a datasheet
# drawing, because the router blocks what KiCad places and not what JEDEC
# draws. Package_SO.pretty/SOIC-14_3.9x8.7mm_P1.27mm.kicad_mod, pad 1:
#     (at -2.475 -3.81) (size 1.95 0.6)
# so the pads are 0.6 mm across on a 1.27 mm pitch, and the same numbers hold
# for the SOIC-8, SOIC-16 and SOIC-20W on this board.
SOIC_PIN_PITCH_MM = 1.27
SOIC_PAD_WIDTH_MM = 0.6


def escape_corridor(track=TRACK_MM, clearance=CLEARANCE_MM,
                    pin_pitch=SOIC_PIN_PITCH_MM, pad_width=SOIC_PAD_WIDTH_MM):
    """Can a routing cell exist *between* two pins of a SOIC? Arithmetic, not taste.

    This is the question the first routing pass ended on, and it was left as a
    choice between "a finer grid with thinner track" and "rip-up and retry"
    without either being priced. Here is the price.

        gap    = pin_pitch - pad_width                 the copper-free space
        window = gap - 2 * (clearance + track / 2)     legal track centres
        floor  = track + clearance                     the finest legal pitch

    A track centred anywhere in `window` clears both pads. But the grid's phase
    against the pads is arbitrary -- pads are placed by placement.py and the
    grid is anchored to the board outline -- so a cell only *reliably* falls in
    that window when the window is at least a whole pitch wide. Hence

        fits  <=>  window >= floor  <=>  gap >= 3 * clearance + 2 * track

    which is the whole decision in one line, and it does not mention the pitch
    at all: **no grid, however fine, buys the corridor if the class is too
    coarse, and any grid at the floor buys it if the class is fine enough.**

    At the fitted 0.25 / 0.20 the window is 0.02 mm against a 0.45 mm floor.
    That is not "a fine enough grid would find it" -- it is 4 % of the coarsest
    legal cell, and the 0.5 mm grid was never the reason.
    """
    gap = pin_pitch - pad_width
    window = gap - 2 * (clearance + track / 2)
    floor = track + clearance
    return {
        "gap_mm": gap,
        "window_mm": window,
        "floor_mm": floor,
        "fits": window >= floor,
    }


# The ADC's package, and it is the one on this board with no corridor at all.
# TSSOP-20 at 0.65 mm pitch on 0.40 x 1.475 mm pads, read off KiCad's own
# footprint: the copper-free gap between two pins is 0.25 mm, and
# escape_corridor() wants 3 x clearance + 2 x track. At the fitted class that
# is 1.10 mm and at the finest class this board could be ordered at -- 1 oz,
# 0.09/0.09 -- it is 0.45. **Neither fits, and the window is negative at both**
# (-0.40 mm and -0.02 mm), so there is not even a legal track *centre* between
# two pins, let alone a grid cell that reliably lands on one.
#
# That is a stronger statement than the SOIC's and it is not a problem: a
# 20-pin part whose pins all escape outward needs no corridor. What it needs
# is room outside the package, which is placement.SUPPLY's note at U17 and
# cost three unrouted nets to learn.
TSSOP_PIN_PITCH_MM = 0.65
TSSOP_PAD_WIDTH_MM = 0.40

# **The finest pitch this project has had to price, and it is the RP2040's.**
# Read off KiCad's own footprint rather than the datasheet drawing, for the
# reason the SOIC's numbers are:
# Package_DFN_QFN.pretty/QFN-56-1EP_7x7mm_P0.4mm_EP3.2x3.2mm.kicad_mod, pad 1:
#     (at -3.4375 -2.6) (size 0.875 0.2)
# so 0.20 mm pads on a 0.40 mm pitch, which leaves 0.20 mm of copper-free gap
# between two pads -- exactly this board's clearance, and the reason the
# footprint itself is DRC-legal here at all. RP2040 ships in no other package.
QFN_PIN_PITCH_MM = 0.40
QFN_PAD_WIDTH_MM = 0.20

def pad_reach(pin_pitch=TSSOP_PIN_PITCH_MM, pad_width=TSSOP_PAD_WIDTH_MM,
              grid=None, clearance=CLEARANCE_MM):
    """Can a routing cell exist *inside* a pad? One line further out than
    escape_corridor(), and the answer for a TSSOP is no.

    escape_corridor() asks whether a track can pass *between* two pins. This
    asks whether a track can *start* on one. A uniform grid reaches a pad only
    if some cell centre falls inside it, and a pad narrower than the grid pitch
    holds a cell at some phases and not at others:

        holds a cell always  <=>  pad_width > grid

    and the pad cannot be made as wide as one likes, because two adjacent pads
    are two nets:

        pad_width <= pin_pitch - clearance

    Put together, **a package is reachable at every phase only if
    pin_pitch > grid + clearance**. At the fitted 0.5 mm grid and 0.2 mm
    clearance that is 0.70 mm. A SOIC's 1.27 clears it by 0.57; a TSSOP's 0.65
    misses it by 0.05, and there is nothing to be done about the 0.05 on this
    router: a wider pad breaks clearance and a finer grid breaks the copper
    weight (see escape_corridor()).

    **Nor can the stub reach out to the nearest cell.** That cell is between
    0.20 and 0.25 mm from the pad centre, so a track of TRACK_MM laid to it
    reaches within 0.075 mm of the neighbouring pad against a 0.2 mm rule.
    The excursion is not small, it is illegal.

    So what is left is choosing *which* pads lose. `phases` is how many of the
    pad rows hold a cell at the best and worst phase, and for a package whose
    pin pitch and grid share a common divisor the pattern repeats -- for 0.65
    against 0.5 the offsets are all ten multiples of 0.05, and two rows always
    land outside. design.ENV_ADC_CHANNEL spends that on the ADC's two grounded
    channels. **That is no longer load-bearing and the note is kept for the
    arithmetic**: the fan-out closes the pads that lose, so which two rows they
    are is free again. See track_offset_limit(), and route.Grid.escape() in
    the history -- route.py has been deleted twice now and this arithmetic has
    outlived it both times, because it is what a *package* is chosen against
    and that question outlives whichever router is drawing.
    """
    grid = route_pitch() if grid is None else grid
    widest = pin_pitch - clearance
    return {
        "pin_pitch_mm": pin_pitch,
        "pad_width_mm": pad_width,
        "grid_mm": grid,
        "widest_pad_mm": widest,
        "needed_pitch_mm": grid + clearance,
        "reachable_at_every_phase": pin_pitch > grid + clearance,
        "short_by_mm": max(0.0, grid + clearance - pin_pitch),
        # What a stub to the nearest cell would leave, against the clearance.
        "stub_to_neighbour_mm": (pin_pitch - pad_width / 2 - grid / 2
                                 - TRACK_MM / 2),
        "clearance_mm": clearance,
    }
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

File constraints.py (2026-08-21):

"""Test each of the five load-bearing constraints for a mechanism.

CLAUDE.md lists five constraints under "check these mechanically, not by eye".
One of them -- constraint 2's "six separate returns" -- turned out to have no
mechanism at all: it was generated in an earlier session, promoted into that
list, and then satisfied, asserted and negative-tested by every instrument
downstream without anyone asking whether the requirement was reachable from
physics. See design.FRONT_R.

Being in that list is what made it unquestionable. So this file asks the same
question of the other four, and the question is not "is the constraint
satisfied" -- verify.py already answers that -- but:

    1. is there a mechanism, and what is it?
    2. what does the arithmetic say the threshold should be?
    3. how much margin does the design have against it?

A constraint with a mechanism and thin margin is load-bearing and belongs in
that list. A constraint with a mechanism and 40 dB of margin is good practice
and does not. A constraint with no mechanism should be struck, as 2b was.

    python3 constraints.py

**The estimates here are rougher than the rest of the repo and that matters
for how they are read.** Loom capacitances are per-unit-length figures for a
geometry nobody has built; the threshold for DC through a potentiometer wiper
is not sourced at all. Where a margin comes out at 40 dB a rough estimate is
enough to settle the question. Where it came out at 2 dB it would not be, and
the one place that nearly happened is recorded below.
"""

import math
import pathlib
import re
import statistics

import design
import delta
import placement
import rules
import contract.socket as socket
from contract.socket import source
from toolchain import sexp

# Hoisted out of write(), where it was built inline with __import__("pathlib")
# and named OUT while every other generator's OUT means the machine-readable
# directory. One name, one meaning: this file's only output is a document.
DOCS = pathlib.Path(__file__).resolve().parent / "docs"
# The board this file measures trace adjacency on. Read, never written: the
# only thing here that needs geometry is board_coupling(), and it needs the
# copper as laid rather than as designed -- the same argument verify.py makes
# for reading KiCad's netlist instead of design.py.
BOARD = pathlib.Path(__file__).resolve().parent / "out" / "cv-module.kicad_pcb"

# ---------------------------------------------------------------------------
# Loom geometry, assumed
# ---------------------------------------------------------------------------
# Neither figure is measured. They are ordinary values for small-gauge shielded
# cable and they are stated here rather than buried in a function because the
# shielding verdict below rests on them.
LOOM_LENGTH = 0.150                 # m, module to mixer
C_WITHIN_PAIR = 50e-12              # F/m, conductor to conductor, twisted
C_BETWEEN_PAIRS = 15e-12            # F/m, pair to adjacent pair in a bundle
C_TO_AGGRESSOR = 5e-12              # F/m, loom to a nearby switching node

# The two switching aggressors the loom runs past, and their amplitudes.
AGGRESSORS = (
    ("mixer charge pump", socket.PUMP_FREQUENCY, socket.VREG_VOLTS),
    ("module DC-DC", 300e3, design.MODULE_RAIL),
)

# What the requirement is, and where it comes from: 00-current-state.md, "For
# 40 dB of musical gate depth: per-channel depth >=47 dB, per-pair isolation
# <=-54 dB. Crosstalk remains the binding constraint."
#
# Moved to design.py, because design.rail_crosstalk() has to compare against it
# too and this file imports that one. Re-exported under the same name so every
# existing reference here still reads constraints.ISOLATION_DB.
ISOLATION_DB = design.ISOLATION_DB

SIGNAL_RMS = socket.MEASURED["channel_peak"].value / math.sqrt(2)


def pin_impedance(hz):
    """What the loom sees looking into PIN{n}, ohms.

    The number that decides the shielding verdict, and the one it is easy to
    get wrong. PIN{n} is *not* a 10 kohm node: it is the junction of this
    module's R{n}01 and the mixer's own C{n}01, and behind that capacitor is a
    Nu capsule's TLV170 output at the far end of a cable. So the node is
    R{n}01 in parallel with (the capsule's output impedance + the DC block's
    reactance), and above a few hundred hertz the capacitor is a short and the
    node is tens of ohms.

    Getting this wrong by using 10 kohm puts the crosstalk estimate at -51 dB,
    which fails the -54 dB requirement and would make shielding load-bearing.
    With the right impedance it is -113 dB. The difference is entirely which
    impedance the coupling current flows into, and it is 62 dB.
    """
    reactance = 1.0 / (2 * math.pi * hz * socket.DC_BLOCK_FARADS)
    behind = math.hypot(abs(source.output_impedance(hz)), reactance)
    return behind * design.FRONT_R_OHMS / (behind + design.FRONT_R_OHMS)


def coupling_db(hz, farads, impedance, source_volts=None):
    """Capacitive coupling of a source onto a node, in dB.

    A first-order divider: the coupled voltage is source x omega C Z while
    omega C Z is small, which it is by four orders of magnitude everywhere
    below.
    """
    fraction = 2 * math.pi * hz * farads * impedance
    if source_volts is None:
        return 20 * math.log10(fraction)
    return 20 * math.log10(source_volts * fraction / SIGNAL_RMS)


# ---------------------------------------------------------------------------
# 1. The module draws nothing from VREG, V+ or V-
# ---------------------------------------------------------------------------
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

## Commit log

2026-08-17 Updated floor plan now we have freed ourselves to build a bespoke enclosure
2026-08-17 Moved md files to docs and no longer have any depedendencies on code in the sibling mixer project
    [cv-module.kicad_sch]
2026-08-17 tidy up
    [cv-module-bom.csv, cv-module.kicad_sch]
2026-08-17 TASK — is the 2-bit coarse pad worth 52% of the board?
    [cv-module-bom.csv, cv-module.kicad_sch]
2026-08-17 envelope rectifier and fail-safe
    [cv-module-bom.csv, cv-module.kicad_pcb, cv-module.kicad_sch]
2026-08-18 Next increment
    [cv-module-bom.csv, cv-module.kicad_sch]
2026-08-18 DC_DC power
    [cv-module-bom.csv, cv-module.kicad_sch]
2026-08-18 choke and adc
    [cv-module-bom.csv, cv-module.kicad_sch]
2026-08-18 close the fan-out and settled on rp2040
2026-08-18 the controller, drawn: RP2040, and DEFERRED is empty
    The last deferred block. Both gates closed: the package by the fabrication
    class moving to 0.09/0.09 on 1 oz (a previous pass), the supply by choosing a
    part -- a TPS560430XF, and the F suffix is load-bearing.
    mcu_dcdc_light_load() puts the continuous/discontinuous boundary at 91 mA
    against this board's 87 mA maximum load, so a PFM part would never be
    continuous and its frequency would fall to 246 kHz at idle, under the >=300 kHz
    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
    [cv-module-bom.csv, cv-module.kicad_sch]
2026-08-19 the Pico, and the board stops being generated
    The controller is a Raspberry Pi Pico -- SC0915, castellated, 2.54 mm. 314
    parts and 201 nets become 289 and 184: the flash, the crystal, USB with its
    terminations and VBUS divider, twelve decoupling capacitors and the BOOT and
    SWD headers are all on the module.
    gen_pcb.py places, pours and stitches and lays no signal copper. route.py is
    deleted -- the problem it existed for went with the QFN, and what it cost was
    that the board had to be a function of design.py. The netlist is generated and
    authoritative; the board is hand-laid and verified. gen_pcb_guard refuses to
    overwrite copper a person drew, because the pass that documented that hazard in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
    [cv-module-bom.csv, cv-module.kicad_sch]
2026-08-19 seven columns clear the quads: 41 gap violations to 23
    The first pass against placement.GAP_MM, and the column pitch turned out not
    to be the subject. 4 mm gives an 0805 2.1 mm of clearance and is fine. What it
    does not account for is that a quad op-amp is 9.2 mm wide and spans two rows,
    so a column sitting beside one is beside something twelve times its own width:
    R{n}02 had 0.4 mm to U1's courtyard against the 1.5 mm a drag-solder lane
    wants. Seven columns move, none by more than 1.1 mm, solved against
    check_courtyard_gap() rather than eyeballed.
    Three other approaches were tried and reverted, and what they found is worth
    more than what they changed:
    * sweeping ROW_PITCH makes it *wors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
    [placement.py]
2026-08-19 the placement closes at zero, the fuse is fitted, and the board is seeded
    Four things this pass, and the last one found five more.
    **placement.check_courtyard_gap() is 0, from 23.** Two functions replace the
    nudging that took 41 to 23 and then to 12-with-three-overlaps: pack_east()
    lays a row west to east at required_gap(), and clear_south() stacks the seven
    bands south of the relays, each naming the one pair that sets it. The pair is
    a claim, not an assertion -- the gap check walks all 290 parts, so a band
    derived from the wrong neighbour fails and says which pair it should have
    been. It earned that within the hour. Cost: 3.6 mm of length, 1.7 of width.
    **The inlet fuse is fitted.** SCHUR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
    [cv-module-bom.csv, cv-module.kicad_sch]
2026-08-19 ten open assumptions become eight, and the +Vout threshold was wrong twice
    Bench and value work while the board is routed by hand. The netlist, the
    schematic and the board are byte-identical: nothing here disturbs routing
    in progress.
    **env_opamp_iq is closed by reading, not by measuring.** It asked what the
    plain TL074's quiescent current per amplifier is and said the row "was not
    located". It is on page 16 of SLOS080W, section 5.8 continued across a page
    break: "I_Q, quiescent current per amplifier, V_O = 0 V, no load -- 1.4 typ,
    2.5 max, mA". Both figures ENV_OPAMP_IQ_MA already carried -- one unsourced,
    one described as an envelope rather than invented precisely -- are the
    datasheet's o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
    [gen_assumptions.py, test_verify.py]
2026-08-20 DC bias modelled from the manufacturers' own curves, and two parts changed
    Run before Tim starts routing, to find out whether any capacitor needs a
    different land. **None does.** Both parts that changed keep their 1210
    footprint and differ only in body height, so the board is safe to route.
    **Nothing here modelled DC bias.** Every ceramic was declared at zero volts
    and used as though that were its value in circuit -- RAIL_FILTER_ESR's shape
    exactly: not a wrong number, a number computed without the term that
    dominates. CAP_DC_BIAS holds the manufacturers' own characterisation, read
    off TDK's product pages, not a per-class rule of thumb: derating is specific
    to a part number and a table of t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
    [cv-module-bom.csv, cv-module.kicad_pcb, cv-module.kicad_sch]
2026-08-20 the board is routed by KiCadRoutingTools, and the blocker was a stale pour
    krt.py drives the tool from the constraints this repo already owns: the routing
    layers derived from which layers carry a pour, the fabrication floor pinned from
    rules.py, a User.2 keep-out generated from the same three coordinates
    check_isolation_gap() measures, and the net scope. A whole board is three passes
    -- secondary with the keep-out, a rescue, then the primary nets -- because the
    tool's keep-out is absolute and the six primary nets live inside the region.
    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
2026-08-20 trace-to-trace coupling is measured, and it was never asked of the copper
    constraint_5() computes channel-to-channel coupling between two wires in a
    loom. Nothing has ever computed it between two traces on the board -- and trace
    adjacency is a property of the copper, so replacing route.py's seed with
    KiCadRoutingTools' board changed it and no instrument here could say by how
    much. Neither board had been measured. The gap survived because the loom is
    what the spec names.
    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
2026-08-20 the stackup is chosen, and it had never been
    out/cv-module.kicad_pcb carried no (stackup ...) block at all, so KiCad's
    defaults were in force and the dielectric height between an outer layer and the
    plane beneath it -- the number every impedance and every coupling figure on this
    board depends on -- was whatever KiCad happened to assume. Nothing failed,
    because nothing asked: no net here is impedance-controlled, so the only consumer
    was constraints.board_coupling(), and it could not quote a height. It swept a
    range instead.
    That is this repo's recurring shape once more. A value that exists only as
    somebody else's default cannot be wrong, the way RAILS["V3V3"] with no net could
    not be wrong a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
    [constraints.py, gen_pcb.py, rules.py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]
2026-08-20 the board was never hand-laid, and four files went on saying it was
    README's board row described route.py's seed -- 1652 track runs and 595 vias --
    against a board on disk that is 5121 segments and 995 vias, every millimetre of
    it laid by KiCadRoutingTools. The rule underneath was quoted in six places,
    three of them in code:
    the netlist is generated and authoritative; the board is hand-laid and
    verified.
    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
2026-08-20 the fabrication package is written, and it was a decision rather than a gate
    gen_plots.orderable() has read the gate off design.py and verify.py since it was
    written -- parts with no footprint, blocks not drawn, connections not routed --
    and it has returned nothing for two passes. That did not make a package appear,
    correctly: what was left was a choice, and the repository said so instead of
    quietly acquiring a fab/. The choice is taken. gen_fab.py writes fab/: nine
    gerbers, one combined drill file, the job file, the placement list and a
    generated ORDER.md.
    The gate is the one that was already there. orderable() is imported rather than
    restated, and KiCad's own DRC is run at the moment of w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
    [cv-module-B_Cu.gbl, cv-module-B_Mask.gbs, cv-module-Edge_Cuts.gm1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]
2026-08-21 the board carries the right lands now, and the sync cost four things
    The design fix was three part numbers and one footprint. Putting it on the board
    took a re-route, a stitch via, a rule change and a corrected command, and none of
    those was on the list. docs/footprint-audit.md records all four.
    The re-route scope had to be derived rather than guessed. Moving five diodes from
    a two-pad land to a three-pad one puts their pads under other nets' copper: DRC
    named MISO, IRQ, MOSI and PWM5 alongside the four nets the diodes are on, so the
    scope came off the report -- FSAC FSG FSD VMOD MISO IRQ MOSI PWM5 -- which is
    krt.plan()'s own rescue rule arriving in a scoped run. 71 violations and 10
    uncon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
    [cv-module-bom.csv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]
2026-08-21 three obsolete part numbers, and spares that cost more than the board
    Checked against the manufacturers rather than taken on trust, and all three
    substitutions hold. docs/footprint-audit.md carries the evidence.
    GRM216R71H223KA01D is obsolete -- Murata's life-cycle code, and RS no longer
    stocks it. TDK's CEU4J2X7R1H223K125AE is 22 nF, 50 V, X7R, 2.0 x 1.25 x 1.25 mm:
    0805, on the land already fitted.
    NCP1117DT50G is obsolete. onsemi's own ordering information puts it in 75-unit
    rails and marks the DT50RKG active on a 2500 reel -- same die, same DPAK-3, same
    fixed 5.0 V at 1 A. A carrier is the half of a part number that decides whether
    it can be bought.
    OPA1644AIDR is not obsolete, and th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
    [cv-module-bom.csv]
2026-08-21 three clamp-diode substitutes measured against the ceiling, and the MOQ is cheaper than all of them
2026-08-21 the clamp diode stays, and the 40-piece minimum is written on its BOM line
2026-08-21 six borrowed pin maps checked against their manufacturers, and all six are right
2026-08-21 the copper review: two audio nets were routed through the digital ground for no reason
    [cv-module-B_Cu.gbl, cv-module-F_Cu.gtl, cv-module.drl]
2026-08-21 the return path at every layer change: 1990.6 mm2 of loop became 367.8
    In1 and In2 carry the same two nets in the same places, so every via on
    this board changes reference plane as well as signal layer and the return
    current has to transfer between them. Nothing had ever measured how far
    the nearest ground via was, because gen_pcb.stitch_grounds() places at
    ground *pads* and had never been asked about a signal via: 22.76 mm at
    worst, 7.39 median, 6 of 217 within 2 mm.
    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
    [cv-module-B_Cu.gbl, cv-module-F_Cu.gtl, cv-module-job.gbrjob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]
2026-08-21 six fixings, and "underivable" was a claim about a dependency direction
    The board had none. The only four unplated holes on it belonged to the
    controller module's own footprint, so 106.9 x 233.1 mm carrying a 4.8 g
    converter brick, three relays and a soldered-down module had nothing to
    bolt it to anything.
    Nothing here could have said so. gen_fab.check_holes() counts the drill
    against the board's own vias and pads and agrees exactly -- a perfect
    package of a board with nothing to bolt down. placement.check_placed()
    holds the parts the netlist declares, and a mounting hole is not in a
    netlist. And the repo carried an argument *about* mounting holes all
    along -- MOUNTING_IS_ISOLATED, quoting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
    [cv-module-B_Cu.gbl, cv-module-B_Mask.gbs, cv-module-F_Cu.gtl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]
2026-08-21 the silkscreen: the board said nothing, and 250 designators were on F.Fab
    It had four Edge.Cuts lines, zero gr_text of any kind, and 29 of 296
    references on F.Silkscreen -- which did not include J1-J6, J8, J17 or
    J19. Every connector on the west edge was anonymous, so the only way to
    know which pin of J1 went back to the mixer was to read design.py. No
    title, no attribution, no revision.
    Nothing here would have noticed. A silkscreen is not in a netlist, so
    check_geometry() cannot miss it; DRC sees it only when it collides with
    something, and there was nothing to collide with; and
    gen_fab.package_layers() exports each candidate layer and drops the ones
    that draw nothing -- which is the one i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
    [cv-module-F_Silkscreen.gto]
2026-08-21 Deleted the router as we are now using KiCadRootingTools
